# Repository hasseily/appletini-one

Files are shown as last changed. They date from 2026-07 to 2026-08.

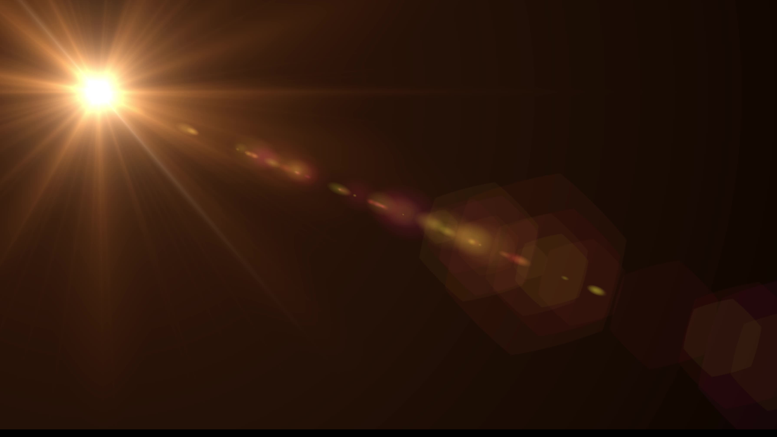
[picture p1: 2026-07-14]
Assets/Bezels/bezel-optical-lens.png

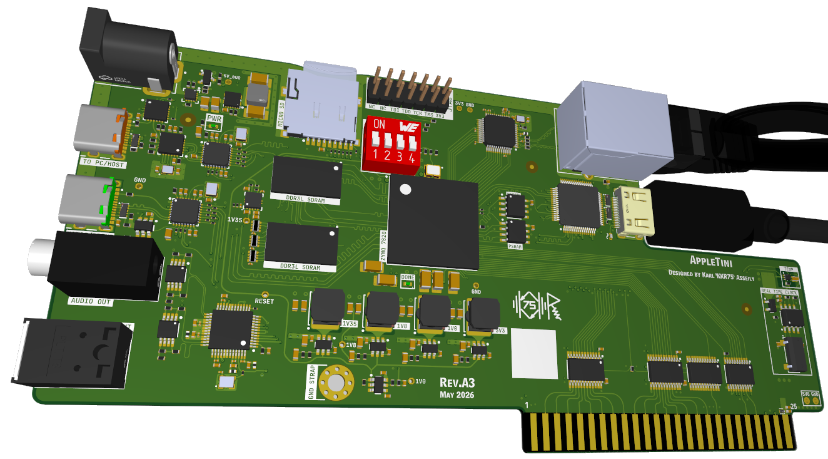
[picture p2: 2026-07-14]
Assets/Appletini_3D.png

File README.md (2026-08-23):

# Appletini One

Appletini One is firmware and FPGA logic for an Apple //e expansion card built
around a Xilinx Zynq-7020. The PL handles cycle-sensitive Apple bus behavior;
the two ARM cores provide storage, video rendering, USB services, configuration,
and higher-level peripheral emulation.

## Virtual Hardware

- SmartPort storage and Disk II disk-image support
- Selectable slot-5 coprocessor: PCPI-compatible Z80 Appli-Card or 640 KB ALF AD8088 Plus
- Phasor/Mockingboard audio with two SSI-263AP (SC-02) speech chips
- Uthernet II compatible W5100 interface
- Mouse card, RamWorks memory, and no-slot clock
- VidHD-compatible video controls and SuperSprite graphics
- Accurate Apple //e video capture, HDMI output, borders, scanlines, and profiles
- USB keyboard, mouse, storage, firmware update, and SuperDuperDisplay support

The boot menu configures virtual cards, storage images, video, audio, networking,
USB behavior, and named profiles. Settings are stored on the card's SD volume.

## Repository Layout

- `hdl/`: SystemVerilog/VHDL sources and the active source manifest
- `hdl/constraints/`: board pin and timing constraints
- `ps_sources/`: golden updater, frontend, renderer, and shared bare-metal code
- `scripts/`: Vivado, Vitis, image-generation, programming, and regression tools
- `software/`: Apple II demos, diagnostics, and disk images
- `tools/mcp/`: serial control server for automated Apple II interaction
- `Datasheets/`: hardware and compatibility references
- `third_party/`: external components with their own license terms

`project/` and `vitis_workspace/` are generated and are not source directories.

## Toolchain

- Vivado 2025.2
- Vitis 2025.2
- A compatible JTAG programmer for hardware generation or direct flash recovery
- UART access for diagnostics and serial firmware recovery

## Build

Generate the Vivado project, build the bitstream/XSA, and build all Vitis apps:

```bat
vivado -mode batch -source scripts/create_project.tcl
vivado -mode batch -source scripts/build_and_export_xsa.tcl
vitis -s .\scripts\create_vitis_workspace.py
```

Create the two flash images:

```bat
scripts\make_boot_bin.bat
scripts\make_firmware_bin.bat
```

- `BOOT.BIN` contains the FSBL and golden updater.
- `FIRMWARE.BIN` contains the FSBL, PL bitstream, CPU1 renderer, and frontend.

C-only frontend changes require a Vitis rebuild and a new `FIRMWARE.BIN`; HDL,
clock, AXI, or constraint changes require the full Vivado and Vitis sequence.

See [README_VIVADO.md](README_VIVADO.md) for hardware-build details and
[README_BOOT_UPDATE.md](README_BOOT_UPDATE.md) for the flash layout and recovery
flow. Script-specific usage is in [scripts/SCRIPTS_README.md](scripts/SCRIPTS_README.md).

## Firmware Installation

The normal update path is:

1. Put `FIRMWARE.BIN` in the root of the card's SD volume.
2. Reboot into the golden updater.
3. Let the updater program and verify the firmware slot.
4. Confirm that it renames the file to `FIRMWARE.OK` and boots the frontend.

Serial recovery is available through the golden monitor:

```bat
python scripts\serial_firmware_update.py .\FIRMWARE.BIN --port COM3 --reboot-golden
```

Direct QSPI programming scripts are available for recovery and bring-up:

```bat
scripts\program_boot.bat .\BOOT.BIN
scripts\program_firmware_slot.bat .\FIRMWARE.BIN
```

## Validation

Source-level regression scripts live in `scripts/test_*.py`. Hardware behavior
is additionally checked through UART/JTAG and the serial MCP tools. Generated
images report their firmware, golden-updater, and RTL versions at runtime so a
mixed build is visible immediately.

The Appli-Card interface and demo media are documented in
[README_APPLICARD.md](README_APPLICARD.md). Apple II software can identify the
card through the documented SmartPort interface described in
[README_APPLETINI_DETECTION.md](README_APPLETINI_DETECTION.md).

## Licensing

External components and bundled compatibility software retain their own
license and attribution files. No repository-wide license is granted by this
README.

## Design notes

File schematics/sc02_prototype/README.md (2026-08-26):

# SC-02 Prototype Schematic Archive

This folder preserves the seven-sheet SC-02 prototype schematic in open,
text-based forms.  The supplied Altium smart PDF stays here as the fixed source
record.

The conversion is automated.  It never decides that crossing lines connect.
It takes component, pin, net, and label membership from the PDF bookmark tree.

## Source record

- File: `sc-02_Final_Schematic_V1.00.pdf`
- Size: 5,080,426 bytes
- SHA-256:
  `d0e05ea01fc5e823571e140fce5ce9f12a48f1993484d683f075151382adba35`
- PDF pages: 7
- Original sheet names: `analog_1.SchDoc`, `analog_2.SchDoc`, and
  `digital_1.SchDoc` through `digital_5.SchDoc`

## Which file to use

- Use `sc02_schematic.json` for exact extracted data and source evidence.
- Use `connectivity/sc02_pin_net_memberships.csv` for a flat pin/net table.
- Use `source_svg/` for the full drawn sheets in plain XML, with searchable
  text and embedded images.
- Open `kicad/sc02_prototype.kicad_pro` for a KiCad 10 connection view.
- Use `connectivity/*.dot` or `connectivity_svg/*.svg` for component/net
  graphs.
- Use the copied PDF when the exact source rendering matters.

## What the archive contains

The canonical JSON records:

- 785 component-unit entries and 484 physical component references;
- 3,213 explicit component pins;
- 208 unique implicit package pins and all 306 of their sheet memberships;
- 1,257 sheet net entries and 1,088 distinct exact net names;
- 3,519 sheet pin/net memberships over 3,421 unique connected pin IDs;
- 718 net-label occurrences over 383 labeled sheet nets;
- 15,330 styled page-text spans;
- every component, explicit-pin, and hidden net-label tag anchor; and
- a SHA-256 over the sorted connection tuples:
  `b13d422a2b0338a3080a5e16b092374ad5afddbb8699cf532b3d418d7cdd208f`.

The PDF exposes one hidden net-label tag per labeled sheet net, not one per
drawn label.  The archive therefore keeps all 718 label occurrences, the 383
hidden tag anchors, every exact visible-text candidate, and the full styled
page text as separate facts.  Strict matching resolves 209 label positions;
509 stay marked unresolved.  The generator does not guess their positions.

## KiCad project

The KiCad files form a valid KiCad 10 project with one index sheet and seven
child sheets.  Each source component unit gets a generated generic symbol.
Each pin gets its exact source ID, pin number, net name, and implicit-pin flag
as symbol fields.  Symbol and pin placement keeps the source anchors.  A global
label sits on each pin, which gives KiCad the exact extracted net list without
drawn-wire guesses.

KiCad 10.0.5 checked a disposable copy of the project and its symbol library.
The exported XML net list contains exactly 785 components, 1,088 nets, and
3,519 nodes, with no unconnected nodes.  It also exported the index and all
seven child sheets as SVG.  `kicad_validation.json` binds that result to the
SHA-256 of the canonical JSON and a SHA-256 over all 11 KiCad files.  The
archive test checks both links, so a changed model or project cannot keep a
stale pass result.

KiCad reports two expected ERC warning classes:

- 785 off-grid warnings, because the generated symbols keep the exact PDF
  anchor positions; and
- 414 one-pin-net warnings, matching the 414 extracted nets that have one
  membership.

It also warns about annotation because 556 exact source unit names, such as
`U117A` and `C10B`, do not use KiCad's normal trailing-number form.  The archive
keeps those source names unchanged.  They are unique.

This is an electrical archive, not a recovered Altium design.  The generic
KiCad symbol bodies do not claim to restore the source symbol art, part types,
pin electrical types, or route shapes.  Use `source_svg/` for the drawn view.

## Rebuild

Run these commands from the repository root:

```powershell
python -m pip install -r scripts\requirements-sc02-schematic.txt
npm ci --prefix scripts\sc02_dot_renderer
python scripts\sc02_schematic_extract.py schematics\sc02_prototype\sc-02_Final_Schematic_V1.00.pdf --output schematics\sc02_prototype\sc02_schematic.json
python scripts\sc02_pdf_to_svg.py schematics\sc02_prototype\sc-02_Final_Schematic_V1.00.pdf --model schematics\sc02_prototype\sc02_schematic.json --output-dir schematics\sc02_prototype\source_svg
python scripts\sc02_connectivity_generate.py schematics\sc02_prototype\sc02_schematic.json --output-dir schematics\sc02_prototype\connectivity
python scripts\sc02_kicad_generate.py schematics\sc02_prototype\sc02_schematic.json --output-dir schematics\sc02_prototype\kicad
node scripts\sc02_dot_to_svg.mjs schematics\sc02_prototype\connectivity schematics\sc02_prototype\connectivity_svg
python scripts\sc02_archive_manifest.py schematics\sc02_prototype --output schematics\sc02_prototype\MANIFEST.sha256
```

The pinned packages are PyMuPDF 1.27.2.3 and `@viz-js/viz` 3.25.0, which embeds
Graphviz 14.1.3.  The DOT renderer loads that checked local package by default
and stops if its Graphviz version differs.  Another `dot -Tsvg` build can show
the DOT files, but it need not produce the same SVG bytes.

Run the archive checks with:

```powershell
python scripts\test_sc02_schematic_archive.py
python scripts\test_sc02_schematic_archive.py --regenerate
```

The second command rebuilds the JSON, source SVG, CSV/DOT, Graphviz SVG, and
KiCad files in a temporary folder and requires byte-for-byte matches.

## Limits

The smart PDF does not contain the original `.SchDoc`, Altium libraries, PCB
data, simulation models, design rules, fitted-part database, or a reliable list
of production-board changes.  It also does not turn nearby value, footprint,
or population text into typed part fields.  The archive keeps that text and the
drawn sheets, but it does not assign meaning that the PDF does not state in its
structured data.

The source sheets print historical `Q:\altium files\...` paths in their title
blocks.  The JSON and source SVG keep that visible source text on purpose.
They do not store the path of the checkout or the host that ran the extractor.

The archive cannot settle prototype-versus-production questions, such as the
final P2/R301 population, without another source.  It does remove the need to
decode the PDF again for the data that the PDF does expose.

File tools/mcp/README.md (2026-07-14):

# Appletini MCP server

Exposes a live Apple II (via the Appletini card) as MCP tools:

    MCP client -> appletini_mcp.py -> serial UART -> ARM firmware
               -> FPGA fabric -> Apple II bus

## Tools

| Tool | What it does |
| --- | --- |
| `apple2_screen_text` | The live text screen as plain text (40/80 col auto). Reads the DDR write-mirror shadow -- zero bus impact, works under graphics modes (where error messages hide). |
| `apple2_peek` | Hex dump of Apple main RAM (from the shadow; mirrors writes since power-on). |
| `apple2_soft_switches` | Decoded //e soft-switch state + RamWorks bank. |
| `apple2_machine_status` | Machine id, aux-provide, RamWorks, physical-aux-card probe, firmware status. |
| `apple2_health` | Serve-path counters (write-queue drops / deadline misses / lost cycles) -- all must be zero. |
| `apple2_bus_trace` | Recent bus cycles from the trace ring, with history offset. |
| `apple2_menu_key` | Drive the Appletini config menu remotely. |
| `apple2_console` | Escape hatch: any firmware console command (`help` lists them). |

## Setup

```
pip install mcp pyserial
```

The firmware console is a single shared channel: close any terminal
program (PuTTY, TeraTerm) holding the COM port first.

Register with Claude Code (adjust the port):

```
claude mcp add appletini -e APPLETINI_PORT=COM5 -- python tools/mcp/appletini_mcp.py
```

Or in an `.mcp.json`:

```json
{
  "mcpServers": {
    "appletini": {
      "command": "python",
      "args": ["tools/mcp/appletini_mcp.py"],
      "env": { "APPLETINI_PORT": "COM5" }
    }
  }
}
```

## Notes and limits

- `reboot`/`reset` console commands restart the Appletini firmware,
  not the Apple II.
- `apple2_menu_key` drives only the Appletini configuration menu; the MCP
  server does not inject Apple keyboard input.
- The memory shadows mirror *writes* since power-on: ROM regions and
  never-written RAM read as zero in `apple2_peek`.

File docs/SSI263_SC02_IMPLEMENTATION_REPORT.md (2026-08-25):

# Dual SSI-263 / SC-02 Phasor implementation report

## Result and scope

The branch now uses two independent SSI-263AP models for Phasor speech. The
active source closure contains no SC-01 core, ROM, coefficient set, phone map,
timing rule, decoder, Votrax interface, or compatibility path. Both speech
sockets instantiate `ssi263_voice`, which joins the native SC-02 digital core
to the ideal schematic charge model.

The sheet-5 control path now follows U37/U38 and the three timed cross-NAND
latches. PW0/PW1 are set-only states, while PW1 gates the slot-2 PW3 load of
the CTRL/TPARM1 result. The source also removes the prior
sound-driven shortcuts: it has no invented stop mask, abstract phone-class
source gate, direct ROM/inverse fricative-switch pair, guessed C381 high-pass,
or three-bit output-level shift. Source and simulation closure are complete.
The prior PW1-gate firmware still exposed an FPGA-only zero seed in the
unreset U65/U64 transitioned-inflection counters. That made the first phones
rise from the lowest pitch toward the programmed target. It is rejected.
Build `20260825T171810Z-2a4a8c64-full` supplies its replacement for the next
hardware listen.

The target version remains `F0.9.99`.

## Source basis

The implementation separates chip and card proof:

- the supplied SC-02 schematic defines the selector, transition, excitation,
  route, and ideal switched-capacitor paths;
- the supplied SSI-263 ROM defines the 64 by 8 phone table;
- the SSI-263A data sheet and programming guide define registers, public timing,
  D7, A/R, DR modes, and P/AP reset behavior;
- the original Applied Engineering Phasor manual, board photos, `mb-audit`, and
  real-card AppleWin decode define A5/A6, channel A/B, VIA, IRQ, Q3, and DIV2
  behavior.

The SC-02 reconstruction includes external changes made for its discrete board.
The chip model excludes its AD817, LM386, speaker, pots, and line-driver stages.

## SC-01 removal

The speech source closure now consists of:

```text
hdl/apple/ssi263_sc02_rom.mem
hdl/apple/ssi263_xck_ce.sv
hdl/apple/ssi263_sc02_core.sv
hdl/apple/ssi263_sc02_audio.sv
hdl/apple/ssi263_voice.sv
hdl/apple/mockingboard.sv
```

No tracked SC-01 or Votrax source file remains, and neither name appears as a
speech implementation input in `hdl/hdl_sources.txt`. VIA PCR and ORB state no
longer select a hidden SC-01/Votrax path. Software written only for an SC-01
interface will not speak through this Phasor model.

## ROM identity and addressing

The imported source is:

```text
C:\Users\hasse\OneDrive\Documents\Apple2\Appletini\Mockingboard\SC-02\ssi263a.bin
size:    2,048 bytes
CRC32:   CC0A72EE
SHA-256: 9C3BBA73319E1ED3652C85DAC19874DF04CBB72E62FDD63D6CBD7B34FF81F941
```

The active table is the first 512 bytes. The remaining 1,536 source bytes are
zero. The address is exact:

```text
rom_address = {phone[5:0], selector[2:0]}
            = ((phone & 0x3f) << 3) | (selector & 7)
```

Selectors 0-6 target F1, F2, F2 resonance, shared F3/F4, filter amplitude,
voice amplitude, and fricative amplitude. Selector 4 substitutes the host
amplitude for the upper ROM nibble. Selector 7 writes no parameter state. The
low nibble remains a set of circuit controls; the model does not turn it into
SC-01-like phone traits.

Sheet 5 gives these timed rules:

```text
decoded /PHO_WRITE is high at U29A while the phone write is active
U37 advances on U29A's falling edge at write assertion or DURCLK rise
DONE_RB holds U37 at zero while its low nibble is zero; that hold wins a clock
U38 equal = U37.low == (TPARM0 ? 2 : 6)
PW0 set = U38_equal AND WR_SEL0
PW1 set = U38_equal AND WR_SEL1
PW0/PW1 clear while /PHO_WRITE is low, otherwise hold
PW2 = selector-2 TPARM2
PW5 = NOT selector-2 TPARM2
PW3 loads (latched_CTRL OR NOT TPARM1)
    only when PW1 AND WR_SEL2; otherwise it holds
```

TPARM0 chooses the comparator delay; it does not become PW0 or PW1 data.
U38 pin 6 reaches only U32A pin 2 and U33A pin 1. PW1 from U33D pin 11
reaches U11C pin 11 and U11A pin 8, so it qualifies the U34 load independently
of U38. TPARM1 reaches PW3 through U180C/U30E/U11/U34 only on that load.
Static per-selector ROM assignments do not reproduce these held states.

U21B, U28, U29A, U36, U37, and U23B now run as the sheet-5 circuit rather
than from a phoneme-end timer. U21B Q is `RATECLK/2`; its complement clocks
U28 and U36. U28 loads `12+D`, counts only on the Q-falling half-cycle, and
holds terminal count through the Q-high half-cycle. Thus:

```text
DURCLK period = (4-D) * 256 * (16-R) effective FASTCLK ticks
frame period  =          4096 * (16-R) effective FASTCLK ticks
phoneme       = (4-D) * 4096 * (16-R) effective FASTCLK ticks
phoneme       = 16 DURCLK rises
```

U28, U36, and U37 have no phone-active or power-down clock gate. A phone
write resets U36 and drives the shared U29A level; it does not force an
unconditional U28 reload. U36 enters low-nibble `F` on its fifteenth count
after reset and requests DONE in retained frame mode. In retained phoneme
mode, the sixteenth DURCLK wraps U37 from `F` to zero and requests DONE.
Phone-write reset, CTL/power-down reset, and frame-mode WR1/WR2 acknowledge
reset U23B with priority over a same-edge request. DR=00 keeps the prior
frame/phoneme selection.

## Clock and selector correction

Both Phasor sockets assert DIV2. Original-board evidence shows SSI pin 23 tied
to the pin 24 +5 V rail on both sockets. The model feeds both XCK inputs from
Apple Q3, about 2.045 MHz, and the SSI DIV2 stage produces an effective rate of
about 1.023 MHz. A card-mode change leaves this clock alone. The Phasor's AY
clock doubling is a separate circuit and does not double SSI XCK.

The direct pin-22 Q3 trace is the only source-supported route that fits the
required raw clock with DIV2 high. A scope or continuity test can add physical
proof, but the implementation does not replace it with a tuned oscillator.

The prior selector scan included one extra divide-by-two. The corrected trace
is:

- U44A/U44B divide FASTCLK by four;
- U45 Q1 and Q2 drive the WRITE/LATCH timing gates;
- U45 Q3/Q4/Q5 drive SEL0/SEL1/SEL2;
- one selector slot spans four SLOWCLK edges, or sixteen effective FASTCLK
  ticks;
- all eight selector slots span 128 effective FASTCLK ticks.

The transition path now keeps the four storage terms drawn on sheet 4 for all
eight selectors: U89 `RESA`, U88 `RESB`, U90 `RESC`, and U87 direction carry.
An `A_CLR` setup holds A, writes `B=(target-A) mod 16`, writes `C=8`, and stores
`CY=(target>=A)`. Each later permitted pulse adds B to C. An upward transition
increments A on carry; a downward transition decrements A on no carry;
`RESA_EQUALS` stops the write path at the target.

The prototype U96 route is also explicit. Slots 0, 1, and 3 use
`TCEDGE AND U32B`; slot 2 uses `TCEDGE`; slot 4 uses
`DUREDGE AND U166B./Q AND AMP_NONZERO`; slots 5 and 6 use `PW0 AND RATEEDGE`
and `PW1 AND RATEEDGE`; slot 7 is grounded. The fitted prototype state grounds the
P2/R301 RATE=F option. A host write owns a same-edge data-path collision.

## Exact source circuit

### U60 glottal path

U60 `/RST` and CET are tied high, while U53C feeds `/VOICED` back to CEP. P0
and P1 are tied high, P2 is grounded, and P3 is tied high. U34A therefore
loads `1011` after the applicable U61/U62 edge. Normal Phi1 clocks advance
`11..15`; at 15,
`/VOICED` lowers CEP and U60 holds terminal count until the next parallel load.
There is no asynchronous clear and no free-running wrap.

U118A connects U201 to the selected C205 voice-amplitude bank at the same Phi1
boundary. The model uses U60's post-clock state for that transfer: `14->15`
selects AGND immediately, while a `15->11` load selects the positive source
immediately. This fixes the counter start, stop, and source edge from the
drawn pins; it is not a pitch or timbre setting.

U61 `/CLR` follows the physical `T/PD_/RST` net. A low level clears the two
U61 stages and removes a pending U34 load, but leaves U60 unchanged.

The drawing includes POT3 in the U3C/U117/U3B voiced-source path but gives no
wiper setting. `VOICE_TRIM_U116_STEP_Q16` keeps that one physical calibration
value explicit. Its provisional hardware-test default is `2048`, one
thirty-second of the former normalized rail step. POT3 still affects only the
drawn voiced-source path. The resistor-defined fricative source remains `301`
Q16 and no phone selects either level. A same-vector real-chip capture is still
needed to set the final wiper value.

### U75 and CD4006 U73

U75 counts on U41C rising edges. P0 is high and P1/P2/P3 are grounded. Its
terminal-load path jams one, so the steady counter sequence is `1..15`.
The post-rise counter state forms:

```text
U42C = NOT(U75.Q2 OR U75.Q3)
```

The CD4006 sections shift on the following U41C falling edge:

```text
D1 input = D3+4
D2 input = D4+5
D3 input = D2+5
D4 input = U42C XOR D1+4 XOR D2+5 XOR D4+4 XOR D4+5
```

The schematic source is D3+4, not D4+5. The final gate is:

```text
U104C     = PW3 AND U62./Q
FRICATIVE = NOT(D3+4 OR U104C)
             AND (U62./Q OR VOICE_AMP_ZERO)
```

The U41C edge advances the recurrence without `phone_active`, CTL, a decoded
phone class, or a stop flag. Voice amplitude zero and the drawn PW3/U62 term
provide the source gating.

### U68/U85 U62 reset path

The source now follows the sheet-6 amplitude counter instead of
`PW2 && !PW3` muting:

- U68 runs as a CD4029 binary counter with B/D tied high and grounded jam
  inputs;
- Q2-Q4 form `AMPCT1..3`, and their NOR is `AMPCT_ZERO`;
- `U104C = PW3 AND U62./Q`, with its inverse supplying `AMPCT0`;
- the voice- and fricative-amplitude zero terms control the shown direction and
  enable logic;
- the complete gated SEL2 level clocks U68, including a rising edge caused by
  a gate opening while SEL2 is high;
- U68 `/CO` and U104C feed U85C, whose output resets U62.

This path now decides the source envelope and U62 state. There is no special
B/D/P/T/K mute and no synthetic stop burst.

### Parameter and phase latch layers

The selector path has three distinct storage layers. U89 holds RESA for each
selector. U106-U114 follow only during that selector's LATCH window, eight
FASTCLK ticks after WRITE. U170-U176 then pass the first-stage code only while
the matching capacitor bank is grounded: F1/F3/voice in Phi0_X and
F2/F2-res/F4/fricative in Phi1_X.

U111 holds raw filter amplitude. U70 gates its four bits with
`{AMPCT3, AMPCT2, AMPCT1, AMPCT0}`, and U206 captures that result only on the
positive Phi0 edge. It does not follow later U111 or AMPCT changes in Phi0.

### U20B/U112/U166 route state

The two fricative routes are not one ROM bit and its live complement.

The gated WR_SEL2 path clocks TPARM3 into U20B. Its clock gate contains the
drawn PW0, PW1, PW2, `AMPCT_ZERO`, and `FRIC_AMP_ZERO` terms. U112 remains
transparent while Phi1_X is high and supplies `FRIC1_SW` from U20B. U166A
samples `/U20B` on the positive Phi0_X edge and holds `FRIC2_SW`. Their
different clocks preserve the route handoff drawn on sheet 7.

## Ideal switched-capacitor implementation

The model keeps one serial tract:

```text
VOICE -> F1 -> F2(+FRIC1) -> F3 -> F4 -> F5(+FRIC2) -> U146 -> U148
```

The implementation does not turn a four-switch bank into one code-to-gain
table. It keeps one source-plate voltage for each switched capacitor. For a
final switch mask `M`, source target `t`, retained plates `h[i]`, and feedback
capacitor `Cf`, one atomic topology event is:

```text
delta_out = -sum(i in M, C[i] * (t - h[i])) / Cf
h[i]      = t for i in M; every open h[i] holds
```

This covers source changes, switch changes, reset precharge, reconnects, and
multi-bit changes such as `7->8`. A code change at a steady source creates no
FRIC2 impulse; its final complementary switch mask weights the next real
source edge.

The per-switch values are copied from the drawing:

| Bank | Switched capacitors, low bit first (pF) | Fixed or feedback capacitor (pF) |
| --- | --- | ---: |
| U116 voice amplitude | 220, 430, 870, 1800 | C205=3300 |
| U157 FRIC1 amplitude | 270, 512, 1068, 2160 | C133=3900 |
| F1 frequency | 160, 330, 660, 1300 | fixed 250; feedback 11500 |
| F2 resonance | 220, 430, 870, 1800 | fixed load 200; feedback 6800 |
| F2 frequency | 280, 560, 1120, 2300 | fixed 500; feedback 6800 |
| F3 frequency | 210, 420, 820, 1640 | fixed 820; feedback 4700 |
| F4 frequency | 200, 400, 820, 1620 | fixed 1670; feedback 4300 |
| U146 filter amplitude | 76, 150, 300, 600 | C172+C173=2750 |
| U152 FRIC2 input | 270, 530, 1082, 2160 | C153=3900 |

For state `pN` at the first integrator and `yN` at the second, the phase-entry
work uses the raw capacitor equations, not rounded pole values:

```text
p1' = [11500*p1 + 2700*(y1-x) - 2700*x] / 11700
y1' = y1 - [250*(p1'-hfix) + sum F1 Ci*(p1'-hi)] / 11500

p2' = [6800*p2 + 4700*(y2-y1) + sum RES Ci*ri]
      / [7000 + sum RES Ci]
y2' = y2 - [500*(p2'-hfix) + sum F2 Ci*(p2'-hi)
            - 1000*(Lold-Lnew)] / 6800

p3' = [4700*p3 + 3900*(y3-y2) + 2000*(y1old-y1new)] / 4900
y3' = y3 - [820*(p3'-hfix) + sum F3 Ci*(p3'-hi)] / 4700

p4' = [4300*p4 + 4700*(y4-y3)] / 4500
y4' = y4 - [1670*(p4'-hfix) + sum F4 Ci*(p4'-hi)] / 4300

p5' = [3450*p5 + 4700*(y5-y4)
       - 1150*delta_C150 - 3700*delta_C151] / 3730
y5' = y5 - 4700*(p5'-hfix) / 3450
```

The mid-Phi1 C128 path applies `-5400*delta_x/11700` to F1. C127 then consumes
that same event's F1 change, not the prior event. U157 resets in Phi1 and feeds
F2 through C143 in Phi0. U152 and U154 keep state and follow their drawn
`12/13`, `19/13`, and `31/13` edge recurrences. C150 and C151 see only U152
changes while Phi1 is active; C151 keeps its source plate while its switch is
open. U146 has a 2700 pF held path plus the four filter-amplitude switches.
CLOSURE copies its completed value to U148. Phone completion does not mute or
clear the tract.

State uses a normalized signed Q16 voltage scale in wider signed registers.
Each physical division rounds once to the nearest signed integer and saturates
only at the 24-bit state rail. There are no Q14 pole or gain tables. The PCM
boundary shifts once from Q16 to signed Q15; it adds no output gain. The
removed `LINE_OUTPUT_SHIFT=3` had no schematic basis.

The card now treats this PCM value as the reconstructed low-level U148 `Line
Out` node. Each SSI socket then enters one `phasor_ssi263_output_stage` before
the PSG mixer. That stage applies a common saturating `x32` gain and registers
the result for one 7.5 ns fabric cycle. It preserves the prior voiced product:

```text
POT3:             2048
card gain:        32
voiced product:   2048 * 32 = 65536
fricative source: 301 * 32 = 9632
```

This separates the adjustable voice/noise balance from total output level.
The common stage raises the unchanged fricative path by 30.1 dB while leaving
the former voiced scale in place. It sits before the speech-plus-PSG sum, so it
cannot change AY/YM gain. The values are a hardware-test calibration, not a
claim that the schematic fixes either pot setting.

The FPGA arithmetic keeps the charge result exact for the drawn integer
capacitors. Six shared 25-by-16 signed lanes form each numerator. The only live
denominators are the 28 schematic capacitance sums. For each, a 37-bit
reciprocal product returns the exact quotient or one less; a registered
`(q+1)*d` product makes the final correction. One analog stage takes nine
fabric clocks. Phi1 and code jobs need at most 101 clocks, and the worst Phi0
job needs 110 clocks before the next event can pop. A 16-entry FIFO preserves
event order. Routed out-of-context verification at a 7.500 ns fabric period
uses 11 DSP48E1 blocks and reports `+0.641 ns` WNS. The one full-card build for
this hardware test uses 26 DSP48E1 blocks in all, including 22 for the two SSI
engines, and reports `+0.039 ns` WNS, `+0.061 ns` WHS, and `+0.265 ns` WPWS.
The current cold-pitch-seed full-card build still uses 26 DSP48E1 blocks and
reports `+0.015 ns` WNS, `+0.019 ns` WHS, and `+0.265 ns` WPWS.

The chip drawing includes C381 but omits its external load. It therefore does
not define a high-pass pole. The tract exports reconstructed U148 without the
old 255/256 digital high-pass, and the present card stage adds gain only. A
later board model may add the coupling and load response only after the load
and capture point are known.

## Original Phasor integration

The card has two fixed AP-revision instances:

| Select | Physical role | Phasor output | Request route |
| --- | --- | --- | --- |
| A5 | upper, secondary SSI socket | channel A | matching VIA CA1 in Mockingboard mode; direct IRQ in native mode |
| A6 | lower, primary SSI socket | channel B | matching VIA CA1 in Mockingboard mode; direct IRQ in native mode |

The bus and channel rules are:

- A5 writes only the channel-A chip; A6 writes only the channel-B chip;
- A5+A6 writes both chips;
- native reads expose the selected chip's D7, with A5 priority on a dual read;
- request, register, transition, excitation, filter, and audio state remain
  independent;
- Echo+ masks the SSI host route without clearing either chip;
- the FPGA maps channel A to left and channel B to right, with no speech mono
  pre-sum; the original card itself names the outputs A and B, not left/right;
- both chips use the same Q3 edge stream and asserted DIV2 strap, independent
  of Phasor mode.

The prior firmware also forced a hidden post-card warmth value of `+8` over
the complete PSG and SSI mix. That filter is not part of either schematic and
reduced speech treble before the DAC. The reset and firmware default are now
neutral (`0`). Explicit user bass, mid, treble, and volume controls remain
optional board-output processing; keep them at zero for a direct SSI listen.

## Card-enable and reset behavior

`card_enabled` now masks only the virtual card boundary:

- it blocks new host writes;
- it removes D7 and A/R from the Apple bus;
- it mutes the exported speech sample;
- it does not reset the core, source registers, counters, routes, or filter
  state.

Apple RES drives the AP `PD/RST` input. The global FPGA `rstn` still provides a
defined emulator start. Treating a menu or slot-disable flag as a die reset did
not match original wiring and has been removed.

## Removed non-schematic behavior

The current engine has none of these earlier rules:

- `stop_class` or `PW2 && !PW3` source suppression;
- `phone_voiced`, `phone_fricative`, or equivalent phone traits;
- abstract `voiced` or `fricative` gates into the audio engine;
- `phone_active` source gating or tail muting;
- an inverted D4+5 noise source tap;
- direct `FRIC1_SW=ROMbit` and `FRIC2_SW=!ROMbit` assignments;
- a 255/256 C381 high-pass estimate;
- `LINE_OUTPUT_SHIFT=3`;
- the hidden forced `+8` warmth filter;
- an asynchronous U60 clear, load-to-zero rule, or free-running terminal wrap;
- a phone-specific burst, gain, pitch, presence, or resonance adjustment.

Earlier listen-test firmware used one or more of these discarded paths. All of
those images are rejected. Their paths and hashes are intentionally absent from
this report so that none can be mistaken for the next test image.

## Deterministic power-up state

An FPGA needs known power-up bits even where the reconstructed chip circuit has
no useful reset. The model uses these repeatable seeds:

```text
U60       = F
U75       = F
U73 D1    = 0001
U73 D2    = 00000
U73 D3    = 0000
U73 D4    = 00000
U68       = 0
U20B      = 0
U28       = F
U36 low   = 0
U37 low   = 0
U65/U64   = current {I10:I6,000} target at the first transitioned CTL wake
FRIC1_SW  = 0
FRIC2_SW  = 1
filter and charge state = 0
```

These values make simulation, synthesis, and hardware runs repeatable. They do
not assert that all SSI-263AP dies start at the same unreset state. Verification
must compare the recurrence after initialization, not use the seed as proof of
silicon power-up.

U65/U64 have no reset pin in the reconstruction. Resetting them to zero in the
FPGA turned that arbitrary state into a repeatable low-to-high glide. Each
virtual die now adopts its current aligned I10:I6 target once, on the first CTL
high-to-low wake that exposes transitioned pitch. Phone writes, IS/RE writes,
later CTL wakes, and SSI `PD/RST` do not reload it. Immediate and frame modes
leave the seed armed; DR=00 consumes it only when it retains transitioned
pitch. After the one initialization edge, all rise and fall movement still
comes from the drawn U66 rate path. This is a deterministic FPGA policy for an
undefined chip power-up state, not a claimed schematic reset connection.

## Verification status

The source corrections now cover the full known digital path. Tests based on
phone classes, stop muting, or guessed C381/output terms are not proof. The
final pre-build suite now checks:

- ROM identity, padding, and all 64 by 8 addresses;
- register, D7, A/R, repeat, DR, CTL, AP reset, and collision traces;
- one-time U65/U64 cold-state initialization, five-phone fixed-pitch hold,
  later U66 rise/fall, first-wake/reset collision priority, global rearm, and
  independent staggered A5/A6 seeds;
- U44/U45 selector cadence;
- upward and downward U83/U84 DDA vectors and the full prototype U96 route;
- sheet-5 timed PW0/PW1, PW2/PW5 polarity, and PW1-gated CTRL/TPARM1 load into
  `PW3`;
- all 64 rate/duration U28 recurrences, sixteen DURCLK rises per full phone,
  U36 count-15 frame response, U37 wrap phoneme response, and reset collisions;
- U61 `PD/RST` clear without U60 clear, U60 load to 11, `11..15`, terminal hold,
  and post-clock Phi1 source selection;
- U75 rising count, U73 falling shift, post-rise U42C, feedback taps, D3+4
  source, and the full FRICATIVE gate;
- U68/U85 count, direction, terminal, and U62 reset traces;
- U20B/U112/U166 clock and hold behavior;
- all filter cap tables, ratios, signs, route histories, and persistent state;
- the `2048` POT3 setting, unchanged `301` fricative divider, exact `x32` card
  gain, both saturation edges, and immediate card-disable masking;
- no non-schematic CTL hard clamp on the source or PCM output;
- boundary-only `card_enabled` behavior;
- A5/A6 decode, both VIA CA1 paths, native IRQ, A/B isolation, and two-chip
  concurrent speech;
- source and synthesis closure with no SC-01 or Votrax implementation.

The current source checkpoint passes:

- 54 ROM, interface, formula, selector, duration, DONE, DDA, and U96 reference
  tests;
- the raw-Q3 XCK edge bench and the complete native core bench;
- 4,032 exact-divider vectors across all 28 live denominators;
- 204,210,708 checks over all 64 phone rows plus the natural ten-phone
  `HF EH1 L O OU PA E N D PA` sequence at the physical fabric/Q3/DIV2 rates;
- 15 Phasor source and decode tests;
- 17 exact card-output checks across zero, sign, gain, both saturation edges,
  and card masking;
- 77 dual-card checks for A5/A6, channel A/B, request, mode, reset, both RESA
  latch layers, row `$01`, simultaneous audio, both engine-overrun flags, and
  separate card-stage clip flags, including staggered independent pitch seeds.

The phone sweep checks the timed PW, DDA, route, and output invariants without
assuming that every settled parameter must equal its ROM target in one scan.
Source closure finds zero tracked or production SC-01/Votrax paths.

## Fidelity limits

| Area | Current claim | Limit |
| --- | --- | --- |
| ROM | Exact to the supplied binary | Does not prove the binary matches every mask-ROM revision |
| Register and timing behavior | Source-derived synchronous model with independent collision and boundary vectors | CMOS gate delay and pin captures remain unmodeled |
| Selector and transition | Drawn U44/U45 cadence, U83/U84 DDA, and prototype U96 routes | FPGA enables do not model CMOS propagation delay |
| U60/U68/U75/U73 routes | Drawn counter, gate, and held-state recurrences | Deterministic seeds are emulator choices for unreset state |
| Filter topology and ratios | Ideal schematic charge equations with one retained state per switch | Q16 voltage units and finite 24-bit state width add small numeric error |
| Source and output level | Adjustable POT3 at 1/32 rail plus common x32 per-socket card gain | Final POT3, card gain, and absolute AO voltage need a same-vector real-chip capture |
| Nonideal analog behavior | Not modeled | LF356 slew/bandwidth, CD4016 resistance and charge injection, parasitics, tolerance, temperature, and chip spread remain |
| C381 | Omitted from chip output | External load and desired capture point are not given |
| Phasor clock | Q3 plus DIV2-high source route | Pin-22 continuity or scope capture remains useful physical proof |

The ideal model can follow every shown capacitor and switch while still
differing from real silicon. Do not change a drawn ratio to hide that gap. Add
a nonideal term only when the part model and same-vector capture support it.

## Firmware and build status

The version remains `F0.9.99`. Every image before the U65/U64 cold-state fix is
rejected. The replacement comes from one clean, full, non-incremental Vivado
implementation. Its final checkpoint has positive setup, hold, and pulse-width
slack, which is the current hardware-listen gate. The normal `+0.300 ns`
release margin remains a later timing task.

```text
Current pre-build suite: passed
Current full build:      20260825T171810Z-2a4a8c64-full; run once
Source commit:           2a4a8c645c92c0340d9e7620274184e413a0641a
Build mode:              full, clean tree, no incremental reference
Route and bus skew:      PASS; 0 route errors; +5.431 ns bus-skew slack
Timing:                  WNS +0.015; WHS +0.019; WPWS +0.265 ns
Failing/unconstrained:   0 setup, hold, pulse-width, and unconstrained endpoints
Archived bit SHA-256:    1e59cd22dbed741f13f3559c6132876dda0a241c50cb4589a6ee7bd0ec50ff5c
Archived XSA SHA-256:    021f7d6e8950331515d8ed1f87645b8f046e3982ad2a73f7ca28a0a811628784
Vitis and packaging:     one run each; archived bit passed explicitly
Current F0.9.99 image:   FIRMWARE_F0.9.99_DUAL_SSI263_SC02_COLD_PITCH_SEED_WNS0p015.BIN
Firmware size:           4,264,652 bytes
Firmware SHA-256:        7e16601cb141e96ce5f7f5d986c6f089d858e29640035e4904c7fe405141318d
Hardware listen:         pending
```

The normal exporter stopped after implementation because `+0.015 ns` is below
the later `+0.300 ns` release gate. The positive-slack exporter then opened the
same final checkpoint without another implementation and recorded
`status=positive_slack_test_exported`. Bootgen identifies the archived
bitstream by name and the two frontend sections at `0x00100000` and
`0x0027c000`. The frontend ELF contains `Firmware F0.9.99`.

The rejected predecessor is build `20260825T132135Z-47003c7d-full`, source
commit `47003c7dd7dbc58b657b064161e3b5cfb2f626ca`, with WNS `+0.007 ns` and
firmware SHA-256
`1f049c469cee4be84dc5b4509cb9f34c1d4a529288c4eea2a97075da9a801f12`.
It has the corrected PW1 gate but the bad zero cold-pitch seed. Do not flash it
for this listen.

## Hardware validation for this candidate

The next Appletini test should first check that the new image boots, Phasor is
seen, both SSI chips respond, A5/A6 route to separate channels, both request
paths work, and simultaneous speech stays independent. Then listen to fixed
register vectors across voiced, fricative, mixed, and transition phones. Start
with a fixed-pitch phrase and confirm that its first five phones no longer rise
in pitch. Then use a deliberate IS target change and confirm that the normal
drawn transition still moves in both directions.

For a real-chip match, capture XCK, DIV2, A/R, D7, U150 or AO, and post-C381
audio from an original SSI-263AP Phasor with the same vectors. Measure source
level, filter peaks, width, decay, and route changes. Use those captures only
for terms absent from the schematic. Do not restore any phone-specific tweak.

The correct release claim before those captures is: two native SSI-263AP
digital models with an ideal SC-02 schematic charge model and original Phasor
card wiring, with analog hardware matching still pending.

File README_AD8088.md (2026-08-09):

# Virtual ALF AD8088 Plus

Appletini can expose one of two mutually exclusive processor cards in slot 5:
the existing PCPI-compatible Z80 Appli-Card or a virtual 640 KB ALF AD8088
Plus. Physical slot 5 must be empty. The Plus layout is a compatibility
superset of the original Processor Card and includes the documented AD128K
address range.

## Configuration

Open **Config > Slot 5 Processor**, enable slot 5, and select either:

- `Z80 Appli-Card`
- `ALF AD8088 Plus (640K)`

Changing the selection resets the selected coprocessor. Virtual TransWarp and
the AD8088 cannot run together because both own the Apple bus. The menu blocks
a live conflict, and startup turns vTW off if an old profile enables both. The
PL also refuses AD8088 memory cycles whenever vTW is enabled. AD8088 bus cycles
are deferred while Disk II is in a timing-critical motor window.

## Implementation

The PL implements the sixteen slot-5 I/O ports at `$C0D0-$C0DF`, including the
documented port-0 bit-7 handshake. Single-byte accesses use the normal DMA
path. Monitor fill and copy commands move four bytes during one DMA hold, then
release the Apple bus before the next batch. The service runs batches for up
to one millisecond per main-loop pass, so a large boot copy finishes promptly
without one long DMA hold. This keeps each hold below the 6502's 10 microsecond
register-retention limit. Each batch has a sequence number, so old completion
state cannot finish a new request. If Disk II or vTW owns the bus, the command
stays pending and retries later; it never reports success without moving the
data. A transaction stopped by such a window carries a latched blocked
verdict in BUS_STATUS, so the PS still classifies it as retryable when the
window has closed before completion is read. A running 8088 program stalls
through blocked windows like added wait states instead of failing
mid-instruction. A timeout finishes the current data phase and uses the
normal parked release before READY returns. Reset, mode change, and slot disable remain hard
boundaries that release DMA, address, and data drive.

The PS runs an 8088-instruction-compatible XTulator CPU core plus a clean-room
monitor in a dedicated 1 MB DDR arena, separate from the Z80 card's memory.
The emulated physical memory map matches the 640 KB configuration expected by
AD8088 Plus software such as Reboot Camp '83:

- `$00000-$0FFFF`: 64 KB local RAM
- `$10000-$1FFFF`: 64 KB Apple shared-memory window
- `$20000-$2FFFF`: 64 KB expansion RAM
- `$30000-$3FFFF`: unpopulated gap (reads `$FF`)
- `$40000-$BFFFF`: 512 KB expansion RAM; `$40000-$5FFFF` remains the
  original AD128K-compatible range
- `$C0000-$FEFFF`: unpopulated ROM space (reads `$FF`)

The monitor implements integer commands 29-32, floating-point commands 33-47,
user commands 48-247, SEQUENCE (`$FB`), RANDOM (`$FC`), SET MEMORY (`$FD`),
MOVE DATA (`$FE`), and far CALL (`$FF`). Original-ROM graphics/MET commands
1-28 are currently accepted as no-ops. This is a clean-room compatibility
implementation, not a copy of the original ALF PROM, so software that depends
on those original graphics routines is outside the current compatibility
scope.

## Test disks

Run `python scripts/build_ad8088_test_disks.py` to generate:

- `software/AD8088_Test.dsk` -- bootable DOS 3.3 image
- `software/AD8088_Test.po` -- bootable 800 KB ProDOS image

Both auto-run the same visible test. It checks the mailbox, an 8088 integer
monitor command, fill/copy through the AD128K-compatible range, and execution
of real 8088 code. The last stage makes the 8088 write
`8088 EXECUTED THIS LINE` directly into the Apple text page through the
shared-memory window.

The Reboot Camp disk at `software/AD8088 MSDOS.hdv` follows the manual's READY
check before each port write and waits for READY after each long monitor
command. It reads back the copied IO.SYS header before it starts the 8088 and
does not rely on a fixed delay for the 24,763-byte boot copy.

UART `8088 status` reports monitor state, command/error counts, the actual 8088
instruction count, and average instructions/second since the preceding status
request. Take two readings while an 8088 workload is active to measure its
effective speed. `8088 dump <address> <length>` displays emulated card RAM.

The vendored XTulator CPU source and its GPL-2.0-or-later notice are under
`third_party/xtulator_cpu/`.

Protocol and memory-map behavior were implemented from the
[ALF AD8088 Processor Card manual](https://mirrors.apple2.org.za/Apple%20II%20Documentation%20Project/Interface%20Cards/CPU/ALF%20AD8088/Manuals/ALF%20AD8088%20Processor%20Card%20Manual.pdf).

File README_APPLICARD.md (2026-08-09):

# PCPI Appli-Card

For the mutually exclusive ALF AD8088 Plus slot-5 personality, see
[`README_AD8088.md`](README_AD8088.md).

Appletini One provides a PCPI Appli-Card compatible Z80 coprocessor in Apple
slot 5. The Apple-visible latch protocol is implemented in PL, while the Z80
and its private memory run on the Zynq PS.

## Compatibility

- Two byte latches and two handshake flags match the PCPI card protocol.
- The embedded 2 KB v9 boot ROM is CRC-checked at firmware startup.
- Z80 memory contains 32 banks of 64 KB, for 2 MB total.
- Bank-register bits 1-3 retain GZ/80S behavior; bits 4-5 select the additional banks.
- The upper 32 KB common area maps to bank 0 when bank-register bit 6 is set.
- The Z80 interpreter supports the documented and undocumented instruction behavior
  exercised by ZEXALL.

The card has no slot ROM and no shared Apple/Z80 memory. Both processors
communicate entirely through the latch protocol, so PS execution latency does
not change Apple-visible timing.

## Apple Interface

Slot 5 uses `$C0D0-$C0DF`:

| Address | Read | Write |
| --- | --- | --- |
| `$C0D0` | Read Z80-to-6502 byte and clear its pending flag | Ignored |
| `$C0D1` | Read back the 6502-to-Z80 latch | Write a byte and set its pending flag |
| `$C0D2` | Bit 7 reports a byte pending for the Z80 | Ignored |
| `$C0D3` | Bit 7 reports a byte pending for the 6502 | Ignored |
| `$C0D4` | `$FF` | Ignored |
| `$C0D5` | Reset the Z80 and return `$FF` | Reset the Z80 |
| `$C0D6` | `$FF` | Ignored; the physical card's CTC socket is unpopulated |
| `$C0D7` | Pulse Z80 NMI and return `$FF` | Pulse Z80 NMI |
| `$C0D8-$C0DF` | `$FF` | Ignored |

Reads of `$C0D5` and `$C0D7` perform the same side effect as writes. Reset
clears both latches and flags in PL before the PS restarts the Z80.

## Z80 Interface

The I/O decoder mirrors each function across a 32-port range:

| Ports | Behavior |
| --- | --- |
| `$00-$1F` | Read back or write the Z80-to-6502 latch |
| `$20-$3F` | Read and consume the 6502-to-Z80 latch |
| `$40-$5F` | Read handshake flags |
| `$60-$7F` | Map or unmap the boot ROM |
| `$80-$BF` | Unpopulated/reserved, reads return `$FF` |
| `$C0-$DF` | Write the bank/common-area register |
| `$E0-$FF` | Ignored, reads return `$FF` |

The PL register bridge is AxiSimple slave 7 at `0x40070000`. A sequence number
is attached to each Apple-to-Z80 byte so a delayed PS acknowledgement cannot
consume a later byte.

## Firmware Controls

The **Z80 Applicard** configuration tab enables slot 5 and selects Standard or
Maximum CPU share. The settings are stored as:

```text
applicard.slot5.enabled=on|off
applicard.resource.max=on|off
```

UART commands:

```text
z80 status
z80 on|off
z80 reset
z80 budget <tstates>
z80 wall <microseconds>
z80 dump <hex-address> [length]
```

Physical slot 5 must be empty whenever the virtual card is enabled.

## Demo Media

`software/applicard/DEMOBOOT.DO` boots PCPI CP/M 2.2 through the virtual Disk II
in slot 6. `DEMOGAME.DO` contains the bundled game data disk. The directory also
contains banking and CPU-validation programs plus source media for
compatibility testing.

The embedded ROM is generated from `software/applicard/APPLICARD.ROM` by
`scripts/gen_applicard_rom_c.py`; runtime firmware never loads an SD-card ROM
override.

Run `python scripts/test_applicard_card.py` for the protocol, banking, wiring,
configuration, and service integration checks. The PL testbench is
`hdl/sim/tb_applicard_card.sv`.

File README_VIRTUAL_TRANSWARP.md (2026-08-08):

# Virtual TransWarp — Design Document

## Fixed Enhanced-//e acceleration

Accelerating presents a **fixed Enhanced //e on every host**, //e or II+.

- **Embedded CPU ROM.** The 16 KB Enhanced //e ROM (`docs/Apple2e_Enhanced.rom`
  → generated `ps_sources/frontend/apple2e_cpu_rom_data.c` via
  `scripts/gen_apple2e_cpu_rom_c.py`) is loaded into the shadow ROM region on
  every takeover (`VTW_ST_LOAD_ROM`).
- **One translate path.** The core always uses the //e MMU model. A
  II+ running the //e ROM drives the //e switches, which the private tracker
  follows.
- **Synthesized //e status reads.** `$C011–$C01F` are served internally from
  the tracked switch state without a bus cycle — a II+ has no //e IOU to
  answer them (`X_STATUS_DONE`). `$C019` RDVBLBAR uses the native VBL boundary
  at `192:0`; hardware validation showed that a vTW may be cycle accurate but
  it doesn't have the correct VBL timing. It fluctuates generally one cycle
  early.
  RDVBLBAR bit7 uses the //e AppleWin convention (1=active display, 0=vblank).
- Character ROM is the user's responsibility (Video ROM config); the built-in
  default is already a //e set. Functional coverage: `tb_vtw_video`.

Components:
- `hdl/apple/w65c02_core.sv` — cycle-exact W65C02S core (2.54 M
  SingleStepTests vectors, Klaus Dormann functional/extended/decimal/
  interrupt suites, 266 directed checks; routed standalone at 133 MHz,
  WNS +0.631 ns).
- `globals.sv::translate_apple_addr` — the //e banking translator as a
  shared function over an explicit `TranslateState`: the vTW's private
  switch copy and the motherboard tracker use one source of truth.
- `hdl/apple/vtw_shadow.sv` — 144 KB dual-port shadow (main 64K, aux 64K,
  ROM 16K; LC folded by the translator's bit-12 remap). Port B = ARM.
- `hdl/apple/vtw_bus_engine.sv` — sync-cycle FSM, 512-deep posted write
  queue (flush-before-video-window + bank-steer flush ordering),
  parked-cycle driver, PHI1-disciplined /DMA with full bus release during
  Apple RES# windows (§2 RES# row). Drives addresses at the wrapper's
  `TAP_DRIVE_ADDR` strobe (`ab_read.drive_en`, fall+8).
- `hdl/apple/vtw_core_top.sv` — core socket + private `soft_switch_manager`
  instance (synthetic serve_en pulses) + routing + CE pacing (full / divided
  / cycle-locked 1 MHz on `data_en`) + $C074 decode + ARM boot-copy port.
- `apple_top.sv` — vtw_core_top as the arbiter's 11th client; effective
  enable = config bit AND machine ∈ {//e, II/II+}, latched for the whole
  session so CTRL-RESET cannot tear a running session down. Accelerated
  sessions are always an Enhanced //e (no per-host flavor); `video_vbl`
  feeds the core's synthesized `$C019`;
  AxiSimple window 0x6C–0x7F (CTRL, auto-incrementing shadow port, ARM
  sync-cycle command/status, status/counters, bus-trail rings).
- `ps_sources/frontend/vtw_service.c` — session sequencer: waits for the
  boot ROM's machine report (//e or II/II+), takes the bus, asserts RES#
  (~100 ms) so the takeover can never land mid-protocol, invalidates
  $03F3/F4 (forces the autostart cold path; the shadow persists across
  sessions), loads the embedded Enhanced //e ROM into the shadow via the
  port-B window (`VTW_ST_LOAD_ROM`), releases the core.
- UART `vtw [status|on|off|speed full|1mhz|div <n>]` + config-menu
  "TransWarp" tab (the slot-3 presentation): enable checkbox dimmed on a
  positive non-//e identification; presets MAX / 26 / 13 / 7 / 3.6
  / 2.6 / 1 MHz cycle-exact (divided-mode dividers 5/10/19/37/51 against the
  133.333 MHz fabric clock). Persisted keys `vtw.enabled`,
  `vtw.speed.mode`, `vtw.pace.divider`, `vtw.c074.ignore`, and
  `vtw.disk2.acceleration.disabled`. RAM-tab interplay: under
  acceleration the machine always has 8MB (lives in the shadow);
- SmartPort transport state (FIFOs, exec/ready, control) clears on Apple
  RES#, on the card and via the PS sweep + hw-EXEC-gated poll
  (`tb_smartport_reset` covers it).

Operational notes:
- IRQ/NMI are sampled at the late-PHI0 data snap with a 2-consecutive-
  sample filter: bus-drive ground bounce otherwise forges IRQ edges, and
  an unenhanced //e vectors them through its internal handler.
- Parked I/O-page addresses are sanitized to $FFFF: our parked cycles are
  clean, fully-decodable replays, and a replayed $C0xx read would
  re-execute read side effects every idle cycle.
- PAL/international //e: INTCXROM=1 with PC in internal $C2xx at an idle
  prompt is the machine's NORMAL keyboard-firmware wait state (mid-KEYIN
  via the $FBB4 trampoline), not a fault signature.

## 1. Goal and governing constraint

Add a virtual accelerator to the Appletini that makes the host Apple //e run
at configurable speed (well beyond 3.58 MHz), presented in the config menu as
a slot-3 device.

**Governing constraint: the bus contract is the physical Applied Engineering
TransWarp's, verbatim.** The Appletini's capture, serving, soft-switch, and
renderer paths are hardened and hardware-validated against exactly that
master behavior — full shadow, sparse bus traffic, held /DMA.
By emitting the same *contract* (which cycles appear on the bus and what they
mean), the virtual TransWarp requires **zero changes** to every other
subsystem, and every test we ran against the physical card doubles as its
acceptance suite. Speed is the only sanctioned deviation.

One deliberate electrical improvement that does not change the contract: our
bus cycles are driven with ideal 6502 timing (address/R-W asserted early in
PHI1, held through the whole cycle, bus actively parked between accesses).
The physical TW's late assertions and early releases are the root of its
compatibility problems; ours is the best-behaved master on the platform,
which also means our own snooping paths observe our cycles perfectly.

## 2. Bus contract (mirrors the physical TransWarp)

| Access class | Bus behavior |
|---|---|
| /DMA | Asserted (open-drain low) from Apple reset-release when the vTW is enabled; held for the whole session **except during Apple RES# windows, where the bus is fully released so the MMU/IOU process the reset under stock conditions (see RES# row)**. Transitions only during PHI1 (Apple IIe Tech Note #2). Motherboard 6502 sleeps; handback is via CTRL-RESET with the vTW disabled, exactly like `$C074 = 3` on the real card. //e and II/II+ (the `machine_inh_allowed` interlock covers both; a IIgs is refused). On a II/II+ the core's translator neutralizes the //e-only MMU switches (no aux, no internal $CX ROM, slot 3 owns $C3xx) — acceleration only, the machine's memory is what it is; the language card is tracked either way (slot-0 $C08x protocol, LC image lives in the shadow). |
| $C000–$CFFF | Real bus cycles, one per access, synchronized to PHI0, except for the Appletini's private SmartPort path and safe even reads of its virtual Disk II switches. Normal bus accesses stall the core for sync plus one Apple cycle. Disk II odd reads and all Disk II writes stay on this path; Q7 write mode also holds the whole core at 1 MHz. |
| Writes to $0400–$0BFF and $2000–$5FFF | Written through to motherboard RAM as posted bus writes (keeps a CRT/composite display live, matching AAL's documented TW behavior), for main (bank 0) AND base aux (bank 1): the bus cycle carries only the Apple address, and the motherboard's own switch state — which mirrors the core's, since it tracks the same $C0xx cycles — steers it into the right bank. A bank-steer flush rule (sync write to $C000–$C007 or any $C054–$C057 access flushes the posted queue) keeps queued writes retiring under the switch regime they were issued in; without it the capture shadow's aux banks never update and 80-col/DHGR render empty. Posted queue drains on idle bus cycles; the core does not stall unless the queue fills. |
| All other memory traffic | Invisible. Reads and writes hit the BRAM shadow only; motherboard RAM is deliberately stale outside the video windows (manual: "The Apple's memory is used only for video display"). |
| RamWorks banks (aux beyond base 64K) | When the Appletini provides aux memory (RAM tab on, no physical aux card — the same gate as the motherboard-side serving), the vTW serves all 8 MB from PSRAM **at accelerator speed**: the private translator emits bank-qualified addresses from its own $C071/$C073 tracking, and a single-line (8-byte) write-allocate cache turns sequential traffic into one PSRAM line op per 8 bytes, admitted through `psram_simple`'s existing bounded background window (priority above PS-DMA, below the Apple write queue — serve-deadline analysis unchanged). Dirty lines are written back on eviction and whenever the core drops into reset, so RamWorks contents survive CTRL-RESET and handback; the cache invalidates between sessions. While the vTW owns the bus, `psram_simple` suppresses INH read-serving (parked aux-routed replays would otherwise consume every background-admission slot and starve this port — the accelerator's real aux traffic never uses the bus), and the boot ROM's aux-slot probe report is ignored during a session (the probe reads back the shadow, not the slot). With a physical aux card (or RAM tab off) the translator never leaves banks 0/1: banked software sees clean 64K-card aliasing and correctly sizes the machine as having no RamWorks. This is better than the physical TW, which passes all aux traffic to the bus at 1 MHz. |
| Idle cycles | Bus actively parked: last real address re-driven with R/W = 1 (I/O-page addresses sanitized to $FFFF so read side effects are never replayed). No floating, no decay. |
| $C074 | Decoded by the vTW (motherboard-space register, same as the real card): write 0 = full speed, 1 = cycle-locked 1 MHz, 3 = off-until-reset. RocketChip-compatible software expects this. The optional `Ignore $C074 Speed Switch` setting discards every value and clears any value latched before it was enabled. This keeps the chosen menu or USB speed in force, but can break timed I/O and copy protection. |
| RES# | Filtered RES# resets the core through the shadow's reset vector (autostart ROM). **The bus is released for the entire reset window** — /DMA deasserted, nothing driven — **and the motherboard 6502 then runs 80 stock cycles after RES# rises before the bus is re-taken.** Both halves are required by the //e MMU: it does not process a reset while a DMA master holds the bus, and its soft-switch clear is only completed by the 6502's own post-reset activity (reset sequence + $FFFC/$FFFD vector fetch). 80 cycles covers the vector fetch and INIT's display-mode switches (snooped by the tracker) while ending well before the reset handler's first MMU write (the $FA77 trampoline's `STA $C007`, ~cycle 160); the 6502's remaining traffic is zero-page/stack writes to real RAM, which is stale under the vTW anyway. The vTW core boots from shadow in parallel and stalls on its first $C0xx sync access until the engine re-owns the bus. CTRL-RESET with vTW disabled simply never re-takes: the machine returns to the motherboard 6502 cold. |
| IRQ/NMI | The sampled slot pins (already in `ab_read`) wire directly to the core's IRQ#/NMI# inputs. Vector fetches go through the shadow with correct LC banking. Strictly better than the real TW's power-on reboot stub, with the same observable contract for a booted OS. |

## 3. Architecture — fabric 65C02

```
PL (fabric)                                        CPU0 (ARM)
+------------------------------------------+      +---------------------+
| vtw_core_top.sv                          |      | vtw_service.c       |
|  +-----------+   +--------------------+  | Axi  |  (thin: config,     |
|  | 65C02     |   | shadow BRAM        |  |Simple|   boot ROM copy,    |
|  | soft core |<->| ~172 KB dual-port  |<-+------+   $C074 state,     |
|  | (CE-      |   | A: core  B: ARM    |  |      |   diagnostics)     |
|  | throttled)|   +--------------------+  |      +---------------------+
|  +-----+-----+                           |
|        | route (translate_apple_addr)    |
|  +-----v-----------------------------+   |
|  | vtw_bus_engine.sv                 |   |
|  |  sync cycle FSM | posted wr queue |   |
|  |  /DMA + parked-cycle driver       |   |
|  |  (new ab_write arbiter client)    |   |
|  +-----------------------------------+   |
+------------------------------------------+
```

- **Core: soft 65C02 in fabric, supplied by the project owner.** The wrapper
  is written against a conventional synchronous 65C02 interface (clk, CE,
  addr[15:0], data in/out, we, irq_n, nmi_n, res_n, sync/rdy as available)
  so the specific core drops in. Regardless of source, the integration gate
  is a behavioral sanity suite in simulation (Klaus Dormann's 6502/65C02
  functional tests run against the BRAM shadow) before first hardware boot.
- **Shadow: dual-port BRAM, ~172 KB ≈ 40 RAMB36.** Budget measured against
  the current build: 36/140 tiles in use (25.7%), so shadow + core lands
  around ~55% — comfortable. Layout: 64 KB main, 64 KB aux, 16 KB main-LC,
  16 KB aux-LC, 12 KB ROM copy. Port A: the core, single-cycle. Port B:
  AxiSimple-mapped ARM access for boot-time ROM copy, debug peek/poke, and
  state dumps — a built-in debugger for free.
- **Memory routing: reuse `translate_apple_addr` in RTL.** The vTW's bank
  selection (main/aux/LC/ROM/bus classification) is exactly the function the
  soft-switch manager already owns. The core wrapper instantiates the same
  function against a private copy of the switch state, which the vTW tracks
  from its own accesses (it is the CPU; it sees every $C0xx access it makes
  before the bus does). One source of truth for //e banking semantics.
- **Speed: clock-enable throttling.** The core runs at fabric clock with a
  programmable CE pattern: full-rate bursts (BRAM-fed, tens of
  MHz-equivalent), M/N fractional rates for the config-menu presets, or
  CE locked to the wrapper's `sss_en` tick for an *exact* cycle-locked 1 MHz
  mode — which passes cycle-counting detection probes (A2DeskTop) that the
  real TW fails.
- **ARM's role is thin** — enable/config, orchestrating the boot ROM copy,
  mirroring $C074 state for the menu, and `:vtw status` diagnostics. CPU0's
  main loop gains no hot work.

## 4. PL bus engine specification

Timing in the wrapper's existing tap vocabulary (133 MHz fabric, PHI0 edges
from the majority filter; ~7.5 ns/tap).

**Synchronous cycle (all $C000–$CFFF, boot-time ROM copy, phase-2 RamWorks):**
1. Request from the core wrapper (or ARM port B during boot):
   `{addr[15:0], rw, wdata[7:0]}`; core CE deasserts.
2. Engine waits for the next PHI0 **fall**, then at `fall+TAP_DRIVE_ADDR`
   (~tap 8, inside early PHI1) drives address + R/W through
   `ab_write.wr_addr / wr_rw / wr_addr_rw_en`.
3. Writes: data driven from `data_phase_emit` (existing tap 25 after rise)
   until end of cycle, via `wr_data / wr_data_en`.
4. Reads: result latched from `data_clean` at `TAP_DATA_SNAP` (existing
   tap 59 after rise) — the same instant the capture path samples, so master
   and observer agree by construction.
5. Response releases the core CE. Stall cost: 0–1 µs sync + 1 µs cycle.
6. Address/R-W stay driven after the cycle (becomes the new parked state).

**Posted write-through (video windows only):**
- RTL address filter on core writes to $0400–$0BFF / $2000–$5FFF pushes
  `{addr, data}` to the posted queue (BRAM FIFO, 512 deep) in addition to the
  shadow write.
- Engine drains one posted write per idle PHI0 cycle. Idle bandwidth
  (~1M cycles/s minus I/O) vastly exceeds video write rates; queue-full
  back-pressures the core CE (mirrors the real TW's measured screen-write
  throttling, with a far deeper queue).
- Ordering rule: a synchronous request whose address falls in a video window
  flushes the posted queue first (read-after-write consistency); otherwise
  synchronous I/O may overtake posted writes, like the real card's decoupled
  engine.

**Parked-cycle driver:** whenever enabled and no cycle is active, re-drive
the last real address with R/W=1 with the same `fall+TAP_DRIVE_ADDR`
discipline. Every cycle on the bus is a clean, fully-driven cycle for the
motherboard, our own snoop path, and any third-party card.

**/DMA protocol:** assert during PHI1 following reset-release (TN#2), hold
until disabled+reset — with one exception: every Apple RES# window releases
the bus completely (MMU/IOU reset processing requires stock conditions),
and the engine re-arms through the same DMA-then-grace-then-drive sequence
at release. The arbiter's `inh_allowed` gate already blocks `assert_dma`
on non-//e machines; vTW enable additionally requires machine_mode == IIe.

**Arbitration note:** while the vTW masters the bus, the Appletini
simultaneously *serves* some of the cycles it issues (its own virtual cards'
I/O). Address drive (master) and data drive (server) use different
transceivers (`tini_addr_dir` vs `tini_data_dir`) — electrically and
logically sound; the serving path needs no changes because our cycles meet
the early-assert contract the serve path was built for.

## 5. Boot and control flow

1. PS asserts vTW mode before Apple reset-release (config/persisted); core
   held in reset. The engine waits out RES#, then asserts /DMA and the
   parked driver takes the bus.
2. ARM (via BRAM port B + the sync-cycle FIFO) copies motherboard ROM
   $D000–$FFFF into the shadow over real bus reads — works with any ROM
   revision, exactly like the real card's power-up copy.
3. Core released at the shadow reset vector; autostart proceeds; every
   $Cxxx access (slot scan, boot menu, disk boot) happens over the real bus.
4. $C074 writes are seen by the core wrapper (it issues them) and mirrored
   to a status register for the ARM/menu; semantics per §2.
5. Diagnostics: `vtw status` on the UART console — speed mode,
   executed-cycle counters, posted-queue depth/high-water, soft-switch
   state, post-reset soft-switch trail, $C1xx–$CFFF sync-cycle trail.

## 6. No slot

The accelerator needs no slot decode to function — a DMA bus master has no
slot presence; its only software-visible surface is the $C074 register in
motherboard address space, decoded by watching the bus exactly as the real
card's PALs do.

## 7. Phase 2 plan

In priority order:

1. **RamWorks at accelerator speed** — implemented (see the §2 RamWorks
   row). 8 MB from PSRAM through the vTW line cache when the Appletini
   provides aux; clean 64K semantics otherwise.
2. **Speed controls: config menu + assignable USB keymap actions —
   implemented.** No new soft switches, ever — $C074 stays the only
   decoded register (TW contract; silently claiming more I/O addresses
   risks colliding with 40 years of software). Four assignable keyboard
   actions in the Boot-settings USB keymap (global: they fire with the
   menu open or closed, unbound by default), all PS-side writes to the
   VTW control register:
   - *TW 1MHz* — 1 MHz ⇄ configured speed ($C074-style toggle).
   - *TW speed+ / TW speed−* — one step along the preset ladder
     1 → 2.6 → 3.6 → 7 → 13 → Warp.
   - *TW slug .05* — 0.05 MHz ⇄ configured speed, for single-stepping-
     grade debugging. Independent toggle, NOT on the ladder: +/− can
     never land on it (a step up from slug exits to 1 MHz). The pace
     divider is 16-bit (50 kHz = divider 2667, CTRL[31:16]). The slug key
     is **disarmed by default** and ignored until the TransWarp tab's
     "Enable 0.05 MHz slug debug key" checkbox is set — an accidental
     press must never silently near-halt the machine; disarming while
     slugged restores the configured speed immediately.
   Every speed action raises a **top-of-screen overlay** (`TW: 7 MHz`)
   so the change is visible even without the UART — anchored at the top
   so it never collides with the bottom screenshot overlay. Runtime
   overrides never persist and a configured (menu) speed change clears
   them, matching $C074 semantics. Session enable/disable stays
   BOOT-mode-only; only speed is live. The boot beeps double as audible
   speed confirmation.
3. **Own-card I/O short-circuit — SmartPort at core speed (implemented).**
   Previously every slot-7 access — the driver code in slot/expansion ROM
   *and* the DATA/CTRL/DPOP registers — was a 1 MHz bus cycle, so disk I/O
   was the one thing acceleration did not accelerate (the 512-byte
   transfer loop and its instruction fetches both ran at bus rate). Now,
   when the Appletini's SmartPort card owns slot 7 (`sp_active`, i.e. after
   the boot menu hands off), `vtw_core_top` classifies the core's accesses
   to the card's Apple surface — slot ROM $C700–$C7FF, expansion ROM
   $C800–$CFEE, and DATA/CTRL/DPOP at $CFF0–$CFF2 — using its **private**
   soft-switch state (correct on both //e INTCXROM/IOSEL and a II+ with no
   MMU), and serves them through a fabric-internal port on `smartport_card`
   (`X_SP_ISSUE`→`WAIT`→`DONE`, ~2-cycle latency) instead of a sync bus
   cycle. The card's fast port drives the **same** FIFO/exec/IRQ state as
   the bus path (unified `data_write_ev`/`ctrl_write_ev`/`pop_write_ev`
   events), so ROM and OUT-head reads stay side-effect-free and the PS
   protocol is unchanged. The gate on `sp_active` also resolves the
   shared slot-7 ownership: before hand-off the boot-menu card still sees
   $C7xx over the bus; after, SmartPort is short-circuited. The disk
   *service* latency (PS/USB) is unchanged — only the transport and driver
   execution accelerate, which is the dominant cost.
4. **Virtual Disk II reads at core speed — implementation pending hardware
   validation.** When the Appletini Disk II owns slot 6, even reads of
   `$C0E0-$C0EE` use a private `disk2_card` port. One virtual Disk II tick is
   generated for each completed vTW CPU cycle, so standard nibble rotation,
   WOZ bit cells, empty-drive settling, and deferred head steps scale with the
   chosen CPU speed. A track-stage or DDR line-cache miss holds both the CPU
   and virtual disk time until valid data is ready; it cannot return a stale
   latch or consume a missing byte. The `Disable DiskII Acceleration` setting
   bypasses this private path and sends all Disk II accesses through the
   original physical 1 MHz route for problem disks. Odd reads still use the
   motherboard's floating bus. Every CPU write uses the physical Apple bus
   at 1 MHz. While Q7 write mode is active, the whole core stays at 1 MHz
   until Q7 clears, so the existing DSK/PO/NIB/WOZ write path and its
   copy-protection timing stay
   unchanged. Motor and seek audio remain tied to real time. Covered by
   `tb_disk2_vtw_read`, `test_disk2_standard.py`, and `test_disk2_woz.py`.
5. **Per-region slowdown — implemented (TW DIP block 2).** After the core
   touches an enabled timing-sensitive region it drops to cycle-locked
   1 MHz for a configurable window (retriggered per access), so speaker
   pitch, paddle timing, and per-slot device loops stay correct at high
   core speeds. `vtw_core_top` classifies the per-cycle address (speaker
   $C030-$C03F, paddle $C064-$C067 + PTRIG $C070, per-slot device I/O
   $C0n0-$C0nF for slots 1-7) and folds a one-shot counter into `eff_mode`;
   config lives in AxiSimple register 0x6B ([8:0] region enables,
   [31:16] window). Exposed in the TransWarp tab: speaker, paddle, a
   per-slot selector, and the window size — all **default OFF**. The
   virtual Mockingboard/Phasor slot (4) is **always** slowed regardless of
   config, because its 6522-VIA cycle-counted detection otherwise fails at
   warp. Validated by `tb_vtw_slowdown` (warp baseline runs fast; speaker
   slowdown collapses the rate to ~1 MHz; a non-matching region enable
   stays warp).
6. **II/II+ acceleration — implemented, bench validation pending.**
   Acceleration only, no memory changes: the machine gate accepts a
   positive II/II+ identification, and the core's translator runs a
   sanitized view (aux switches, internal $CX ROM, and slot-3 internal
   ROM forced off; slot 3 owns $C3xx; language card tracked normally —
   the shadow carries the LC image, so a stock $C08x-protocol LC works).
   IIe-probing software can write $C00x freely without deranging the
   shadow. The boot copy runs unchanged ($C100–$CFFF captures floating
   garbage the sanitized translator never reads; $D000–$FFFF gets the
   real II+ ROM through forced LC-ROM reads). Aux-provide/RamWorks stay
   off via the existing IIe-only PS policy. Still needs first-hardware
   validation on a real II+: bus buffering under /DMA mastering and the
   machine's reset physiology have never been measured there.
7. **Config-menu polish** — slug-key arm checkbox + top-of-screen
   speed overlay done; per-region slowdown toggles and a RamWorks
   status row remain (follow items 4 and 1 respectively).

**Explicit non-goals:** IIgs support; mid-flight handback (impossible on
NMOS, same as the real TW); NMOS-cycle-timing emulation (the vTW is a
65C02 exactly as the physical TW is — for 100% NMOS cycle accuracy,
disable acceleration).

**Fallback (de-risk only):** if the chosen core misbehaves, an ARM-side
interpreted 65C02 (Appli-Card Z80 pattern) can drive the same
`vtw_bus_engine` request interface unchanged — the engine contract is
requester-agnostic by design.

## 8. Risks and their measurements

| Risk | Measurement / mitigation |
|---|---|
| BRAM budget | Measured: 36/140 tiles used today; shadow ≈ +40 → ~55%. Re-check utilization + timing after integration; drop aux-LC (−4 tiles) if squeezed |
| Core correctness/licensing | License check before import; Klaus Dormann functional tests in simulation against the BRAM shadow; undocumented-opcode policy = 65C02 NOPs |
| Timing closure with core + shadow | Core and BRAM are a self-contained island off the fabric clock; only the bus-engine FIFO crosses into tap-domain logic. Keep the island in its own hierarchy for floorplanning |
| Posted-queue coherency corners | Flush-before-video-window-I/O rule; test vapor-lock/floating-bus software |
| Our own capture/serve paths seeing master cycles | By design they must (that is how HDMI renders); early-assert discipline makes our cycles the easy case, validated by the existing suite |
| Contention with a physical accelerator | vTW enable is manual + documented: never with a real TW/FastChip installed (two DMA masters) |

## 9. Acceptance tests

The physical-TW validation suite, re-run against the vTW at full speed and
at cycle-locked 1 MHz, plus a vTW-disabled stock pass unchanged:
cold boot through boot menu → BASIC; CATALOG + DOS 3.3 SAVE/LOAD round-trip;
Ultima V logo + Phasor music; SmartPort "A:APPLETINI" boot (DPOP protocol);
Disk II DSK/PO save-load round-trip; NIB and WOZ copy-protected reads; empty
drive 2 prompt and disk swap; Disk II writes at forced 1 MHz;
monitor `0L` listing; A2DeskTop slot listing (Phasor must appear at 1 MHz
mode — a fidelity improvement over the real card); CRT liveness via the
posted write-through; Klaus Dormann suite in simulation before first
hardware boot.

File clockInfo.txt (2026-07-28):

-------------------------------------
| Tool Version : Vivado v.2025.2
| Date         : Fri Jul 17 19:48:25 2026
| Host         : Rik-UFO
| Design       : design_1
| Device       : xc7z020-clg484-2--
-------------------------------------

For more information on clockInfo.txt clock routing debug file see https://support.xilinx.com/s/article/000035660?language=en_US

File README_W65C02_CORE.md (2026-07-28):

# W65C02 SystemVerilog Core

`hdl/apple/w65c02_core.sv` is a synthesizable, cycle-stepped WDC
W65C02S-compatible processor core. It implements the complete 256-entry opcode
map, including CMOS instructions, RMB/SMB, BBR/BBS, WAI, STP, and the
W65C02S reserved NOP encodings.

The core is currently a standalone verified module. It is not yet instantiated
by `apple_top.sv` or registered in `hdl/hdl_sources.txt`.

## Interface

One external bus cycle completes on a rising `clk` edge when both `enable` and
`ready` are high. Bus outputs remain stable during a stall.

- `addr`, `data_in`, `data_out`, and `rwb` are the 16-bit address and 8-bit data
  bus.
- `sync`, `vpb_n`, and `mlb_n` expose the W65C02S instruction-fetch, vector-pull,
  and memory-lock indications.
- `irq_n`, `nmi_n`, and `so_n` implement the active-low processor inputs.
- `waiting`, `stopped`, and `instruction_done` expose useful integration state.
- The read-only `debug_*` outputs expose architectural state.
- Set `DEBUG_STATE_LOAD=0` in hardware. The `debug_load` and `debug_*_in` ports
  exist only to initialize individual simulator vectors and synthesize away.

For Appletini integration, clock the core from an existing PL clock and use
`enable` as its CPU-cycle clock enable. That avoids adding a clock domain or a
new BUFG/MMCM. A dual-port block-RAM shadow is the natural memory attachment:
one port for the core and one for the existing Apple-bus/PS-side update path.

## Verification

The fast harness combines directed pin/control checks with the MIT-licensed
[SingleStepTests WDC 65C02 corpus](https://github.com/SingleStepTests/65x02).
The corpus remains outside this repository because it is approximately 1 GB.

```powershell
git clone --depth 1 https://github.com/SingleStepTests/65x02 C:\tmp\65x02-tests
python scripts\test_w65c02_core.py --opcodes all --limit 0
```

The full run at corpus revision
`2f6980a2d95757486c7bee24355c360e40e2a224` passed:

- 2,540,000 architectural, memory, and exact bus-cycle vectors.
- 254 populated opcode files; WAI (`CB`) and STP (`DB`) files are empty upstream.
- 266 directed checks covering reset, IRQ/NMI priority and edge timing, SO,
  RDY/enable stalls, VPB, MLB, WAI, and STP.
- Progress is printed every 250,000 vectors, and the testbench stops on the
  first mismatch.

Program-level verification uses the GPL-3.0
[Klaus Dormann suite](https://github.com/Klaus2m5/6502_65C02_functional_tests).
Its sources and binaries also remain outside this repository.

```powershell
git clone --depth 1 https://github.com/Klaus2m5/6502_65C02_functional_tests C:\tmp\klaus-65c02-tests
python scripts\test_w65c02_klaus.py
```

At revision `7954e2dbb49c469ea286070bf46cdd71aeb29e4b`, all configured suites passed:

| Suite | Cycles | Instructions |
| --- | ---: | ---: |
| Functional | 96,561,327 | 30,646,179 |
| 65C02 extended opcodes | 66,907,075 | 21,986,988 |
| CMOS decimal, including invalid BCD | 48,776,483 | 15,250,620 |
| IRQ/NMI feedback | 3,057 | 1,068 |

The Klaus harness prints a heartbeat every 10 million cycles and rejects any
trap message, missing pass marker, or cycle-limit timeout.

## Vivado Results

Run the standalone implementation estimate with:

```powershell
vivado -mode batch -source scripts\synth_w65c02_core.tcl
```

Vivado 2025.2 placed and fully routed the core for `xc7z020clg484-2` at
133.333 MHz:

| Resource | Core | Device | Device use |
| --- | ---: | ---: | ---: |
| Slice LUTs | 1,010 | 53,200 | 1.90% |
| Slice registers | 157 | 106,400 | 0.15% |
| Slices | 305 | 13,300 | 2.29% |
| CARRY4 | 48 | - | - |
| Block RAM tiles | 0 | 140 | 0% |
| DSPs | 0 | 220 | 0% |

At a 7.500 ns constraint, routed timing is WNS `+0.631 ns`, WHS `+0.234 ns`,
and WPWS `+3.250 ns`, with zero failing endpoints and zero routing errors.
This is an out-of-context estimate; Vivado warns that `HD.CLK_SRC` is unknown,
so only a fresh integrated implementation can provide top-level timing signoff.

The last existing Appletini implementation used 25,709 LUTs (48.33%), 16,178
registers (15.20%), 8,209 slices (61.72%), 36 block-RAM tiles (25.71%), and 6
DSPs (2.73%). A simple additive estimate with this core is 26,719 LUTs (50.22%)
and 16,335 registers (15.35%). Slice counts are not safely additive because
packing changes during integration; the naive sum is 8,514 slices (64.02%).

The existing design also has 104 free block-RAM tiles, 214 free DSPs, 23 free
BUFGs, two free MMCMs, and four free PLLs. A 172 KiB byte-wide shadow memory
would consume approximately 43 RAMB36 tiles, bringing total BRAM use to 79/140
(56.43%) and leaving 61 tiles. The core itself needs no BRAM, DSP, or new clock
primitive.

The last top-level route met timing, but its WNS was only `+0.081 ns`. Treat
placement and integrated timing as the limiting resources even though raw LUT,
register, and BRAM capacity remain comfortable.

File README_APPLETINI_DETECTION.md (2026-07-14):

# Detecting an Appletini from 6502 Assembly

This document describes the supported way for Apple II host software (6502
assembly, or any language that can make a SmartPort call) to determine whether
it is running on a machine that contains an **Appletini** card.

## TL;DR

Issue a **SmartPort `STATUS` call** with **status code `$03`** (GETDIB —
"Return Device Information Block") to **unit `$00`** (the SmartPort *controller*)
in **slot 7**. The returned Device Information Block contains an ASCII ID
string. On an Appletini that string is **`Appletini SP`** (from the controller)
or **`Appletini HD`** (from an individual device unit). Compare the first 9
characters — **`Appletini`** — to identify the Appletini SmartPort firmware.

## Why this is the right mechanism

- **It's a standard, documented protocol call.** The DIB ID-string field exists
  precisely to carry a vendor/device name. No soft-switch probing, no writable-
  ROM tricks, no cross-slot games.
- **The controller (unit 0) answers even with no disk images mounted.**
  See `build_sp_status()` in `ps_sources/frontend/smartport_service.c`:
  ```c
  if (unit == 0x00U) {                 /* Unit 0 = SmartPort controller. Always present. */
      switch (status_code) {
      case SP_STATUS_GETDIB: {
          g_scratch[0] = smartport_present_count();
          for (i = 0; i < 13; ++i) g_scratch[8 + i] = ID_STR_CTRL[i];  /* "Appletini SP" */
          ...
  ```

The ID strings are defined in `ps_sources/frontend/smartport_service.c`:

```c
static const char ID_STR_CTRL[13] = { 12, 'A','p','p','l','e','t','i','n','i',' ','S','P' };
static const char ID_STR_DEV [13] = { 12, 'A','p','p','l','e','t','i','n','i',' ','H','D' };
```

## Important caveat: wait for the boot-menu handoff

Slot 7 presents the SmartPort ROM only **after the Appletini boot menu hands off
to it**. The state machine in `hdl/apple/boot_menu_card.sv`:

- On power-up and after **every Ctrl-Reset**, `slot7_mode_q` reverts to
  `SLOT_MODE_BOOTMENU`. In this state slot 7 is the *boot-menu* card, which
  advertises itself as a Disk II (`$C707` reads `$3C`) and will **not** answer a
  SmartPort GETDIB.
- It flips to `SLOT_MODE_SMARTPORT` only when `handoff_entry_read` fires (the
  host fetching the boot entry point). After that it stays SmartPort until the
  next reset. (Even a Disk II boot leaves SmartPort active in slot 7 — Disk II
  just additionally activates slot 6.)

SuperSprite also requires slot 7. Enabling SuperSprite gates SmartPort off, so
GETDIB detection is unavailable in that configuration.

For **normally-running application code** loaded through SmartPort or Disk II,
the handoff has already happened. To be safe in any context (reset-vector hooks,
etc.), the routine first
verifies the SmartPort ROM signature is actually present in slot 7 and bails out
cleanly if it is not (i.e. "Appletini not yet handed off" reads the same as "no
Appletini").

## Slot-7 SmartPort firmware facts used below

| Address | Value | Meaning |
|---|---|---|
| `$C701` | `$20` | SmartPort/ProDOS signature |
| `$C703` | `$00` | SmartPort/ProDOS signature |
| `$C705` | `$03` | SmartPort/ProDOS signature |
| `$C707` | `$00` | SmartPort device (`$3C` instead = boot-menu phase, *not ready*) |
| `$C7FF` | `$0A` | ProDOS entry offset → ProDOS entry `$C70A` |
| `$C70D` | — | SmartPort dispatch entry (`= $C70A + 3`) |

(From `hdl/apple/smartport_a2retronet_style_c700.mem`.)

## SmartPort STATUS / GETDIB call convention

The Appletini slot-7 dispatch uses the standard inline-parameter SmartPort
convention: `JSR` the dispatch address, then place the command byte and a
pointer to the parameter list immediately after the `JSR`; the dispatcher skips
them and returns past. Carry clear = success, carry set + A = error.

The STATUS parameter list is:

| Offset | Bytes | Field |
|---|---|---|
| 0 | 1 | parameter count (`$03`) |
| 1 | 1 | unit number (`$00` = controller) |
| 2 | 2 | status-list (result buffer) pointer |
| 4 | 1 | status code (`$03` = GETDIB) |

The **controller** DIB returned at the result buffer:

| Offset | Field |
|---|---|
| 0 | number of devices |
| 8 | ID string length (`$0C`) |
| 9 … 20 | ID string text — `"Appletini SP"` |
| 27, 28 | firmware version major, minor |

(A *device* GETDIB — unit `$01`+ — instead puts the length at offset 4 and the
text `"Appletini HD"` at offset 5.)

## Complete sample (ACME syntax)

A ready-to-assemble copy lives at [`software/detect_appletini.a65`](software/detect_appletini.a65).

```asm
; detect_appletini.a65 — detect an Appletini from 6502 assembly.
;
; Method: the Appletini emulates a SmartPort controller hard-wired to slot 7
; that cannot be disabled or relocated. Issue a SmartPort STATUS call with
; status code $03 (GETDIB) to unit 0 (the controller); the returned Device
; Information Block ID string is "Appletini SP".
;
; Returns:  carry CLEAR  -> Appletini present (falls through to `found`)
;           carry SET    -> not present / slot 7 not yet handed off to SmartPort
;
; Assemble:  acme -o detect_appletini detect_appletini.a65

!cpu 6502
* = $0800

SLOT        = 7
ROM         = $C000 + (SLOT * $100)   ; $C700  slot-7 ROM
SIG5        = ROM + $05               ; $C705  -> $03 on a SmartPort card
SIG7        = ROM + $07               ; $C707  -> $00 on a SmartPort card
SP_ENTRY    = ROM + $0D               ; $C70D  SmartPort dispatch (= ProDOS entry + 3)

SETSLOTCXROM = $C006                  ; IIe: make peripheral-card ROM visible in $Cx00

buffer      = $0900                   ; DIB result buffer (>= 32 bytes)
SIG_LEN     = 9                       ; compare just "Appletini"

; ===================================================================
detect
                ; On a IIe, ensure slot ROM (not internal Cx ROM) is mapped so
                ; both the signature read and the dispatch call hit the card.
                sta SETSLOTCXROM        ; write-only soft switch; value irrelevant

                ; --- 1. Is slot 7 currently presenting the SmartPort ROM? ----
                ; During the boot-menu phase $C707 reads $3C, so this guard
                ; cleanly rejects "Appletini present but not yet handed off".
                lda SIG5
                cmp #$03
                bne not_present
                lda SIG7
                bne not_present         ; must be $00

                ; --- 2. SmartPort STATUS / GETDIB to unit 0 (controller) -----
                jsr SP_ENTRY
                !byte $00               ; CMD = STATUS
                !word params
                bcs not_present         ; carry set -> call failed

                ; --- 3. Compare controller ID string to "Appletini" ----------
                ; Controller DIB: buffer+8 = length ($0C), buffer+9.. = text.
                ldx #0
cmp_loop
                lda buffer + 9, x
                cmp sig_text, x
                bne not_present
                inx
                cpx #SIG_LEN
                bne cmp_loop

found
                clc                     ; carry clear = Appletini detected
                rts                     ; <-- your code: it's an Appletini

not_present
                sec                     ; carry set = not detected / not ready
                rts

; ---- SmartPort STATUS parameter list -------------------------------
params
                !byte $03               ; parameter count
                !byte $00               ; unit 0 = SmartPort controller
                !word buffer            ; status-list (result) pointer
                !byte $03               ; status code $03 = GETDIB

sig_text
                !text "Appletini"       ; plain low ASCII, matches firmware
```

### Notes / portability

- **High vs low ASCII.** The firmware emits the name in plain low ASCII
  (`'A' = $41`), so compare against `!text "Appletini"` (which ACME emits as
  `$41 …`). Do **not** set the high bit on the comparison string.
- **Deriving the dispatch address portably.** This sample hard-codes
  `SP_ENTRY = $C70D`, which is correct for the current Appletini firmware
  (`$C7FF = $0A` → ProDOS entry `$C70A`, SmartPort entry `+3`). For maximum
  portability across SmartPort cards, read `$C7FF`, form the ProDOS entry
  `$C700 | ($C7FF)`, and call that address `+3`.
- **Controller vs device.** Using unit 0 is preferred for "is the card here at
  all", because the controller always responds regardless of mounted images.
  If you instead GETDIB a device unit (`$01`+), the text is `"Appletini HD"` and
  starts at `buffer+5`.
- **`SETSLOTCXROM`.** The `sta $C006` line is only meaningful on the //e family
  (it banks in peripheral-card ROM). It is harmless on a II/II+. If your code
  must preserve the prior `INTCXROM`/`SLOTCXROM` state, save it and restore it
  after the call.

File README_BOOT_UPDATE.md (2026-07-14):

# Boot and Firmware Update

Appletini One uses a permanent golden updater and one firmware slot in the
production 128 Mbit / 16 MB Quad SPI flash.

## Flash Layout

| Region | Offset | Size | Contents |
| --- | ---: | ---: | --- |
| Golden | `0x00000000` | `0x00200000` | `BOOT.BIN`: FSBL + `bootloader.elf` |
| Firmware | `0x00200000` | `0x00DF0000` | `FIRMWARE.BIN`: FSBL + bitstream + frontend |
| Metadata | `0x00FF0000` | `0x00010000` | Last verified update record |

The flash is configured as `qspi-x4-single`. Layout constants are defined in
`ps_sources/bootloader/updater_layout.c` and mirrored for the frontend in
`ps_sources/image_versions.h`.

## Boot Flow

1. Zynq BootROM loads the golden image at flash offset `0x00000000`.
2. Golden initializes UART, SD, and QSPI.
3. If the SD root contains `FIRMWARE.BIN`, golden validates and installs it.
4. Otherwise, golden boots the verified firmware slot.
5. If no verified firmware is available, golden remains in the serial monitor.

Golden selects the firmware slot through the Zynq multiboot register and a
software reset. The BootROM then loads the image at `0x00200000`.

## Update Guarantees

- The SD update path never erases or programs the golden region.
- The image must fit entirely inside the firmware slot.
- Every programmed byte is read back and checked before metadata is committed.
- A successful update renames `FIRMWARE.BIN` to `FIRMWARE.OK`.
- A failed update keeps `FIRMWARE.BIN` in place and does not mark the slot valid.
- Metadata is advisory; installation verifies the complete image.

Power loss can invalidate the single firmware slot. Recovery uses a valid
`FIRMWARE.BIN` on SD, the golden serial monitor, or direct QSPI programming.

## Serial Recovery

During golden's serial window, the host can interrupt automatic boot and send
an image with XMODEM-CRC. The helper handles the monitor protocol and can reboot
the running frontend into golden:

```bat
python scripts\serial_firmware_update.py .\FIRMWARE.BIN --port COM3 --reboot-golden
```

The uploaded image is written to SD and installed through the same verified
update path as a manually copied file.

## Release Check

1. Regenerate the Vivado project and export a fresh XSA.
2. Regenerate and build the Vitis workspace.
3. Build `BOOT.BIN` and `FIRMWARE.BIN` from those outputs.
4. Install `FIRMWARE.BIN` through golden and confirm readback verification.
5. Confirm `FIRMWARE.OK`, metadata, frontend version, golden version, and RTL version.
6. Reboot without an update file and confirm a direct firmware-slot boot.
7. Confirm that an invalid image is rejected without changing verified metadata.

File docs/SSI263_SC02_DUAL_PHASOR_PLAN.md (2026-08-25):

# Dual SSI-263 / SC-02 Phasor implementation plan

## Goal

Implement two independent SSI-263AP chips from the supplied SSI-263 data,
SC-02 schematic, and ROM. Use the original Applied Engineering Phasor socket,
clock, request, and audio-channel wiring. Do not retain any SC-01 or Votrax
speech code, table, map, timing rule, or compatibility path.

This plan treats sound quality as a test result, not as a design input. A change
to the speech engine must trace to the schematic, ROM, SSI-263 documents, or
original Phasor wiring. Do not add a phone-name rule or tune a capacitor ratio.

## Source order

Use these sources for separate parts of the design:

1. `sc-02_Final_Schematic_V1.00.pdf` defines the internal digital gates,
   counter paths, source routes, and ideal switched-capacitor network.
2. `ssi263a.bin` defines all phone data used by the selector engine.
3. The SSI-263A data sheet and programming guide define the host registers,
   A/R and D7 behavior, public clock laws, and P/AP reset behavior.
4. The original Applied Engineering Phasor manual, board photos, `mb-audit`,
   and the real-card AppleWin decode define card-level socket and request
   wiring.
5. Real SSI-263AP captures will set any term that the chip drawing does not
   define, such as absolute output voltage and nonideal analog response.

The 2020 SC-02 reconstruction also contains board changes used to make a
discrete build work. Keep its external amplifier, speaker, pot, and board-only
reset fixes outside the SSI-263 chip model.

## Supplied ROM identity and map

The source ROM is:

```text
C:\Users\hasse\OneDrive\Documents\Apple2\Appletini\Mockingboard\SC-02\ssi263a.bin
size:    2,048 bytes
CRC32:   CC0A72EE
SHA-256: 9C3BBA73319E1ED3652C85DAC19874DF04CBB72E62FDD63D6CBD7B34FF81F941
```

Offsets `000-1FF` contain the 512 active bytes. Offsets `200-7FF` are zero.
The lookup is exact:

```text
address = ((phone & 0x3f) << 3) | (selector & 7)
```

The upper nibble supplies the target, except selector 4 uses the host amplitude.
The target slots are:

| Selector | Target |
| ---: | --- |
| 0 | F1 frequency |
| 1 | F2 frequency |
| 2 | F2 resonance |
| 3 | shared F3 and F4 frequency code |
| 4 | filter amplitude, from the host amplitude register |
| 5 | voice amplitude |
| 6 | fricative amplitude |
| 7 | no parameter-state write |

The low ROM bits feed the drawn pulse and route logic. Sheet 5 uses these
timed latch rules:

```text
U38_equal = (U37.low == (TPARM0 ? 2 : 6))
PW0 set = U38_equal AND WR_SEL0
PW1 set = U38_equal AND WR_SEL1
PW0/PW1 clear while /PHO_WRITE is low, otherwise hold
PW2 = selector-2 TPARM2
PW5 = NOT selector-2 TPARM2
PW3 load = latched_CTRL OR NOT TPARM1
    when PW1 AND WR_SEL2; otherwise hold
```

U38 pin 6 reaches the U32A/U33A PW0/PW1 set-gate junction only. U11C pin 11
and U11A pin 8 share the PW1 net from U33D pin 11, so PW1, not U38, qualifies
the slot-2 PW3 load.

The decoded `/PHO_WRITE` condition at U29A is high while a phone write is
active; this is confirmed by its active-high U66/U23B reset uses. U37 advances
on U29A's falling edge at write assertion or DURCLK rise. DONE_RB holds a zero
U37 count at zero and wins a coincident clock. TPARM0 chooses the compare
delay; it is not PW0/PW1 data. The low bits
must not become an abstract voiced, fricative, stop, or phone-class decoder.

## Original Phasor wiring

Model the two populated sockets as follows:

- A5 selects the upper, secondary SSI-263 socket and Phasor channel A.
- A6 selects the lower, primary SSI-263 socket and Phasor channel B.
- A5+A6 writes both chips. A native dual-selected read keeps the proved A5
  D7 priority.
- In Mockingboard mode, each A/R output feeds its matching VIA CA1 input.
- In native Phasor mode, enabled A/R outputs feed the direct Apple IRQ route.
- Channel A and channel B remain separate. The FPGA audio convention sends A
  to left and B to right, but the original Phasor labels are A/B, not L/R.
- Echo+ hides the SSI host route without erasing either chip's state.

Both original sockets strap SSI pin 23, DIV2, to the pin 24 +5 V rail. The
implemented clock route uses Apple Q3 at about 2.045 MHz on XCK and asserted
DIV2, for an effective rate near 1.023 MHz. Both chips share that edge source
but share no die state. A Phasor mode change does not alter SSI XCK. The known
native-mode clock doubling applies to the AY chips, not to SSI XCK.

Board photos prove the DIV2 strap. A direct pin-22 continuity check or scope
capture remains useful proof of the Q3 trace and exact part-to-part rate; it is
not a reason to substitute a guessed clock.

## Host and reset contract

Each SSI-263AP implements:

- registers 0-3 and filter aliases 4-7;
- address and data capture at the end of the selected write condition;
- D7-only readback while D0-D6 remain outside the chip drive;
- active-low open-collector A/R;
- DR acknowledgement, repeat, CTL, and request behavior from the SSI data;
- AP `PD/RST` behavior driven by Apple RES;
- register retention where the AP source calls for it.

`card_enabled` is a virtual backplane boundary. It masks host writes, D7,
A/R, and audio at the wrapper. It does not reset either SSI die model. Only the
global FPGA reset initializes emulator state; Apple RES drives SSI `PD/RST`.

Keep these public timing laws:

```text
pitch_hz      = effective_XCK / (8 * (4096 - I))
filter_hz     = effective_XCK / (2 * (256 - FF))
durclk_ticks  = (4 - D) * 256 * (16 - R)
frame_ticks   = 4096 * (16 - R)
phone_ticks   = frame_ticks * (4 - D)
phone_ticks   = 16 * durclk_ticks
```

Sheet 5 supplies the request events directly. U28 loads `12+D` and makes the
sixteen DURCLK rises. U36 resets for a phone write and requests DONE when its
low nibble enters `F` in retained frame mode. U37 advances on the combined
U29A phone-write/DURCLK falling edge and requests DONE on `F->0` in retained
phoneme mode. U23B reset wins every collision. WR1/WR2 acknowledge only frame
mode; a phone write acknowledges both modes. These counters run without a
phone-active or power-down clock gate.

## Exact selector and transition work

Follow sheets 3-7 as a clocked circuit:

- U44 divides FASTCLK by four.
- U45 Q1 and Q2 drive the WRITE/LATCH timing gates. U45 Q3, Q4, and Q5 drive
  SEL0, SEL1, and SEL2.
- One selector slot lasts four SLOWCLK edges, or sixteen effective FASTCLK
  ticks.
- The full eight-slot scan lasts 128 effective FASTCLK ticks.
- U89, U88, U90, and U87 hold one `A`, `B`, `C`, and direction carry for each
  of the eight selector addresses. Selector 3 supplies the shared F3/F4 code;
  selector 7 still has DDA state but U96 never permits an `A` write there.
- During `A_CLR`, the circuit holds `A`, writes `B=(target-A) mod 16`, writes
  `C=8`, and records `CY=(target>=A)`. A phone write sets up all slots except
  slot 4. A control write sets up slots 5 and 6, and slot 4 when host amplitude
  is nonzero.
- On each later U96-permitted WRITE, `sum=B+C`, the low nibble returns to `C`,
  and `A` rises on carry when `CY=1` or falls on no carry when `CY=0`.
  `RESA_EQUALS` blocks writes after the target is reached.
- Prototype U96 uses `TCEDGE AND U32B` for slots 0, 1, and 3; `TCEDGE` for
  slot 2; `DUREDGE AND U166B./Q AND AMP_NONZERO` for slot 4;
  `PW0 AND RATEEDGE` and `PW1 AND RATEEDGE` for slots 5 and 6; and ground for
  slot 7. `U32B=NOT(PW5 AND (TPHO5 OR voice_nonzero OR fric_nonzero))`.
  `RATEEDGE=U93.Q3 AND NOT U93.Q4`, the sampled selected-rate rising edge.
- P2/R301 grounds the prototype's RATE=F option, so it contributes no U96
  override. A host write wins a same-edge data-path collision.
- Rate, duration, filter divider, inflection, and articulation follow their
  drawn immediate or stepped paths. Do not replace them with a smooth curve.

## Exact excitation work

### U60 glottal counter

U60 `/RST` and CET are tied high. U53C feeds `/VOICED` to CEP. P0 and P1 are
tied high, P2 is grounded, and P3 is tied high in the supplied drawing. U34A's
active parallel load therefore jams `1011`, not zero. The exact Phi1
recurrence is:

```text
q_next = U34_load ? 11 : (q == 15 ? 15 : q + 1)
VOICED = (q == 15)
```

U60 therefore advances `11..15`, then `/VOICED` lowers CEP and holds 15 until
the next U61/U34 load. The U118A/U201/C205 Phi1 transfer uses the post-clock
state at that same boundary: `14->15` selects the AGND source at once, and a
`15->11` parallel load selects the positive voice-amplitude source at once.
Do not add an asynchronous clear or a free-running wrap.

U61 `/CLR` is the physical `T/PD_/RST` net. Asserting `PD/RST` clears U61 and
the pending U34 load condition. It does not clear U60.

### U75 and U73 noise recurrence

U75 counts on each rising U41C edge. P0 is high and P1/P2/P3 are grounded, so
it jams `0001` after terminal count and the steady sequence is `1..15`, not
`0..15`. Use the post-rise U75 state for U42C:

```text
U42C = NOT(U75.Q2 OR U75.Q3)
```

The CD4006 U73 shifts on the following falling U41C edge. Preserve these
section connections:

```text
D1 input = D3+4
D2 input = D4+5
D3 input = D2+5
D4 input = U42C XOR D1+4 XOR D2+5 XOR D4+4 XOR D4+5
```

The source tap is U73 D3+4. The complete drawn fricative gate is:

```text
U104C     = PW3 AND U62./Q
FRICATIVE = NOT(D3+4 OR U104C)
             AND (U62./Q OR VOICE_AMP_ZERO)
```

U41C alone clocks this recurrence. Do not gate the noise register with an
invented `phone_active`, phone class, CTL, or `stop_class` signal.

### U68 and U85 amplitude/reset path

Implement the sheet-6 counter and reset path, not a decoded stop rule:

- U68 is a CD4029 in binary mode: B/D is tied to VCC and its jam inputs are
  grounded.
- U68 Q2-Q4 form `AMPCT1..3`; their NOR is `AMPCT_ZERO`.
- `U104C = PW3 AND U62./Q`; its inverse is the `AMPCT0` direction term.
- The voice- and fricative-amplitude zero tests take part in the shown count
  enable and direction gates.
- The gated SEL2 level clocks U68. Detect its full rising level because a gate
  can open while SEL2 is already high.
- U85C combines U104C with U68 `/CO` and drives the active-high U62 reset.

Test the complete count, direction, terminal, and U62-reset trace. No phone
name or `PW2 && !PW3` shortcut may replace it.

### Parameter and phase latches

Keep the three drawn storage layers: per-selector RESA in U89, the selected
U106-U114 first-stage latch during LATCH, and the U170-U176 phase latch. Pass
F1/F3/voice only in Phi0_X and F2/F2-res/F4/fricative only in Phi1_X.

Gate raw U111 filter amplitude through U70 with AMPCT3:0, then capture it in
U206 only on the positive Phi0 edge.

### U20B, U112, and U166 route state

Keep the two fricative switches as separate state:

- the gated WR_SEL2 edge clocks TPARM3 into U20B through the shown PW0, PW1,
  PW2, `AMPCT_ZERO`, and `FRIC_AMP_ZERO` terms;
- U112 is transparent while Phi1_X is high and produces `FRIC1_SW` from U20B;
- U166A samples the complement of U20B on the positive Phi0_X edge and holds
  `FRIC2_SW`.

Do not assign one switch from a ROM bit and the other to its direct inverse.
Their separate clocks and held state are part of the circuit.
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

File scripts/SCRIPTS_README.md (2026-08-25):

# Build and Utility Scripts

Run scripts from the repository root unless a script's help says otherwise.

## Hardware

- `create_project.tcl`: recreate the Vivado project from `hdl/hdl_sources.txt`.
- `build_and_export_xsa.tcl`: synthesize, implement, write the bitstream, and
  export `project/appletini_yarz_top.xsa`.
- `create_vitis_workspace.py`: recreate the Vitis platform, golden updater,
  CPU1 renderer, and frontend applications from `ps_sources/`.

```bat
vivado -mode batch -source scripts/create_project.tcl
vivado -mode batch -source scripts/build_and_export_xsa.tcl
vitis -s .\scripts\create_vitis_workspace.py
```

Use the known-good checkpoint for normal small changes. For a large netlist
change, first recreate the project, then request a full build:

```powershell
vivado -mode batch -source scripts/create_project.tcl
$env:APPLETINI_FULL_BUILD = "1"
vivado -mode batch -source scripts/build_and_export_xsa.tcl
Remove-Item Env:APPLETINI_FULL_BUILD
```
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

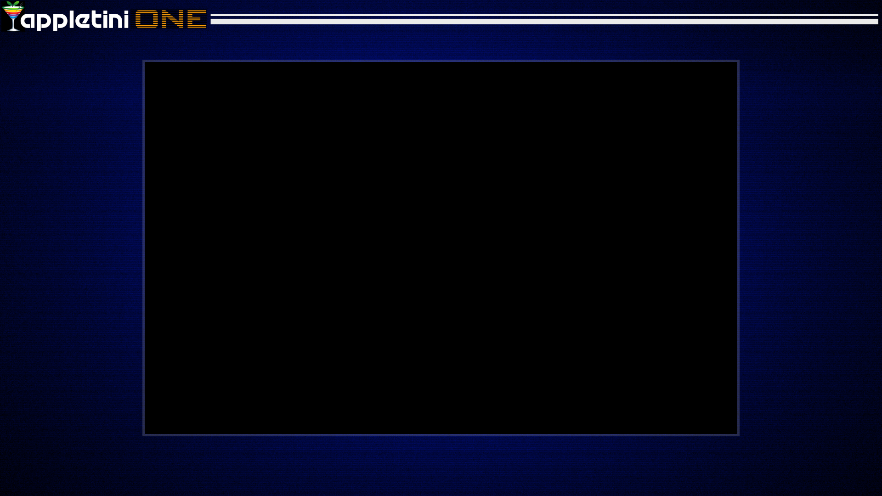
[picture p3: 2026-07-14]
Assets/Bezels/bezel_blue_phosphor.png

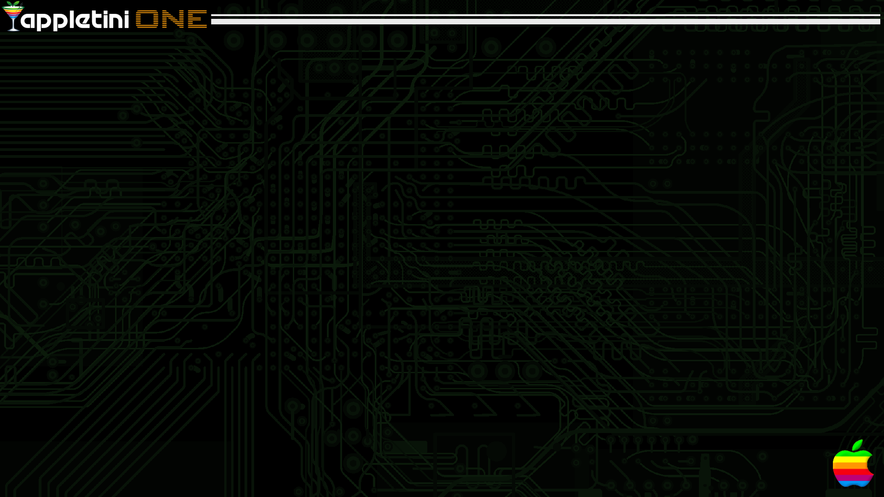
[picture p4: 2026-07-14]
Assets/Bezels/bezel.png

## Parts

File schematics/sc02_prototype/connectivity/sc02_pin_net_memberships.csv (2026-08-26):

sheet_name | page_number | component_ref | physical_ref | unit_suffix | pin_id | pin_number | net_name | implicit | component_anchor_count | component_anchor_x0_points | component_anchor_y0_points | component_anchor_x1_points | component_anchor_y1_points | component_anchor_center_x_points | component_anchor_center_y_points | pin_anchor_count | pin_anchor_x0_points | pin_anchor_y0_points | pin_anchor_x1_points | pin_anchor_y1_points | pin_anchor_center_x_points | pin_anchor_center_y_points
analog_1.SchDoc | 1 | C10A | C10A |  | C10A-1 | 1 | NetC10A_1 | false | 1 | 583.0 | 168.282 | 588.0 | 172.03 | 585.5 | 170.156 | 1 | 580.0 | 172.521 | 583.0 | 175.02 | 581.5 | 173.77
analog_1.SchDoc | 1 | C10A | C10A |  | C10A-2 | 2 | NetC10A_2 | false | 1 | 583.0 | 168.282 | 588.0 | 172.03 | 585.5 | 170.156 | 1 | 585.0 | 172.521 | 588.0 | 175.02 | 586.5 | 173.77
analog_1.SchDoc | 1 | C10B | C10B |  | C10B-1 | 1 | NetC10A_1 | false | 1 | 583.0 | 181.521 | 588.0 | 184.02 | 585.5 | 182.77 | 1 | 580.0 | 184.521 | 583.0 | 187.02 | 581.5 | 185.77
analog_1.SchDoc | 1 | C10B | C10B |  | C10B-2 | 2 | NetC10A_2 | false | 1 | 583.0 | 181.521 | 588.0 | 184.02 | 585.5 | 182.77 | 1 | 585.0 | 184.521 | 588.0 | 187.02 | 586.5 | 185.77
analog_1.SchDoc | 1 | C11A | C11A |  | C11A-1 | 1 | NetC10A_1 | false | 1 | 583.0 | 198.521 | 588.0 | 201.02 | 585.5 | 199.77 | 1 | 580.0 | 202.76 | 583.0 | 204.01 | 581.5 | 203.385
analog_1.SchDoc | 1 | C11A | C11A |  | C11A-2 | 2 | NetC11A_2 | false | 1 | 583.0 | 198.521 | 588.0 | 201.02 | 585.5 | 199.77 | 1 | 585.0 | 202.76 | 588.0 | 204.01 | 586.5 | 203.385
analog_1.SchDoc | 1 | C11B | C11B |  | C11B-1 | 1 | NetC10A_1 | false | 1 | 583.0 | 210.521 | 588.0 | 213.02 | 585.5 | 211.77 | 1 | 580.0 | 214.76 | 583.0 | 216.01 | 581.5 | 215.385
analog_1.SchDoc | 1 | C11B | C11B |  | C11B-2 | 2 | NetC11A_2 | false | 1 | 583.0 | 210.521 | 588.0 | 213.02 | 585.5 | 211.77 | 1 | 585.0 | 214.76 | 588.0 | 216.01 | 586.5 | 215.385
analog_1.SchDoc | 1 | C12A | C12A |  | C12A-1 | 1 | NetC10A_1 | false | 1 | 583.0 | 227.521 | 588.0 | 230.02 | 585.5 | 228.77 | 1 | 580.0 | 231.76 | 583.0 | 233.01 | 581.5 | 232.385
analog_1.SchDoc | 1 | C12A | C12A |  | C12A-2 | 2 | NetC12A_2 | false | 1 | 583.0 | 227.521 | 588.0 | 230.02 | 585.5 | 228.77 | 1 | 585.0 | 231.76 | 588.0 | 233.01 | 586.5 | 232.385
analog_1.SchDoc | 1 | C12B | C12B |  | C12B-1 | 1 | NetC10A_1 | false | 1 | 583.0 | 239.282 | 588.0 | 243.03 | 585.5 | 241.156 | 1 | 580.0 | 243.76 | 583.0 | 245.01 | 581.5 | 244.385
analog_1.SchDoc | 1 | C12B | C12B |  | C12B-2 | 2 | NetC12A_2 | false | 1 | 583.0 | 239.282 | 588.0 | 243.03 | 585.5 | 241.156 | 1 | 585.0 | 243.76 | 588.0 | 245.01 | 586.5 | 244.385
analog_1.SchDoc | 1 | C13A | C13A |  | C13A-1 | 1 | NetC10A_1 | false | 1 | 583.0 | 256.282 | 588.0 | 260.03 | 585.5 | 258.156 | 1 | 580.0 | 260.521 | 583.0 | 263.02 | 581.5 | 261.77
analog_1.SchDoc | 1 | C13A | C13A |  | C13A-2 | 2 | NetC13A_2 | false | 1 | 583.0 | 256.282 | 588.0 | 260.03 | 585.5 | 258.156 | 1 | 585.0 | 260.521 | 588.0 | 263.02 | 586.5 | 261.77
analog_1.SchDoc | 1 | C13B | C13B |  | C13B-1 | 1 | NetC10A_1 | false | 1 | 583.0 | 268.282 | 588.0 | 272.03 | 585.5 | 270.156 | 1 | 580.0 | 272.521 | 583.0 | 275.02 | 581.5 | 273.77
analog_1.SchDoc | 1 | C13B | C13B |  | C13B-2 | 2 | NetC13A_2 | false | 1 | 583.0 | 268.282 | 588.0 | 272.03 | 585.5 | 270.156 | 1 | 585.0 | 272.521 | 588.0 | 275.02 | 586.5 | 273.77
analog_1.SchDoc | 1 | C20A | C20A |  | C20A-1 | 1 | NetC20A_1 | false | 1 | 207.0 | 280.282 | 212.001 | 284.03 | 209.5 | 282.156 | 1 | 204.0 | 284.521 | 208.0 | 287.02 | 206.0 | 285.77
analog_1.SchDoc | 1 | C20A | C20A |  | C20A-2 | 2 | NetC20A_2 | false | 1 | 207.0 | 280.282 | 212.001 | 284.03 | 209.5 | 282.156 | 1 | 209.0 | 284.521 | 213.0 | 287.02 | 211.0 | 285.77
analog_1.SchDoc | 1 | C20B | C20B |  | C20B-1 | 1 | NetC20A_1 | false | 1 | 207.0 | 293.521 | 212.0 | 296.02 | 209.5 | 294.77 | 1 | 204.0 | 297.76 | 208.0 | 299.01 | 206.0 | 298.385
analog_1.SchDoc | 1 | C20B | C20B |  | C20B-2 | 2 | NetC20A_2 | false | 1 | 207.0 | 293.521 | 212.0 | 296.02 | 209.5 | 294.77 | 1 | 209.0 | 297.76 | 213.0 | 299.01 | 211.0 | 298.385
analog_1.SchDoc | 1 | C21A | C21A |  | C21A-1 | 1 | NetC20A_1 | false | 1 | 207.0 | 310.521 | 212.0 | 313.02 | 209.5 | 311.77 | 1 | 204.0 | 314.76 | 208.0 | 316.01 | 206.0 | 315.385
analog_1.SchDoc | 1 | C21A | C21A |  | C21A-2 | 2 | NetC21A_2 | false | 1 | 207.0 | 310.521 | 212.0 | 313.02 | 209.5 | 311.77 | 1 | 209.0 | 314.76 | 213.0 | 316.01 | 211.0 | 315.385
analog_1.SchDoc | 1 | C21B | C21B |  | C21B-1 | 1 | NetC20A_1 | false | 1 | 207.0 | 322.521 | 212.0 | 325.02 | 209.5 | 323.77 | 1 | 204.0 | 326.76 | 208.0 | 328.01 | 206.0 | 327.385
analog_1.SchDoc | 1 | C21B | C21B |  | C21B-2 | 2 | NetC21A_2 | false | 1 | 207.0 | 322.521 | 212.0 | 325.02 | 209.5 | 323.77 | 1 | 209.0 | 326.76 | 213.0 | 328.01 | 211.0 | 327.385
analog_1.SchDoc | 1 | C22A | C22A |  | C22A-1 | 1 | NetC20A_1 | false | 1 | 207.0 | 339.521 | 212.0 | 342.02 | 209.5 | 340.77 | 1 | 204.0 | 343.76 | 208.0 | 345.01 | 206.0 | 344.385
analog_1.SchDoc | 1 | C22A | C22A |  | C22A-2 | 2 | NetC22A_2 | false | 1 | 207.0 | 339.521 | 212.0 | 342.02 | 209.5 | 340.77 | 1 | 209.0 | 343.76 | 213.0 | 345.01 | 211.0 | 344.385
analog_1.SchDoc | 1 | C22B | C22B |  | C22B-1 | 1 | NetC20A_1 | false | 1 | 207.0 | 351.282 | 212.001 | 355.03 | 209.5 | 353.156 | 1 | 204.0 | 355.521 | 208.0 | 358.02 | 206.0 | 356.77
analog_1.SchDoc | 1 | C22B | C22B |  | C22B-2 | 2 | NetC22A_2 | false | 1 | 207.0 | 351.282 | 212.001 | 355.03 | 209.5 | 353.156 | 1 | 209.0 | 355.521 | 213.0 | 358.02 | 211.0 | 356.77
analog_1.SchDoc | 1 | C23A | C23A |  | C23A-1 | 1 | NetC20A_1 | false | 1 | 207.0 | 368.282 | 212.001 | 372.03 | 209.5 | 370.156 | 1 | 204.0 | 372.521 | 208.0 | 375.02 | 206.0 | 373.77
analog_1.SchDoc | 1 | C23A | C23A |  | C23A-2 | 2 | NetC23A_2 | false | 1 | 207.0 | 368.282 | 212.001 | 372.03 | 209.5 | 370.156 | 1 | 209.0 | 372.521 | 213.0 | 375.02 | 211.0 | 373.77
analog_1.SchDoc | 1 | C23B | C23B |  | C23B-1 | 1 | NetC20A_1 | false | 1 | 207.0 | 381.521 | 212.0 | 384.02 | 209.5 | 382.77 | 1 | 204.0 | 384.521 | 208.0 | 387.02 | 206.0 | 385.77
analog_1.SchDoc | 1 | C23B | C23B |  | C23B-2 | 2 | NetC23A_2 | false | 1 | 207.0 | 381.521 | 212.0 | 384.02 | 209.5 | 382.77 | 1 | 209.0 | 384.521 | 213.0 | 387.02 | 211.0 | 385.77
analog_1.SchDoc | 1 | C30A | C30A |  | C30A-1 | 1 | NetC30A_1 | false | 1 | 583.0 | 337.521 | 588.0 | 340.02 | 585.5 | 338.77 | 1 | 580.0 | 340.521 | 583.0 | 343.02 | 581.5 | 341.77
analog_1.SchDoc | 1 | C30A | C30A |  | C30A-2 | 2 | NetC30A_2 | false | 1 | 583.0 | 337.521 | 588.0 | 340.02 | 585.5 | 338.77 | 1 | 585.0 | 340.521 | 588.0 | 343.02 | 586.5 | 341.77
analog_1.SchDoc | 1 | C30B | C30B |  | C30B-1 | 1 | NetC30A_1 | false | 1 | 583.0 | 349.521 | 588.0 | 352.02 | 585.5 | 350.77 | 1 | 580.0 | 353.76 | 583.0 | 355.01 | 581.5 | 354.385
analog_1.SchDoc | 1 | C30B | C30B |  | C30B-2 | 2 | NetC30A_2 | false | 1 | 583.0 | 349.521 | 588.0 | 352.02 | 585.5 | 350.77 | 1 | 585.0 | 353.76 | 588.0 | 355.01 | 586.5 | 354.385
analog_1.SchDoc | 1 | C31A | C31A |  | C31A-1 | 1 | NetC30A_1 | false | 1 | 583.0 | 366.521 | 588.0 | 369.02 | 585.5 | 367.77 | 1 | 580.0 | 370.76 | 583.0 | 372.01 | 581.5 | 371.385
analog_1.SchDoc | 1 | C31A | C31A |  | C31A-2 | 2 | NetC31A_2 | false | 1 | 583.0 | 366.521 | 588.0 | 369.02 | 585.5 | 367.77 | 1 | 585.0 | 370.76 | 588.0 | 372.01 | 586.5 | 371.385
analog_1.SchDoc | 1 | C31B | C31B |  | C31B-1 | 1 | NetC30A_1 | false | 1 | 583.0 | 378.282 | 588.0 | 382.03 | 585.5 | 380.156 | 1 | 580.0 | 382.76 | 583.0 | 384.01 | 581.5 | 383.385
analog_1.SchDoc | 1 | C31B | C31B |  | C31B-2 | 2 | NetC31A_2 | false | 1 | 583.0 | 378.282 | 588.0 | 382.03 | 585.5 | 380.156 | 1 | 585.0 | 382.76 | 588.0 | 384.01 | 586.5 | 383.385
analog_1.SchDoc | 1 | C32A | C32A |  | C32A-1 | 1 | NetC30A_1 | false | 1 | 583.0 | 395.282 | 588.0 | 399.03 | 585.5 | 397.156 | 1 | 580.0 | 399.76 | 583.0 | 401.01 | 581.5 | 400.385
analog_1.SchDoc | 1 | C32A | C32A |  | C32A-2 | 2 | NetC32A_2 | false | 1 | 583.0 | 395.282 | 588.0 | 399.03 | 585.5 | 397.156 | 1 | 585.0 | 399.76 | 588.0 | 401.01 | 586.5 | 400.385
analog_1.SchDoc | 1 | C32B | C32B |  | C32B-1 | 1 | NetC30A_1 | false | 1 | 583.0 | 407.282 | 588.0 | 411.03 | 585.5 | 409.156 | 1 | 580.0 | 411.521 | 583.0 | 414.02 | 581.5 | 412.77
analog_1.SchDoc | 1 | C32B | C32B |  | C32B-2 | 2 | NetC32A_2 | false | 1 | 583.0 | 407.282 | 588.0 | 411.03 | 585.5 | 409.156 | 1 | 585.0 | 411.521 | 588.0 | 414.02 | 586.5 | 412.77
analog_1.SchDoc | 1 | C33A | C33A |  | C33A-1 | 1 | NetC30A_1 | false | 1 | 583.0 | 424.282 | 588.0 | 428.03 | 585.5 | 426.156 | 1 | 580.0 | 428.521 | 583.0 | 431.02 | 581.5 | 429.77
analog_1.SchDoc | 1 | C33A | C33A |  | C33A-2 | 2 | NetC33A_2 | false | 1 | 583.0 | 424.282 | 588.0 | 428.03 | 585.5 | 426.156 | 1 | 585.0 | 428.521 | 588.0 | 431.02 | 586.5 | 429.77
analog_1.SchDoc | 1 | C33B | C33B |  | C33B-1 | 1 | NetC30A_1 | false | 1 | 583.0 | 436.282 | 588.0 | 440.03 | 585.5 | 438.156 | 1 | 580.0 | 441.76 | 583.0 | 443.01 | 581.5 | 442.385
analog_1.SchDoc | 1 | C33B | C33B |  | C33B-2 | 2 | NetC33A_2 | false | 1 | 583.0 | 436.282 | 588.0 | 440.03 | 585.5 | 438.156 | 1 | 585.0 | 441.76 | 588.0 | 443.01 | 586.5 | 442.385
analog_1.SchDoc | 1 | C101A | C101A |  | C101A-1 | 1 | NetC30A_1 | false | 1 | 583.0 | 454.521 | 589.0 | 457.02 | 586.0 | 455.77 | 1 | 580.0 | 458.76 | 583.0 | 460.01 | 581.5 | 459.385
analog_1.SchDoc | 1 | C101A | C101A |  | C101A-2 | 2 | NetC101A_2 | false | 1 | 583.0 | 454.521 | 589.0 | 457.02 | 586.0 | 455.77 | 1 | 585.0 | 458.76 | 588.0 | 460.01 | 586.5 | 459.385
analog_1.SchDoc | 1 | C101B | C101B |  | C101B-1 | 1 | NetC30A_1 | false | 1 | 583.0 | 466.521 | 589.0 | 469.02 | 586.0 | 467.77 | 1 | 580.0 | 470.76 | 583.0 | 472.01 | 581.5 | 471.385
analog_1.SchDoc | 1 | C101B | C101B |  | C101B-2 | 2 | NetC101A_2 | false | 1 | 583.0 | 466.521 | 589.0 | 469.02 | 586.0 | 467.77 | 1 | 585.0 | 470.76 | 588.0 | 472.01 | 586.5 | 471.385
analog_1.SchDoc | 1 | C102A | C102A |  | C102A-1 | 1 | NetC102A_1 | false | 1 | 553.0 | 337.521 | 560.0 | 340.02 | 556.5 | 338.77 | 1 | 551.0 | 340.521 | 554.0 | 343.02 | 552.5 | 341.77
analog_1.SchDoc | 1 | C102A | C102A |  | C102A-2 | 2 | NetC30A_1 | false | 1 | 553.0 | 337.521 | 560.0 | 340.02 | 556.5 | 338.77 | 1 | 556.0 | 340.521 | 559.0 | 343.02 | 557.5 | 341.77
analog_1.SchDoc | 1 | C102B | C102B |  | C102B-1 | 1 | NetC102A_1 | false | 1 | 553.0 | 349.521 | 560.0 | 352.02 | 556.5 | 350.77 | 1 | 551.0 | 353.76 | 554.0 | 355.01 | 552.5 | 354.385
analog_1.SchDoc | 1 | C102B | C102B |  | C102B-2 | 2 | NetC30A_1 | false | 1 | 553.0 | 349.521 | 560.0 | 352.02 | 556.5 | 350.77 | 1 | 556.0 | 353.76 | 559.0 | 355.01 | 557.5 | 354.385
analog_1.SchDoc | 1 | C103A | C103A |  | C103A-1 | 1 | NetC103A_1 | false | 1 | 739.0 | 402.282 | 745.0 | 406.03 | 742.0 | 404.156 | 1 | 736.0 | 406.522 | 739.0 | 409.02 | 737.5 | 407.771
analog_1.SchDoc | 1 | C103A | C103A |  | C103A-2 | 2 | F3_OUT | false | 1 | 739.0 | 402.282 | 745.0 | 406.03 | 742.0 | 404.156 | 1 | 741.0 | 406.522 | 744.0 | 409.02 | 742.5 | 407.771
analog_1.SchDoc | 1 | C103B | C103B |  | C103B-1 | 1 | NetC103A_1 | false | 1 | 739.0 | 415.521 | 745.0 | 418.02 | 742.0 | 416.77 | 1 | 736.0 | 418.522 | 739.0 | 421.02 | 737.5 | 419.771
analog_1.SchDoc | 1 | C103B | C103B |  | C103B-2 | 2 | F3_OUT | false | 1 | 739.0 | 415.521 | 745.0 | 418.02 | 742.0 | 416.77 | 1 | 741.0 | 418.522 | 744.0 | 421.02 | 742.5 | 419.771
analog_1.SchDoc | 1 | C104A | C104A |  | C104A-1 | 1 | NetC104A_1 | false | 1 | 431.0 | 453.521 | 438.0 | 456.02 | 434.5 | 454.77 | 1 | 429.0 | 455.044 | 430.001 | 460.04 | 429.5 | 457.542
analog_1.SchDoc | 1 | C104A | C104A |  | C104A-2 | 2 | NetC102A_1 | false | 1 | 431.0 | 453.521 | 438.0 | 456.02 | 434.5 | 454.77 | 1 | 429.0 | 450.044 | 430.001 | 455.04 | 429.5 | 452.542
analog_1.SchDoc | 1 | C104B | C104B |  | C104B-1 | 1 | NetC104A_1 | false | 1 | 444.0 | 453.521 | 450.0 | 456.02 | 447.0 | 454.77 | 1 | 441.0 | 455.044 | 442.001 | 460.04 | 441.5 | 457.542
analog_1.SchDoc | 1 | C104B | C104B |  | C104B-2 | 2 | NetC102A_1 | false | 1 | 444.0 | 453.521 | 450.0 | 456.02 | 447.0 | 454.77 | 1 | 441.0 | 450.044 | 442.001 | 455.04 | 441.5 | 452.542
analog_1.SchDoc | 1 | C105A | C105A |  | C105A-1 | 1 | NetC105A_1 | false | 1 | 497.0 | 398.521 | 504.0 | 401.02 | 500.5 | 399.77 | 1 | 495.0 | 401.522 | 498.0 | 404.02 | 496.5 | 402.771
analog_1.SchDoc | 1 | C105A | C105A |  | C105A-2 | 2 | NetC105A_2 | false | 1 | 497.0 | 398.521 | 504.0 | 401.02 | 500.5 | 399.77 | 1 | 500.0 | 401.522 | 503.0 | 404.02 | 501.5 | 402.771
analog_1.SchDoc | 1 | C105B | C105B |  | C105B-1 | 1 | NetC105A_1 | false | 1 | 497.0 | 410.521 | 503.0 | 413.02 | 500.0 | 411.77 | 1 | 495.0 | 414.76 | 498.0 | 416.01 | 496.5 | 415.385
analog_1.SchDoc | 1 | C105B | C105B |  | C105B-2 | 2 | NetC105A_2 | false | 1 | 497.0 | 410.521 | 503.0 | 413.02 | 500.0 | 411.77 | 1 | 500.0 | 414.76 | 503.0 | 416.01 | 501.5 | 415.385
analog_1.SchDoc | 1 | C106A | C106A |  | C106A-1 | 1 | NetC106A_1 | false | 1 | 190.0 | 368.282 | 197.001 | 372.03 | 193.5 | 370.156 | 1 | 187.0 | 372.521 | 191.0 | 375.02 | 189.0 | 373.77
analog_1.SchDoc | 1 | C106A | C106A |  | C106A-2 | 2 | NetC20A_1 | false | 1 | 190.0 | 368.282 | 197.001 | 372.03 | 193.5 | 370.156 | 1 | 192.0 | 372.521 | 196.0 | 375.02 | 194.0 | 373.77
analog_1.SchDoc | 1 | C106B | C106B |  | C106B-1 | 1 | NetC106A_1 | false | 1 | 190.0 | 381.521 | 196.0 | 384.02 | 193.0 | 382.77 | 1 | 187.0 | 384.521 | 191.0 | 387.02 | 189.0 | 385.77
analog_1.SchDoc | 1 | C106B | C106B |  | C106B-2 | 2 | NetC20A_1 | false | 1 | 190.0 | 381.521 | 196.0 | 384.02 | 193.0 | 382.77 | 1 | 192.0 | 384.521 | 196.0 | 387.02 | 194.0 | 385.77
analog_1.SchDoc | 1 | C107A | C107A |  | C107A-1 | 1 | NetC107A_1 | false | 1 | 190.0 | 339.521 | 197.0 | 342.02 | 193.5 | 340.77 | 1 | 187.0 | 343.76 | 191.0 | 345.01 | 189.0 | 344.385
analog_1.SchDoc | 1 | C107A | C107A |  | C107A-2 | 2 | NetC20A_1 | false | 1 | 190.0 | 339.521 | 197.0 | 342.02 | 193.5 | 340.77 | 1 | 192.0 | 343.76 | 196.0 | 345.01 | 194.0 | 344.385
analog_1.SchDoc | 1 | C107B | C107B |  | C107B-1 | 1 | NetC107A_1 | false | 1 | 190.0 | 351.282 | 196.001 | 355.03 | 193.0 | 353.156 | 1 | 187.0 | 355.521 | 191.0 | 358.02 | 189.0 | 356.77
analog_1.SchDoc | 1 | C107B | C107B |  | C107B-2 | 2 | NetC20A_1 | false | 1 | 190.0 | 351.282 | 196.001 | 355.03 | 193.0 | 353.156 | 1 | 192.0 | 355.521 | 196.0 | 358.02 | 194.0 | 356.77
analog_1.SchDoc | 1 | C108A | C108A |  | C108A-1 | 1 | NetC108A_1 | false | 1 | 190.0 | 310.521 | 197.0 | 313.02 | 193.5 | 311.77 | 1 | 187.0 | 314.76 | 191.0 | 316.01 | 189.0 | 315.385
analog_1.SchDoc | 1 | C108A | C108A |  | C108A-2 | 2 | NetC20A_1 | false | 1 | 190.0 | 310.521 | 197.0 | 313.02 | 193.5 | 311.77 | 1 | 192.0 | 314.76 | 196.0 | 316.01 | 194.0 | 315.385
analog_1.SchDoc | 1 | C108B | C108B |  | C108B-1 | 1 | NetC108A_1 | false | 1 | 190.0 | 322.521 | 196.0 | 325.02 | 193.0 | 323.77 | 1 | 187.0 | 326.76 | 191.0 | 328.01 | 189.0 | 327.385
analog_1.SchDoc | 1 | C108B | C108B |  | C108B-2 | 2 | NetC20A_1 | false | 1 | 190.0 | 322.521 | 196.0 | 325.02 | 193.0 | 323.77 | 1 | 192.0 | 326.76 | 196.0 | 328.01 | 194.0 | 327.385
analog_1.SchDoc | 1 | C109A | C109A |  | C109A-1 | 1 | NetC109A_1 | false | 1 | 190.0 | 280.282 | 197.001 | 284.03 | 193.5 | 282.156 | 1 | 187.0 | 284.521 | 191.0 | 287.02 | 189.0 | 285.77
analog_1.SchDoc | 1 | C109A | C109A |  | C109A-2 | 2 | NetC20A_1 | false | 1 | 190.0 | 280.282 | 197.001 | 284.03 | 193.5 | 282.156 | 1 | 192.0 | 284.521 | 196.0 | 287.02 | 194.0 | 285.77
analog_1.SchDoc | 1 | C109B | C109B |  | C109B-1 | 1 | NetC109A_1 | false | 1 | 190.0 | 293.521 | 196.0 | 296.02 | 193.0 | 294.77 | 1 | 187.0 | 297.76 | 191.0 | 299.01 | 189.0 | 298.385
analog_1.SchDoc | 1 | C109B | C109B |  | C109B-2 | 2 | NetC20A_1 | false | 1 | 190.0 | 293.521 | 196.0 | 296.02 | 193.0 | 294.77 | 1 | 192.0 | 297.76 | 196.0 | 299.01 | 194.0 | 298.385
analog_1.SchDoc | 1 | C110A | C110A |  | C110A-1 | 1 | NetC110A_1 | false | 1 | 368.0 | 432.521 | 374.0 | 435.02 | 371.0 | 433.77 | 1 | 365.0 | 436.76 | 369.0 | 438.01 | 367.0 | 437.385
analog_1.SchDoc | 1 | C110A | C110A |  | C110A-2 | 2 | NetC110A_2 | false | 1 | 368.0 | 432.521 | 374.0 | 435.02 | 371.0 | 433.77 | 1 | 370.0 | 436.76 | 374.0 | 438.01 | 372.0 | 437.385
analog_1.SchDoc | 1 | C110B | C110B |  | C110B-1 | 1 | NetC110A_1 | false | 1 | 368.0 | 444.521 | 374.0 | 447.02 | 371.0 | 445.77 | 1 | 365.0 | 448.76 | 369.0 | 450.01 | 367.0 | 449.385
analog_1.SchDoc | 1 | C110B | C110B |  | C110B-2 | 2 | NetC110A_2 | false | 1 | 368.0 | 444.521 | 374.0 | 447.02 | 371.0 | 445.77 | 1 | 370.0 | 448.76 | 374.0 | 450.01 | 372.0 | 449.385
analog_1.SchDoc | 1 | C111A | C111A |  | C111A-1 | 1 | NetC20A_1 | false | 1 | 207.0 | 398.521 | 214.0 | 401.02 | 210.5 | 399.77 | 1 | 204.0 | 401.521 | 208.0 | 404.02 | 206.0 | 402.77
analog_1.SchDoc | 1 | C111A | C111A |  | C111A-2 | 2 | FRIC_1 | false | 1 | 207.0 | 398.521 | 214.0 | 401.02 | 210.5 | 399.77 | 1 | 209.0 | 401.521 | 213.0 | 404.02 | 211.0 | 402.77
analog_1.SchDoc | 1 | C111B | C111B |  | C111B-1 | 1 | NetC20A_1 | false | 1 | 207.0 | 410.521 | 213.0 | 413.02 | 210.0 | 411.77 | 1 | 204.0 | 414.76 | 208.0 | 416.01 | 206.0 | 415.385
analog_1.SchDoc | 1 | C111B | C111B |  | C111B-2 | 2 | FRIC_1 | false | 1 | 207.0 | 410.521 | 213.0 | 413.02 | 210.0 | 411.77 | 1 | 209.0 | 414.76 | 213.0 | 416.01 | 211.0 | 415.385
analog_1.SchDoc | 1 | C112A | C112A |  | C112A-1 | 1 | NetC112A_1 | false | 1 | 190.0 | 398.521 | 197.0 | 401.02 | 193.5 | 399.77 | 1 | 187.0 | 401.521 | 191.0 | 404.02 | 189.0 | 402.77
analog_1.SchDoc | 1 | C112A | C112A |  | C112A-2 | 2 | NetC20A_1 | false | 1 | 190.0 | 398.521 | 197.0 | 401.02 | 193.5 | 399.77 | 1 | 192.0 | 401.521 | 196.0 | 404.02 | 194.0 | 402.77
analog_1.SchDoc | 1 | C112B | C112B |  | C112B-1 | 1 | NetC112A_1 | false | 1 | 190.0 | 410.521 | 196.0 | 413.02 | 193.0 | 411.77 | 1 | 187.0 | 414.76 | 191.0 | 416.01 | 189.0 | 415.385
analog_1.SchDoc | 1 | C112B | C112B |  | C112B-2 | 2 | NetC20A_1 | false | 1 | 190.0 | 410.521 | 196.0 | 413.02 | 193.0 | 411.77 | 1 | 192.0 | 414.76 | 196.0 | 416.01 | 194.0 | 415.385
analog_1.SchDoc | 1 | C121A | C121A |  | C121A-1 | 1 | NetC121A_1 | false | 1 | 502.0 | 93.521 | 509.0 | 96.02 | 505.5 | 94.77 | 1 | 500.0 | 97.76 | 503.0 | 99.01 | 501.5 | 98.385
analog_1.SchDoc | 1 | C121A | C121A |  | C121A-2 | 2 | NetC121A_2 | false | 1 | 502.0 | 93.521 | 509.0 | 96.02 | 505.5 | 94.77 | 1 | 504.0 | 97.76 | 508.0 | 99.01 | 506.0 | 98.385
analog_1.SchDoc | 1 | C121B | C121B |  | C121B-1 | 1 | NetC121A_1 | false | 1 | 502.0 | 105.521 | 508.0 | 108.02 | 505.0 | 106.77 | 1 | 500.0 | 109.76 | 503.0 | 111.01 | 501.5 | 110.385
analog_1.SchDoc | 1 | C121B | C121B |  | C121B-2 | 2 | NetC121A_2 | false | 1 | 502.0 | 105.521 | 508.0 | 108.02 | 505.0 | 106.77 | 1 | 504.0 | 109.76 | 508.0 | 111.01 | 506.0 | 110.385
analog_1.SchDoc | 1 | C122A | C122A |  | C122A-1 | 1 | NetC10A_1 | false | 1 | 583.0 | 285.282 | 589.0 | 289.03 | 586.0 | 287.156 | 1 | 580.0 | 289.521 | 583.0 | 292.02 | 581.5 | 290.77
analog_1.SchDoc | 1 | C122A | C122A |  | C122A-2 | 2 | NetC122A_2 | false | 1 | 583.0 | 285.282 | 589.0 | 289.03 | 586.0 | 287.156 | 1 | 585.0 | 289.521 | 588.0 | 292.02 | 586.5 | 290.77
analog_1.SchDoc | 1 | C122B | C122B |  | C122B-1 | 1 | NetC10A_1 | false | 1 | 583.0 | 298.521 | 589.0 | 301.02 | 586.0 | 299.77 | 1 | 580.0 | 302.76 | 583.0 | 304.01 | 581.5 | 303.385
analog_1.SchDoc | 1 | C122B | C122B |  | C122B-2 | 2 | NetC122A_2 | false | 1 | 583.0 | 298.521 | 589.0 | 301.02 | 586.0 | 299.77 | 1 | 585.0 | 302.76 | 588.0 | 304.01 | 586.5 | 303.385
analog_1.SchDoc | 1 | C124A | C124A |  | C124A-1 | 1 | NetC124A_1 | false | 1 | 719.0 | 166.521 | 725.0 | 169.02 | 722.0 | 167.77 | 1 | 717.0 | 170.76 | 720.0 | 172.01 | 718.5 | 171.385
analog_1.SchDoc | 1 | C124A | C124A |  | C124A-2 | 2 | NetC124A_2 | false | 1 | 719.0 | 166.521 | 725.0 | 169.02 | 722.0 | 167.77 | 1 | 721.0 | 170.76 | 725.0 | 172.01 | 723.0 | 171.385
analog_1.SchDoc | 1 | C124B | C124B |  | C124B-1 | 1 | NetC124A_1 | false | 1 | 719.0 | 178.282 | 725.0 | 182.03 | 722.0 | 180.156 | 1 | 717.0 | 182.521 | 720.0 | 185.02 | 718.5 | 183.77
analog_1.SchDoc | 1 | C124B | C124B |  | C124B-2 | 2 | NetC124A_2 | false | 1 | 719.0 | 178.282 | 725.0 | 182.03 | 722.0 | 180.156 | 1 | 721.0 | 182.521 | 725.0 | 185.02 | 723.0 | 183.77
analog_1.SchDoc | 1 | C125A | C125A |  | C125A-1 | 1 | NetC125A_1 | false | 1 | 427.0 | 136.282 | 433.001 | 140.03 | 430.0 | 138.156 | 1 | 424.0 | 138.044 | 425.001 | 143.04 | 424.5 | 140.542
analog_1.SchDoc | 1 | C125A | C125A |  | C125A-2 | 2 | NetC125A_2 | false | 1 | 427.0 | 136.282 | 433.001 | 140.03 | 430.0 | 138.156 | 1 | 424.0 | 134.283 | 425.001 | 138.03 | 424.5 | 136.156
analog_1.SchDoc | 1 | C125B | C125B |  | C125B-1 | 1 | NetC125A_1 | false | 1 | 439.0 | 136.282 | 445.001 | 140.03 | 442.0 | 138.156 | 1 | 436.0 | 138.044 | 437.001 | 143.04 | 436.5 | 140.542
analog_1.SchDoc | 1 | C125B | C125B |  | C125B-2 | 2 | NetC125A_2 | false | 1 | 439.0 | 136.282 | 445.001 | 140.03 | 442.0 | 138.156 | 1 | 436.0 | 134.283 | 437.001 | 138.03 | 436.5 | 136.156
analog_1.SchDoc | 1 | C126A | C126A |  | C126A-1 | 1 | NetC125A_2 | false | 1 | 444.0 | 71.521 | 450.0 | 74.02 | 447.0 | 72.77 | 1 | 441.0 | 75.76 | 444.0 | 77.01 | 442.5 | 76.385
analog_1.SchDoc | 1 | C126A | C126A |  | C126A-2 | 2 | NetC10A_1 | false | 1 | 444.0 | 71.521 | 450.0 | 74.02 | 447.0 | 72.77 | 1 | 446.0 | 75.76 | 449.0 | 77.01 | 447.5 | 76.385
analog_1.SchDoc | 1 | C126B | C126B |  | C126B-1 | 1 | NetC125A_2 | false | 1 | 444.0 | 83.282 | 450.001 | 87.03 | 447.0 | 85.156 | 1 | 441.0 | 87.76 | 444.0 | 89.01 | 442.5 | 88.385
analog_1.SchDoc | 1 | C126B | C126B |  | C126B-2 | 2 | NetC10A_1 | false | 1 | 444.0 | 83.282 | 450.001 | 87.03 | 447.0 | 85.156 | 1 | 446.0 | 87.76 | 449.0 | 89.01 | 447.5 | 88.385
analog_1.SchDoc | 1 | C127A | C127A |  | C127A-1 | 1 | NetC105A_1 | false | 1 | 480.0 | 368.521 | 487.0 | 371.02 | 483.5 | 369.77 | 1 | 477.0 | 370.283 | 479.001 | 374.03 | 478.0 | 372.156
analog_1.SchDoc | 1 | C127A | C127A |  | C127A-2 | 2 | NetC124A_2 | false | 1 | 480.0 | 368.521 | 487.0 | 371.02 | 483.5 | 369.77 | 1 | 477.0 | 365.044 | 479.001 | 370.04 | 478.0 | 367.542
analog_1.SchDoc | 1 | C127B | C127B |  | C127B-1 | 1 | NetC105A_1 | false | 1 | 490.0 | 368.521 | 496.0 | 371.02 | 493.0 | 369.77 | 1 | 487.0 | 370.283 | 489.001 | 374.03 | 488.0 | 372.156
analog_1.SchDoc | 1 | C127B | C127B |  | C127B-2 | 2 | NetC124A_2 | false | 1 | 490.0 | 368.521 | 496.0 | 371.02 | 493.0 | 369.77 | 1 | 487.0 | 365.044 | 489.001 | 370.04 | 488.0 | 367.542
analog_1.SchDoc | 1 | C128A | C128A |  | C128A-1 | 1 | NetC128A_1 | false | 1 | 412.0 | 81.521 | 418.0 | 84.02 | 415.0 | 82.77 | 1 | 409.0 | 84.521 | 413.0 | 87.02 | 411.0 | 85.77
analog_1.SchDoc | 1 | C128A | C128A |  | C128A-2 | 2 | NetC121A_1 | false | 1 | 412.0 | 81.521 | 418.0 | 84.02 | 415.0 | 82.77 | 1 | 414.0 | 84.521 | 418.0 | 87.02 | 416.0 | 85.77
analog_1.SchDoc | 1 | C128B | C128B |  | C128B-1 | 1 | NetC128A_1 | false | 1 | 412.0 | 93.521 | 418.0 | 96.02 | 415.0 | 94.77 | 1 | 409.0 | 97.76 | 413.0 | 99.01 | 411.0 | 98.385
analog_1.SchDoc | 1 | C128B | C128B |  | C128B-2 | 2 | NetC121A_1 | false | 1 | 412.0 | 93.521 | 418.0 | 96.02 | 415.0 | 94.77 | 1 | 414.0 | 97.76 | 418.0 | 99.01 | 416.0 | 98.385
analog_1.SchDoc | 1 | C166A | C166A |  | C166A-1 | 1 | NetC166A_1 | false | 1 | 134.0 | 427.521 | 140.0 | 430.02 | 137.0 | 428.77 | 1 | 131.0 | 431.76 | 135.0 | 433.01 | 133.0 | 432.385
analog_1.SchDoc | 1 | C166A | C166A |  | C166A-2 | 2 | NetC166A_2 | false | 1 | 134.0 | 427.521 | 140.0 | 430.02 | 137.0 | 428.77 | 1 | 136.0 | 431.76 | 140.0 | 433.01 | 138.0 | 432.385
analog_1.SchDoc | 1 | C166B | C166B |  | C166B-1 | 1 | NetC166A_1 | false | 1 | 134.0 | 439.282 | 140.001 | 443.03 | 137.0 | 441.156 | 1 | 131.0 | 443.76 | 135.0 | 445.01 | 133.0 | 444.385
analog_1.SchDoc | 1 | C166B | C166B |  | C166B-2 | 2 | NetC166A_2 | false | 1 | 134.0 | 439.282 | 140.001 | 443.03 | 137.0 | 441.156 | 1 | 136.0 | 443.76 | 140.0 | 445.01 | 138.0 | 444.385
analog_1.SchDoc | 1 | C167A | C167A |  | C167A-1 | 1 | NetC167A_1 | false | 1 | 63.0 | 490.521 | 70.0 | 493.02 | 66.5 | 491.77 | 1 | 60.0 | 492.283 | 62.001 | 496.03 | 61.001 | 494.156
analog_1.SchDoc | 1 | C167A | C167A |  | C167A-2 | 2 | NetC112A_1 | false | 1 | 63.0 | 490.521 | 70.0 | 493.02 | 66.5 | 491.77 | 1 | 60.0 | 487.283 | 62.001 | 491.03 | 61.001 | 489.156
analog_1.SchDoc | 1 | C167B | C167B |  | C167B-1 | 1 | NetC167A_1 | false | 1 | 76.0 | 490.521 | 82.0 | 493.02 | 79.0 | 491.77 | 1 | 73.0 | 492.283 | 74.001 | 496.03 | 73.501 | 494.156
analog_1.SchDoc | 1 | C167B | C167B |  | C167B-2 | 2 | NetC112A_1 | false | 1 | 76.0 | 490.521 | 82.0 | 493.02 | 79.0 | 491.77 | 1 | 73.0 | 487.283 | 74.001 | 491.03 | 73.501 | 489.156
analog_1.SchDoc | 1 | C201A | C201A |  | C201A-1 | 1 | NetC201A_1 | false | 1 | 254.0 | 105.521 | 260.0 | 108.02 | 257.0 | 106.77 | 1 | 251.0 | 109.76 | 254.0 | 111.01 | 252.5 | 110.385
analog_1.SchDoc | 1 | C201A | C201A |  | C201A-2 | 2 | NetC201A_2 | false | 1 | 254.0 | 105.521 | 260.0 | 108.02 | 257.0 | 106.77 | 1 | 256.0 | 109.76 | 259.0 | 111.01 | 257.5 | 110.385
analog_1.SchDoc | 1 | C201B | C201B |  | C201B-1 | 1 | NetC201A_1 | false | 1 | 254.0 | 117.282 | 260.001 | 121.03 | 257.0 | 119.156 | 1 | 251.0 | 121.521 | 254.0 | 124.02 | 252.5 | 122.77
analog_1.SchDoc | 1 | C201B | C201B |  | C201B-2 | 2 | NetC201A_2 | false | 1 | 254.0 | 117.282 | 260.001 | 121.03 | 257.0 | 119.156 | 1 | 256.0 | 121.521 | 259.0 | 124.02 | 257.5 | 122.77
analog_1.SchDoc | 1 | C202A | C202A |  | C202A-1 | 1 | NetC201A_1 | false | 1 | 254.0 | 134.282 | 260.001 | 138.03 | 257.0 | 136.156 | 1 | 251.0 | 138.521 | 254.0 | 141.02 | 252.5 | 139.77
analog_1.SchDoc | 1 | C202A | C202A |  | C202A-2 | 2 | NetC202A_2 | false | 1 | 254.0 | 134.282 | 260.001 | 138.03 | 257.0 | 136.156 | 1 | 256.0 | 138.521 | 259.0 | 141.02 | 257.5 | 139.77
analog_1.SchDoc | 1 | C202B | C202B |  | C202B-1 | 1 | NetC201A_1 | false | 1 | 254.0 | 146.282 | 260.001 | 150.03 | 257.0 | 148.156 | 1 | 251.0 | 150.521 | 254.0 | 153.02 | 252.5 | 151.77
analog_1.SchDoc | 1 | C202B | C202B |  | C202B-2 | 2 | NetC202A_2 | false | 1 | 254.0 | 146.282 | 260.001 | 150.03 | 257.0 | 148.156 | 1 | 256.0 | 150.521 | 259.0 | 153.02 | 257.5 | 151.77
analog_1.SchDoc | 1 | C203A | C203A |  | C203A-1 | 1 | NetC201A_1 | false | 1 | 254.0 | 164.521 | 260.0 | 167.02 | 257.0 | 165.77 | 1 | 251.0 | 167.521 | 254.0 | 170.02 | 252.5 | 168.77
analog_1.SchDoc | 1 | C203A | C203A |  | C203A-2 | 2 | NetC203A_2 | false | 1 | 254.0 | 164.521 | 260.0 | 167.02 | 257.0 | 165.77 | 1 | 256.0 | 167.521 | 259.0 | 170.02 | 257.5 | 168.77
analog_1.SchDoc | 1 | C203B | C203B |  | C203B-1 | 1 | NetC201A_1 | false | 1 | 254.0 | 176.521 | 260.0 | 179.02 | 257.0 | 177.77 | 1 | 251.0 | 180.76 | 254.0 | 182.01 | 252.5 | 181.385
analog_1.SchDoc | 1 | C203B | C203B |  | C203B-2 | 2 | NetC203A_2 | false | 1 | 254.0 | 176.521 | 260.0 | 179.02 | 257.0 | 177.77 | 1 | 256.0 | 180.76 | 259.0 | 182.01 | 257.5 | 181.385
analog_1.SchDoc | 1 | C204A | C204A |  | C204A-1 | 1 | NetC201A_1 | false | 1 | 254.0 | 193.521 | 260.0 | 196.02 | 257.0 | 194.77 | 1 | 251.0 | 197.76 | 254.0 | 199.01 | 252.5 | 198.385
analog_1.SchDoc | 1 | C204A | C204A |  | C204A-2 | 2 | NetC204A_2 | false | 1 | 254.0 | 193.521 | 260.0 | 196.02 | 257.0 | 194.77 | 1 | 256.0 | 197.76 | 259.0 | 199.01 | 257.5 | 198.385
analog_1.SchDoc | 1 | C204B | C204B |  | C204B-1 | 1 | NetC201A_1 | false | 1 | 254.0 | 205.521 | 260.0 | 208.02 | 257.0 | 206.77 | 1 | 251.0 | 209.76 | 254.0 | 211.01 | 252.5 | 210.385
analog_1.SchDoc | 1 | C204B | C204B |  | C204B-2 | 2 | NetC204A_2 | false | 1 | 254.0 | 205.521 | 260.0 | 208.02 | 257.0 | 206.77 | 1 | 256.0 | 209.76 | 259.0 | 211.01 | 257.5 | 210.385
analog_1.SchDoc | 1 | C205A | C205A |  | C205A-1 | 1 | NetC205A_1 | false | 1 | 363.0 | 122.521 | 370.0 | 125.02 | 366.5 | 123.77 | 1 | 361.0 | 126.76 | 364.0 | 128.01 | 362.5 | 127.385
analog_1.SchDoc | 1 | C205A | C205A |  | C205A-2 | 2 | NetC128A_1 | false | 1 | 363.0 | 122.521 | 370.0 | 125.02 | 366.5 | 123.77 | 1 | 365.0 | 126.76 | 369.0 | 128.01 | 367.0 | 127.385
analog_1.SchDoc | 1 | C205B | C205B |  | C205B-1 | 1 | NetC205A_1 | false | 1 | 363.0 | 134.282 | 369.001 | 138.03 | 366.0 | 136.156 | 1 | 361.0 | 138.521 | 364.0 | 141.02 | 362.5 | 139.77
analog_1.SchDoc | 1 | C205B | C205B |  | C205B-2 | 2 | NetC128A_1 | false | 1 | 363.0 | 134.282 | 369.001 | 138.03 | 366.0 | 136.156 | 1 | 365.0 | 138.521 | 369.0 | 141.02 | 367.0 | 139.77
analog_1.SchDoc | 1 | C301 | C301 |  | C301-1 | 1 | GND | false | 1 | 51.0 | 185.521 | 56.0 | 188.02 | 53.5 | 186.77 | 1 | 48.0 | 187.283 | 50.001 | 191.03 | 49.001 | 189.156
analog_1.SchDoc | 1 | C301 | C301 |  | C301-2 | 2 | NetC301_2 | false | 1 | 51.0 | 185.521 | 56.0 | 188.02 | 53.5 | 186.77 | 1 | 48.0 | 182.044 | 50.001 | 187.04 | 49.001 | 184.542
analog_1.SchDoc | 1 | C314 | C314 |  | C314-1 | 1 | GND | false | 1 | 356.0 | 290.521 | 361.0 | 293.02 | 358.5 | 291.77 | 1 | 353.0 | 292.283 | 354.001 | 296.03 | 353.5 | 294.156
analog_1.SchDoc | 1 | C314 | C314 |  | C314-2 | 2 | VCC | false | 1 | 356.0 | 290.521 | 361.0 | 293.02 | 358.5 | 291.77 | 1 | 353.0 | 287.044 | 354.001 | 292.04 | 353.5 | 289.542
analog_1.SchDoc | 1 | C315 | C315 |  | C315-1 | 1 | GND | false | 1 | 366.0 | 290.521 | 370.0 | 293.02 | 368.0 | 291.77 | 1 | 363.0 | 292.283 | 364.001 | 296.03 | 363.5 | 294.156
analog_1.SchDoc | 1 | C315 | C315 |  | C315-2 | 2 | VCC | false | 1 | 366.0 | 290.521 | 370.0 | 293.02 | 368.0 | 291.77 | 1 | 363.0 | 287.044 | 364.001 | 292.04 | 363.5 | 289.542
analog_1.SchDoc | 1 | C316 | C316 |  | C316-1 | 1 | GND | false | 1 | 375.0 | 290.521 | 380.0 | 293.02 | 377.5 | 291.77 | 1 | 372.0 | 292.283 | 374.001 | 296.03 | 373.0 | 294.156
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

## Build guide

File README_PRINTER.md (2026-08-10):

# Virtual Printer (Super Serial Card + ImageWriter II)

Appletini emulates an Apple Super Serial Card in slot 1 with an
ImageWriter II behind it. Anything the Apple prints becomes a PNG file
on the SD card.

## How to print

1. Open the config menu, go to the **Printing** tab, and enable the
   Super Serial Card. It is on by default.
2. On the Apple, print to slot 1: `PR#1` in BASIC, or select an Apple
   Super Serial Card in slot 1 (printer: ImageWriter or ImageWriter II)
   in your software.
3. Each printed page lands in `0:/printouts` as `print_NNNN.png`
   (US Letter, 144 dpi color). A print job closes five seconds after
   the Apple stops sending data; a partial last page is saved at that
   point. A form feed always completes a page immediately.
4. The **Browse Printouts...** entry opens a file browser with a
   preview. ENTER renames the selected printout, SPACE deletes it after
   a confirmation.

## Slot sharing

The SSC and the Uthernet II both live in slot 1 with disjoint hardware
decodes, so Ethernet and printing work at the same time:

| Slot-1 resource | Owner |
|---|---|
| $C0n1/$C0n2 (DIP readback), $C0n8-$C0nF (6551 ACIA) | SSC |
| $C0n4-$C0n7 (W5100 window) | Uthernet II |
| $C100-$C1FF slot ROM, $C800-$CFFF expansion ROM | SSC |

The two enables are independent: the Uthernet II uses slot-mask bit 1,
the SSC uses feature bit 2 (`printing.ssc.enabled` in the config file).

## What the Apple sees

The firmware is the real 1981 Apple SSC ROM (a2retronet source split,
built by `scripts/build_ssc_rom.py` with SLOT=1, SSC=1). DIP switches
are hardwired to the classic printer setup: 9600 baud, printer (PPC)
mode, no delays, no width formatting, LF after CR for the BASIC entry.
Ctrl-I commands work as on a real SSC. The virtual 6551 always reports
transmit-ready, and every transmit byte enters a 2 KB FIFO the ARM
drains through the card-control registers ($4A-$4D).

## Printer language coverage

The interpreter (`ps_sources/frontend/imagewriter.c`) renders draft
text in all eight fixed pitches, bold, underline, half-height,
super/subscript, and double width, plus ESC G/S/g/V dot graphics at the
per-pitch densities, ESC T/A/B line spacing, ESC F/L positioning, and
ESC H form length. `ESC K 0` through `ESC K 6` select black, yellow,
magenta, cyan, orange, green, and purple on the emulated four-color
ribbon. Separate strikes over the same dot mix their ink. LQ-only
commands, MouseText, and user-defined characters are consumed and
ignored.

## Tests

`python scripts/test_ssc_card.py` runs the source regressions, rebuilds
and compares the ROM, executes the real firmware under py65 against a
mocked ACIA, compiles and runs the interpreter unit test on the host,
and runs `hdl/sim/tb_ssc_card.sv` under xsim.

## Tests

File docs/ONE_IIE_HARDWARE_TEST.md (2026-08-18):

# ONE//e Hardware Test Record and F0.9.86 Retest Plan

## F0.9.77 Test Result

The first hardware test used the F0.9.77 image built from source commit
`36a5bd21710caa75b48073cf6f46cdb0b4d3b002`:

- Archived file:
  `.timing_runs/20260816T152953Z-36a5bd21-full/FIRMWARE_TEST.BIN`
- Size: `4,236,236` bytes
- SHA-256:
  `1b5a932f836471075fdb9a7a92664be44af2f0537787ece638ad9314a18d9b0f`
- Timing build: `20260816T152953Z-36a5bd21-full`
- Route: WNS `+0.069 ns`, TNS `0`, WHS `+0.046 ns`, no failed or
  unrouted paths

The user powered the card while it was out of the Apple slot by applying the
needed +5 V to the slot bus power pin. The boot menu showed ONE//e as
`LOCKED`. This was a false lock, not proof that an Apple was present.

F0.9.77 assumed that an unplugged U533 presented one fixed Apple idle vector.
The open connector presented another stable vector, so the level comparison
kept the lock set. Physical isolation also disabled the main translator. That
removed the same PHI0, 7M, and Q3 observations which the guard needed to detect
an Apple after ONE//e selection.

The F0.9.77 image is now a historical test artifact. Do not use it to retest
the corrected start or clock-detection behavior.

## F0.9.78 Correction

F0.9.78 source commit
`7838f23580d95a03e2e9f2442d80f2e3ce9c6ebf` changes the guard as follows:

- Learn any stable U533 input vector instead of requiring fixed idle levels.
- Require 96 quiet fabric clocks before arming. At 133.333 MHz, that interval
  is about 0.72 microseconds.
- Watch transitions on PHI0, 7M, Q3, M2SEL, M2B0, and DEVSEL# through U533.
- Block start or kill a running ONE//e when any watched input changes.
- Keep the main translators enabled but forced to Apple-to-FPGA input
  direction during ONE//e, so the clock monitor stays live.
- Disable bidirectional auxiliary translator U234 during ONE//e. Its isolated
  RESET#, INH#, IRQ#, NMI#, RDY#, and DMA# outputs do not enter the guard.
- Keep the activity lock sticky and require a later manual off/on selection.

## F0.9.78 Test Image

- Source commit: `7838f23580d95a03e2e9f2442d80f2e3ce9c6ebf`
- Timing build: `20260816T164305Z-7838f235-full`
- Build status: `exported`
- Route: WNS `+0.019 ns`, TNS `0`, WHS `+0.063 ns`, THS `0`, and WPWS
  `+0.265 ns`
- Failures: zero setup, hold, or pulse-width failing endpoints; zero route
  errors, missing constraint objects, or unconstrained internal endpoints
- XSA SHA-256:
  `314435c8f18adfade2c2d766871d59c30b8d6078f548e33f9686a5c9dc758ed5`
- Bitstream SHA-256:
  `46a4f3ffa6d03bd6d9887506689e7b1c8ef605e6f7c252ad24a7e41f8094bbf6`
- Files: root `FIRMWARE.BIN` and
  `.timing_runs/20260816T164305Z-7838f235-full/FIRMWARE_TEST.BIN`
- Handoff record:
  `.timing_runs/20260816T164305Z-7838f235-full/test_firmware_manifest.txt`
- Size: `4,235,276` bytes each
- Firmware SHA-256:
  `47f7385846b8092e46784649a0f99f7b90e7d2415d2ee02eb627c2628a71d9fa`

The two firmware files are byte-identical. A fresh Vitis workspace used the
exact archived XSA; platform export and all application builds succeeded.
Bootgen readback reports `total_images=4`. All stated focused ONE//e HDL and
frontend regressions passed, including the vTW, boot-sector, and virtual-card
checks.

The Vivado manifest records `git_dirty=1` because these two ONE//e documents
were being edited. No HDL or firmware source was dirty. This image is below
the project's release-only +0.300 ns setup-margin gate. The user waived that
gate for this test image only; this is not a promoted release. The corrected
image starts ONE//e out of the Apple slot, but the functional test found the
three faults below.

## F0.9.78 Functional Test Result

F0.9.78 reached the Enhanced //e screen. The test then found these faults:

- Selecting SmartPort did not boot SmartPort. If Disk II drive 1 had bootable
  media, the ROM booted it instead; without Disk II media, it stayed at
  `Apple //e`.
- While Disk II drive 1 ran, the storage overlay could say
  `SMARTPORT SP1`.
- A bound USB TransWarp speed key changed its notice but did not change the
  machine's speed. Changing speed on the TransWarp config page did work.

These were state-model faults, not three unrelated device faults. ONE//e had
session state beside the saved config and normal host-run state, but three
callers still read the wrong copy:

- The cold-slot helper always hid slot 7. It did not receive the configured
  SmartPort or Disk II target.
- ONE//e enabled virtual Disk II for the session without changing the saved
  Slot 6 bit. The overlay used that saved bit to decide whether Disk II
  activity existed, then retained a SmartPort `STATUS` poll as its source.
- The USB key path checked saved host TransWarp intent and wrote `VTW_CTRL`
  only for the host state machine. It still made a success label. The config
  page had its own ONE//e write path, which is why that path worked.

## F0.9.79 Runtime Corrections

The F0.9.79 source uses one clear rule at each boundary:

- The configured target controls the ONE//e cold scan. SmartPort exposes slot
  7 on the first `$C7xx` probe. Disk II hides slot 7 until the first `$C6xx`
  probe, then releases it. A virtual warm reset re-arms the same configured
  target. The normal host handoff keeps its own fallback rule, so a disabled
  physical Slot 6 does not rewrite ONE//e's virtual target. The menu now keeps
  that Disk II choice instead of changing it back to SmartPort.
- The overlay polls the effective Disk II service state, not the saved Slot 6
  bit. SmartPort data has first priority, then active Disk II motor/read/write
  work, then SmartPort `STATUS`, then the last valid source. A discovery poll
  can no longer replace an active `DISK II D1` label.
- Menu and USB speed changes use one live `VTW_CTRL` writer. It chooses the
  running host or ONE//e word, writes it, and verifies the register readback
  before it shows success. A failed USB change restores its old override and
  reports `TW: CONTROL WRITE FAILED`.
- All reset and config paths use one effective Disk II setter. During ONE//e,
  it keeps the session service enabled without changing saved host state. When
  ONE//e stops, it applies the latest saved state instead of a value captured
  at session start. A private ONE//e reset also skips the host-only IIgs
  `$C029` DMA write.
- A SmartPort-target ONE//e session overrides saved SuperSprite slot-7
  ownership. Without that session override, SuperSprite could still claim the
  shared slot and keep SmartPort's ROM invisible even after the cold-scan fix.

The source correction, focused regression, full Vivado and Vitis build, and
package are complete. The hardware retest result is recorded below.

## F0.9.79 Test Image

- Source and packaging commit:
  `a94aefc27353f8ccdefe7b9dbf012d343a9f1564`
- Clean full build: `20260816T180541Z-a94aefc2-full`
- Route: WNS `+0.103 ns`, TNS `0`, WHS `+0.019 ns`, THS `0`, and WPWS
  `+0.265 ns`
- Failures: no failing endpoints, route errors, missing constraint objects, or
  unconstrained internal endpoints
- Bitstream SHA-256:
  `a03e90819fee064d4163572925392d18e9a05e47c8426f32b6258d2dd03afea8`
- XSA SHA-256:
  `0963dc9999f253dac21dd69d3af5a20c7e88008e613479497a9762fc87dcedce`
- Files: root `FIRMWARE.BIN` and
  `.timing_runs/20260816T180541Z-a94aefc2-full/FIRMWARE_TEST.BIN`
- Size: `4,109,260` bytes each
- Firmware SHA-256:
  `3d4c6d9797eac2ebfae74d110963077a91897175f6c19cc21b56a9f69d567941`
- Handoff record:
  `.timing_runs/20260816T180541Z-a94aefc2-full/test_firmware_manifest.txt`

The two firmware files are byte-identical. A fresh Vitis workspace used the
exact archived XSA; platform export and all application builds report
`SUCCESS`. Bootgen readback passed with `total_images=3` and
`total_partitions=3`. The frontend contains the `196684`-byte CPU1 blob.

This image is below the project's release-only +0.300 ns setup-margin gate.
The user waived that gate for this test image; this is not a promoted release.

## F0.9.79 Functional Retest Result

The user ran F0.9.79 out of the Apple slot. ONE//e booted, but the test found
three more faults:

- A TransWarp speed selected with a bound key during the boot-menu/takeover
  window did not reach the core. ONE//e started at full acceleration. After a
  virtual warm reset, it again ran at full acceleration. A speed change made
  later on the config page did take effect.
- A brief key tap could repeat many times. In the Appletini demo menu, one
  Down tap could scroll to the last choice.
- The new DHGRi image mode appeared as HGRi. The other new image modes worked.

The speed fault extended the state-boundary error fixed in F0.9.79. With saved
host TransWarp off, a key used in the open menu before ONE//e selection, or
after the ONE//e request but before `g_onee_running` was set, still failed the
old live-core gate. The requested rung was discarded, so the first core-release
word kept full speed. The private warm reset did not choose a new speed; it
exposed the speed word which the session had retained.

Key repeat used 1,000 calls to `onee_input_service_poll()` for its first delay
and 100 calls for its steady rate. The USB service can call that function
twice in each fast frontend pass. Those call counts were not human-time delays
and could expire before a short tap's release report was handled.

The then-current virtual motherboard applied an IIc-only IOUDIS gate to the
Enhanced //e. `select_dhgr` set 80COL and accessed `$C05E`, but the false gate
kept that access from DHIRES, so the renderer saw HGRi. The F0.9.80 viewer
workaround wrote `$C07E` first and made that path pass. F0.9.82 fixes the
underlying model: `$C05E/$C05F` always update DHIRES and AN3 on an Enhanced
//e, while `$C07E/$C07F` float and remain paddle-trigger aliases.

## F0.9.80 Source Corrections

F0.9.80 is a historical test image. A timing-clean build of the speed, repeat,
and DHGRi fixes finished before the user added the latched-selection
requirement.
That baseline was intentionally not packaged. The final source checks, full
build, exact-XSA Vitis build, and test package are now complete at `cd8e9b8`.
The board retest ran and its result is recorded below.

- Speed commits: `147e56d23be402a4feed68e0719d41636a74e3e4` and
  `dde9b204e426d28ee4a11586f68af2e8b4c8271c`. A speed action is now
  allowed while host TransWarp has saved intent, while ONE//e is requested,
  effective, or running, or for a key event from an explicitly open Appletini
  menu. If no core is live, the action queues the rung and reports `TW NEXT`.
  This lets a menu-open key stage the upcoming ONE//e start even when saved
  host TransWarp is off. The input handler passes menu context for that event
  only; the same key with the menu closed still reports `TW: OFF` and queues
  nothing. Each of the three ONE//e start control words uses the effective
  speed and divider. The same word remains in `VTW_CTRL` across private warm
  reset. Stopping the session clears the temporary override, so a later
  session returns to its saved configured speed.
- Key-repeat commit:
  `3e978a10fa5cf975a69fa1d44cd4c983349901ee`. Repeat now uses the
  CherryUSB millisecond clock: 500 ms before the first repeat and 100 ms
  between later repeats. A late poll emits one event and starts a new interval
  from the current time, so it cannot fill the queue to catch up. The native
  test covers a short Down tap, exact deadlines, a long stall, release and
  disconnect reselection, session stop, and 32-bit time wrap.
- DHGRi compatibility commit:
  `9cbf3e0dfdf4cfeb33b09c88a4e739959ddae82c`. The assembled viewer now
  writes `$C07E` before it selects DHIRES, and the demo disk contains that
  rebuilt viewer. Its regression executes the assembled HGRi and DHGRi mode
  setters against the then-current switch model and requires `HGRi != DHGRi`.
  This did not fix the model's IIc-only gate; F0.9.82 does.
- Selection-latch commit:
  `36be6c5cf8f22796a986548482f994f48818e7e1`. A manual ONE//e selection
  has no software expiry. Stable quiet, including a long wait for effective
  state, does not clear it. A failed private-runtime start or a released core
  which stops suspends vTW and retries inside the same selected session while
  preserving the exact queued or live speed override. Watched Apple activity,
  a lost PL request echo, missing or invalid safety logic, and manual OFF are
  terminal stops: they stop vTW, clear session-only speed state, and require a
  fresh manual selection. Later quiet time never restarts a terminally stopped
  session.

Every full card and PS boot starts ONE//e in `OFF` and writes its request low.
ONE//e is not saved in config or profiles. A saved automatic start is not safe
without a nonvolatile hardware activity latch: a software restart cannot know
that a connected Apple was active before the card or PS restarted.

## F0.9.80 Pre-Latch Baseline Build

- Source commit: `e7fe40a4f3903331c2701c9cb2d5fc811b856882`
- Clean full build: `20260816T185749Z-e7fe40a4-full`
- Route: WNS `+0.103 ns`, TNS `0`, and WHS `+0.019 ns`
- Build result: timing-clean and exported
- Package result: intentionally not built

The user added the latched-selection requirement after this build began. Its
bitstream and XSA do not contain checkpoint `36be6c5`, so no F0.9.80 firmware
package was made from them. The final `36be6c5` plus documentation build
is recorded below.

## F0.9.80 Final Test Image

- Source commit used for the package:
  `cd8e9b8eb6eacd7f4dabdfdcd04e84af292feb99`
- Clean full build: `20260816T193636Z-cd8e9b8e-full`
- Build status: full, clean, and exported
- Route: WNS `+0.104 ns`, TNS `0`, WHS `+0.037 ns`, and WPWS `+0.265 ns`
- Failures: zero setup, hold, or pulse-width failing endpoints; zero route
  errors, missing constraint objects, or unconstrained internal endpoints
- Bus skew: `PASS`, WNS `+5.957 ns`
- Candidate DCP SHA-256:
  `0c57a120686aa2536b34def9453aaaba195eece6ab6dd9d75eccd8451a7db6af`
- Bitstream SHA-256:
  `d4c2fd7c78db7ba52763b5dc9c5612fdde8f6ae52ff035e0cabf1c6ed418dab3`
- XSA SHA-256:
  `5d899fb3d018c121fa19b1127f8ed39c6827e76af8cc10276e3de056e3c14435`
- Files: root `FIRMWARE.BIN` and
  `.timing_runs/20260816T193636Z-cd8e9b8e-full/FIRMWARE_TEST.BIN`
- Size: `4,257,036` bytes each
- Firmware SHA-256:
  `43a8eb8dca2816d065dbfbe0bde77ab6fac79b938a4d5321e51c819cdd771f3a`
- Handoff record:
  `.timing_runs/20260816T193636Z-cd8e9b8e-full/test_firmware_manifest.txt`

A fresh Vitis workspace used the exact archived XSA. Platform export and all
application builds report `SUCCESS`; the built strings are F0.9.80 and
B1.1.0. Root/archive `fc /b` passed. Bootgen readback passed with three images
and three partitions.

This package uses the user's test-only waiver for the +0.300 ns setup-margin
gate. WNS is positive, but the image is not a promoted release. Programming,
the out-of-slot functional retest, and the Apple-connected electrical tests
remain open.

## Detection Limit

Slot +5 V cannot identify an Apple in this stand-alone setup because that same
pin supplies the card when it is out of the computer. The design therefore
uses the Apple bus clocks, not slot +5 V, to detect a powered and running host.
PHI0, 7M, or Q3 will change within the sub-microsecond guard window during
normal Apple operation. The XDC gives all six watched U533 inputs—PHI0, 7M,
Q3, M2SEL, M2B0, and DEVSEL#—the same 5 ns pad-to-first-flop route bound.

There is no independent power sensor on this board. The clock guard cannot
prove that a host with all watched clocks stopped is off. A powered,
clock-stopped host and an unplugged connector may both present a stable U533
vector. The connected-Apple test must still prove translator direction,
output enable, leakage, back-power, and high impedance with test gear.

## F0.9.78 Package Checks

- [x] Revised guard and bus-isolation simulations passed.
- [x] All stated focused ONE//e HDL and frontend regressions passed.
- [x] The full Vivado run routed and exported its immutable bitstream and XSA.
- [x] Vitis platform export and application builds used that exact XSA and
  completed successfully.
- [x] F0.9.78 packaging, byte comparison, SHA-256 checks, and Bootgen readback
  passed.
- [x] Program F0.9.78 and start ONE//e out of the Apple slot. It reached the
  Enhanced //e screen and exposed the functional faults above.

## F0.9.79 Result

- [x] Pass the final cold-target, joined-bus, real-ROM, effective Disk II,
  SuperSprite override, storage-selection, and live-speed-control tests.
- [x] Complete a full Vivado route and export with no failing path.
- [x] Build Vitis from the exact exported XSA.
- [x] Package F0.9.79, record its source commit, size, SHA-256, timing result,
  and Bootgen readback, and compare the root and archived files byte for byte.
- [x] Program and run F0.9.79 out of the Apple slot. It exposed the speed,
  repeat, and DHGRi faults above. The Apple-connected electrical checks remain
  pending.

At that checkpoint, root `FIRMWARE.BIN` held the checked F0.9.80 test file.
Root now holds the F0.9.82 test file recorded below. Keep the golden boot image
unchanged.

## F0.9.80 Readiness

- [x] Correct and test menu-open and requested pre-takeover speed staging,
  first-release speed, warm-reset retention, and closed-menu true-off behavior
  at commits `147e56d23be402a4feed68e0719d41636a74e3e4` and
  `dde9b204e426d28ee4a11586f68af2e8b4c8271c`.
- [x] Correct and test elapsed key-repeat timing at commit
  `3e978a10fa5cf975a69fa1d44cd4c983349901ee`.
- [x] Add and test the demo viewer's `$C07E` DHGRi compatibility access at
  commit
  `9cbf3e0dfdf4cfeb33b09c88a4e739959ddae82c`.
- [x] Remove the selected-state software expiry and test long stable quiet at
  commit `36be6c5cf8f22796a986548482f994f48818e7e1`.
- [x] Test recoverable private-runtime suspend/retry with the exact queued or
  live speed override retained.
- [x] Test terminal stop and fresh manual reselect for watched Apple activity,
  lost request echo, missing safety logic, and manual OFF. Test that long later
  quiet never restarts the mode.
- [x] Bind PHI0, 7M, Q3, M2SEL, M2B0, and DEVSEL# to the 5 ns raw-input route
  constraint.
- [x] Confirm that every full card and PS boot writes request low and starts
  `OFF`, with no config or profile auto-start.
- [x] Complete timing-clean pre-latch build
  `20260816T185749Z-e7fe40a4-full` at `e7fe40a4`; do not package it because it
  predates the latch requirement.
- [x] Complete a clean full Vivado route and export for final F0.9.80 source
  checkpoint `cd8e9b8eb6eacd7f4dabdfdcd04e84af292feb99`.
- [x] Build Vitis against that exact XSA; platform export and all applications
  report `SUCCESS`, with F0.9.80 and B1.1.0 strings.
- [x] Package F0.9.80, record its source commit, build, timing, size, hashes,
  and Bootgen readback, then compare root and archived files byte for byte.
- [x] Program F0.9.80 and complete the out-of-slot retest below.

## Program the F0.9.80 Test Slot

The checked F0.9.80 test file is root `FIRMWARE.BIN`: 4,257,036 bytes, SHA-256
`43a8eb8dca2816d065dbfbe0bde77ab6fac79b938a4d5321e51c819cdd771f3a`.
This is the historical programming procedure which completed that test:

1. Connect the card's update UART and its stand-alone power source.
2. Find the port if needed:

   ```powershell
   python scripts\serial_firmware_update.py --list-ports
   ```

3. Check that root `FIRMWARE.BIN` matches the recorded F0.9.80 size and
   SHA-256, then upload it, replacing `COM3` with the update UART port:

   ```powershell
   python scripts\serial_firmware_update.py .\FIRMWARE.BIN --port COM3 --reboot-golden
   ```

The updater writes the firmware slot and checks the full programmed image.

## F0.9.80 Out-of-Slot Retest

The user completed this historical retest. Its result appears below.

Connect DVI, audio, a USB keyboard, and the SD card. A USB gamepad is optional.
Keep the Apple slot edge disconnected and apply the same stand-alone supply
used for the F0.9.77 test.

1. Power the card and confirm the on-screen firmware version is `F0.9.80`.
   Before any menu action, confirm that ONE//e says `OFF`. Perform a full card
   power cycle and a PS reboot; after each, confirm it returns to `OFF`. No
   saved setting or profile may select it.
2. Attach bootable images to both SmartPort SP1 and Disk II drive 1. Keep both
   available so the result proves the target choice rather than media fallback.
3. Enable SuperSprite in saved config, select SmartPort as the boot target,
   then select `ONE//e standalone` in `Boot Settings`.
4. Confirm that the item changes from `OFF` to `RUNNING`, not `LOCKED`, and
   that the ROM takes the first slot-7 SmartPort path and boots SP1. It must not
   fall through to Disk II.
5. Confirm that SmartPort data work says `SMARTPORT SP1`. Request a virtual
   warm reset and confirm that it keeps SmartPort as the target and boots it
   again. The reset must not touch a physical host or run the IIgs `$C029` DMA
   write.
6. Stop ONE//e. Select Disk II as the boot target and start ONE//e again.
   Confirm that the ROM hides slot 7 for the cold scan, reaches `$C600`, and
   boots drive 1. The activity label must say `DISK II D1`, even if SmartPort
   sends `STATUS` calls.
7. While ONE//e runs, change the saved Slot 6 setting and apply config. Confirm
   that the session Disk II service stays enabled. Stop ONE//e and confirm that
   the latest saved Slot 6 state, not the state from session start, takes
   effect.
8. Set a divided configured speed, start ONE//e without a speed key, and time
   a fixed loop. The first running core must use that configured speed, not
   full acceleration.
9. Stop ONE//e and leave saved host TransWarp off. Close the Appletini menu and
   press a bound speed key; it must report `TW: OFF` and queue nothing. Open the
   menu, press the same key before selecting ONE//e, and require `TW NEXT`.
   Select ONE//e and confirm that its first running core uses that queued speed.
   Repeat with the toggle, speed-up, speed-down, and armed slug actions. Also
   use a key after the ONE//e request but before core takeover finishes and
   confirm that it stages the first running speed.
10. While ONE//e runs at a non-full speed, request a virtual warm reset.
    Confirm that only the virtual //e resets and that the timed rate stays the
    same after reboot. Stop and start a new ONE//e session; it must return to
    the saved configured speed rather than retain the prior session override.
11. In the Appletini demo menu, tap Down once. The choice must move down one
    row only. Hold Down: the first repeat should start near 500 ms and later
    repeats should occur near 100 ms apart. Release it and confirm that repeat
    stops at once.
12. In the demo image viewer, show both HGRi and DHGRi samples. They must select
    distinct modes, and DHGRi must show double-hi-res pixels rather than HGRi.
    Recheck the other new image modes for regression.
13. Leave a selected ONE//e running for a long stable quiet interval and
    confirm that it stays selected and running. A safe request which is still
    settling must not time out. Turn ONE//e off, wait for the stable connector
    vector to pass the 96-cycle quiet check, and select it again.

A request never restarts itself after watched Apple activity, a lost request,
missing safety logic, or manual OFF. Long later quiet must leave it off until a
fresh manual menu selection.
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

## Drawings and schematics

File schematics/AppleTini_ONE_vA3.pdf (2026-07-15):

5

6

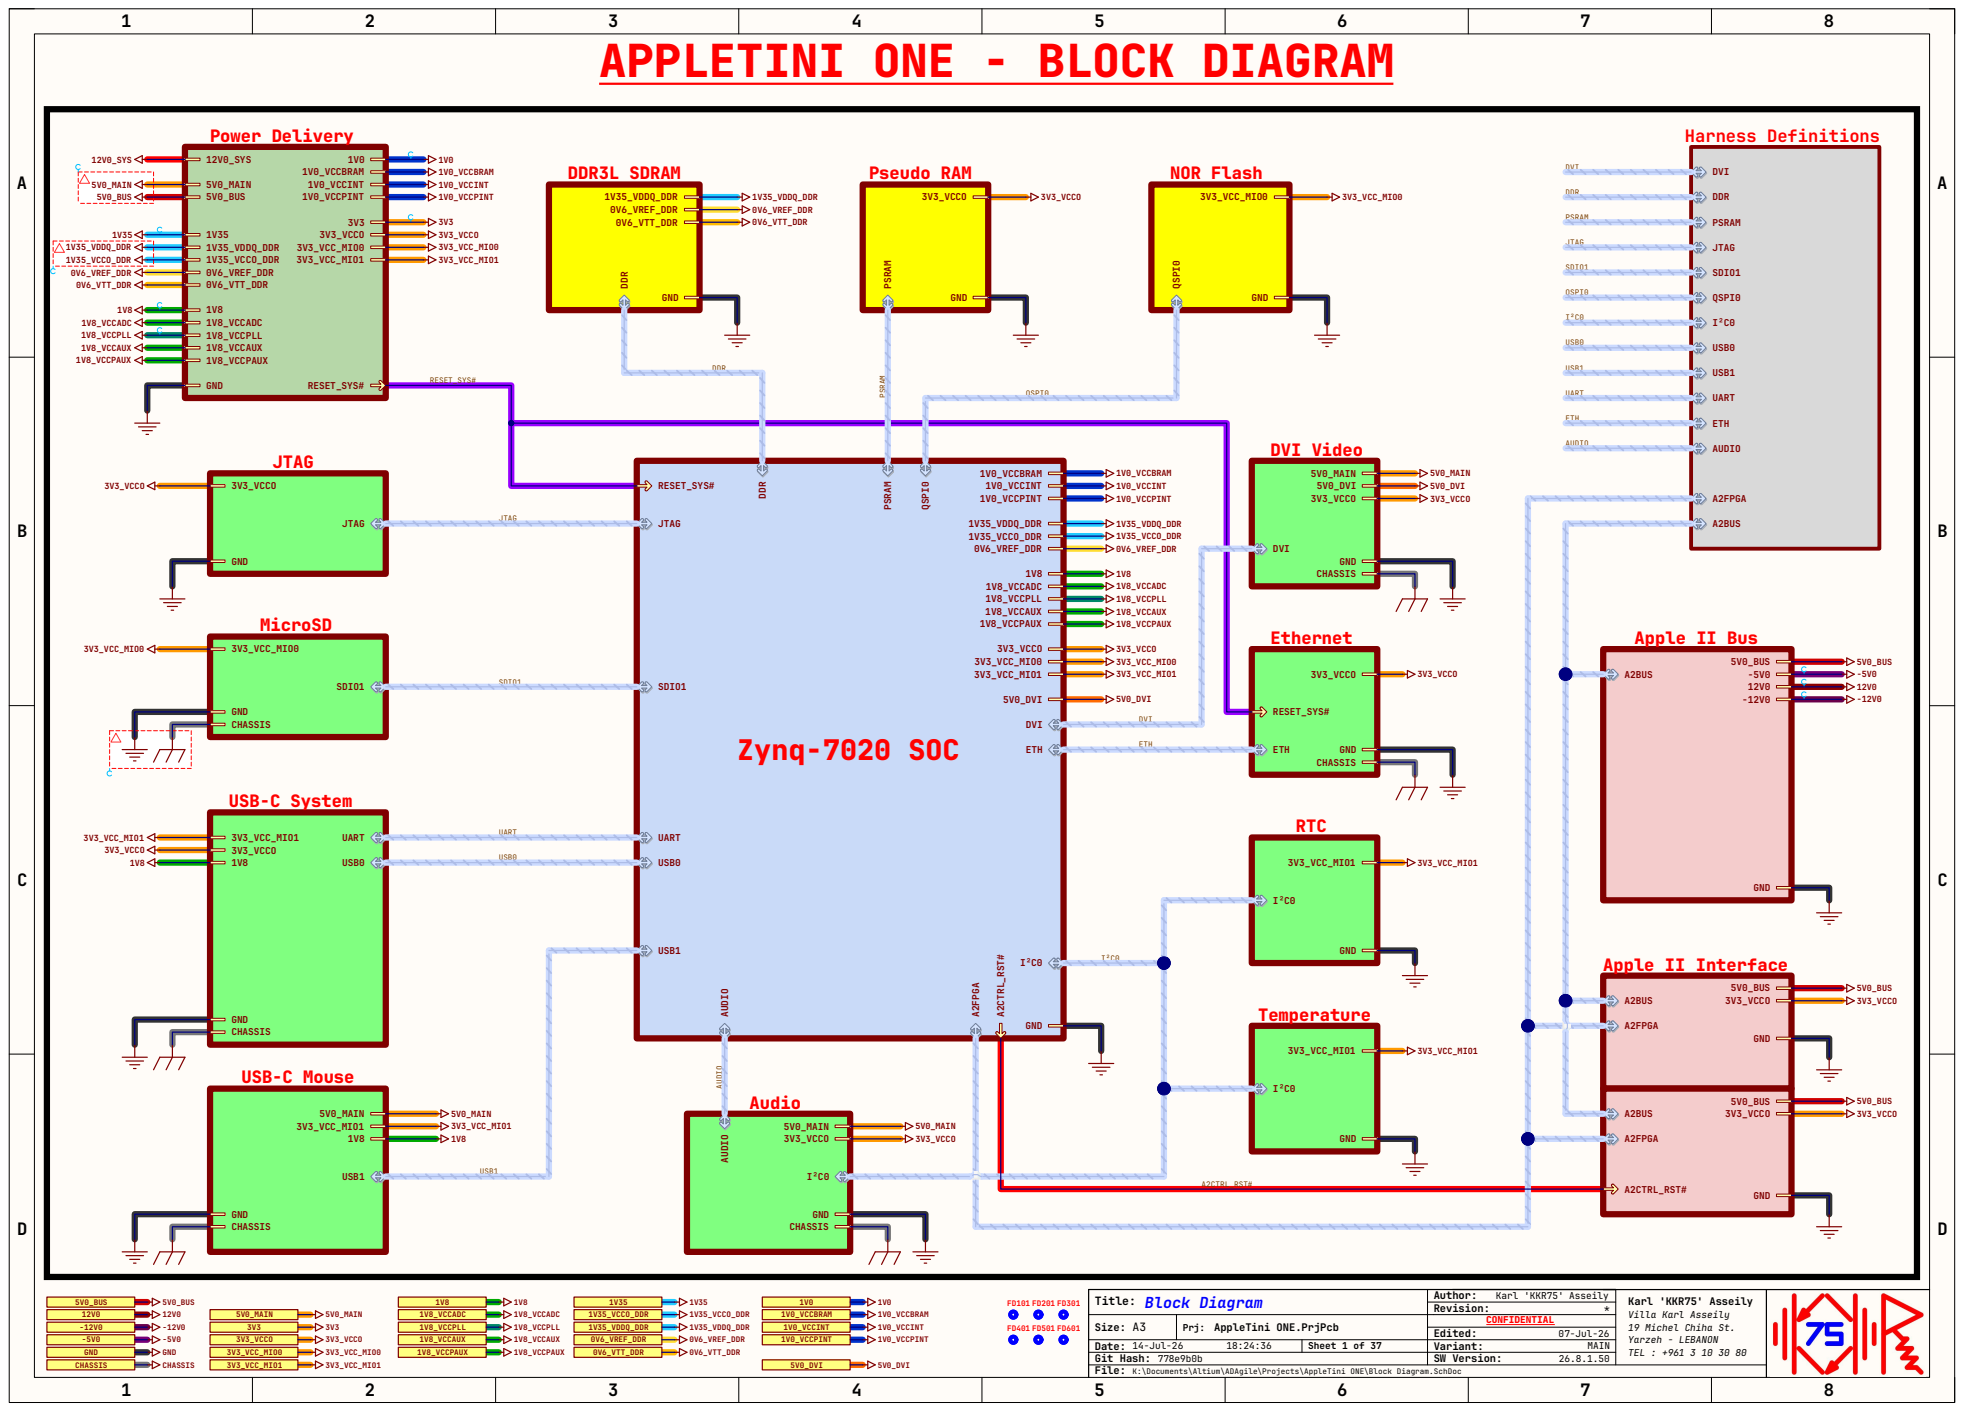
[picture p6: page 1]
Title:; Size:; Author: Revision:; Edited:; 07-Jul-26; Karl 'KKR75' Asseily; CONFIDENTIAL; Block Diagram; RESET_SYS#; GND QSPI0; 1V0_VCCBRAM 1V0_VCCINT 1V0_VCCPINT; 3V3_VCCO 3V3_VCC_MIO0 3V3_VCC_MIO1; 0V6_VREF_DDR; 1V35_VDDQ_DDR 1V35_VCCO_DDR; 1V8_VCCADC 1V8_VCCPLL 1V8_VCCAUX 1V8_VCCPAUX; JTAG; SDIO1; PSRAM; A2FPGA DDR; I²C0; USB0; DVI; 5V0_DVI; UART; USB1; ETH AUDIO; A2CTRL_RST#; Zynq-7020 SOC; 5V0_MAIN; GND; 5V0_BUS; 0V6_VREF_DDR 0V6_VTT_DDR; 12V0_SYS; Power Delivery; DDR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

APPLETINI ONE - BLOCK DIAGRAM

NOR Flash PSRAM

Apple II Bus

Apple II Interface

Villa Karl Asseily
19 Michel Chiha St.
Yarzeh - LEBANON
TEL : +961 3 10 30 80

Prj: AppleTini ONE.PrjPcb

Date: 14-Jul-26 18:24:36 | Sheet 1 of 37 | Variant: MAIN
Git Hash: 778e9b0b | | SW Version: 26.8.1.50

File: K:\Documents\Altium\ADAgile\Projects\AppleTini ONE\Block Diagram.SchDoc

A A

# APPLETINI ONE - POWER DELIVERY

Villa Karl Asseily
19 Michel Chiha St.
Yarzeh - LEBANON
TEL : +961 3 10 30 80

Prj: AppleTini ONE.PrjPcb

Date: 14-Jul-26 18:24:36 | Sheet 2 of 37 | Variant: MAIN
Git Hash: fd745e65

File: K:\Documents\Altium\ADAgile\Projects\AppleTini ONE\Power Delivery.SchDoc

A A

# APPLETINI ONE - POWER ENTRY

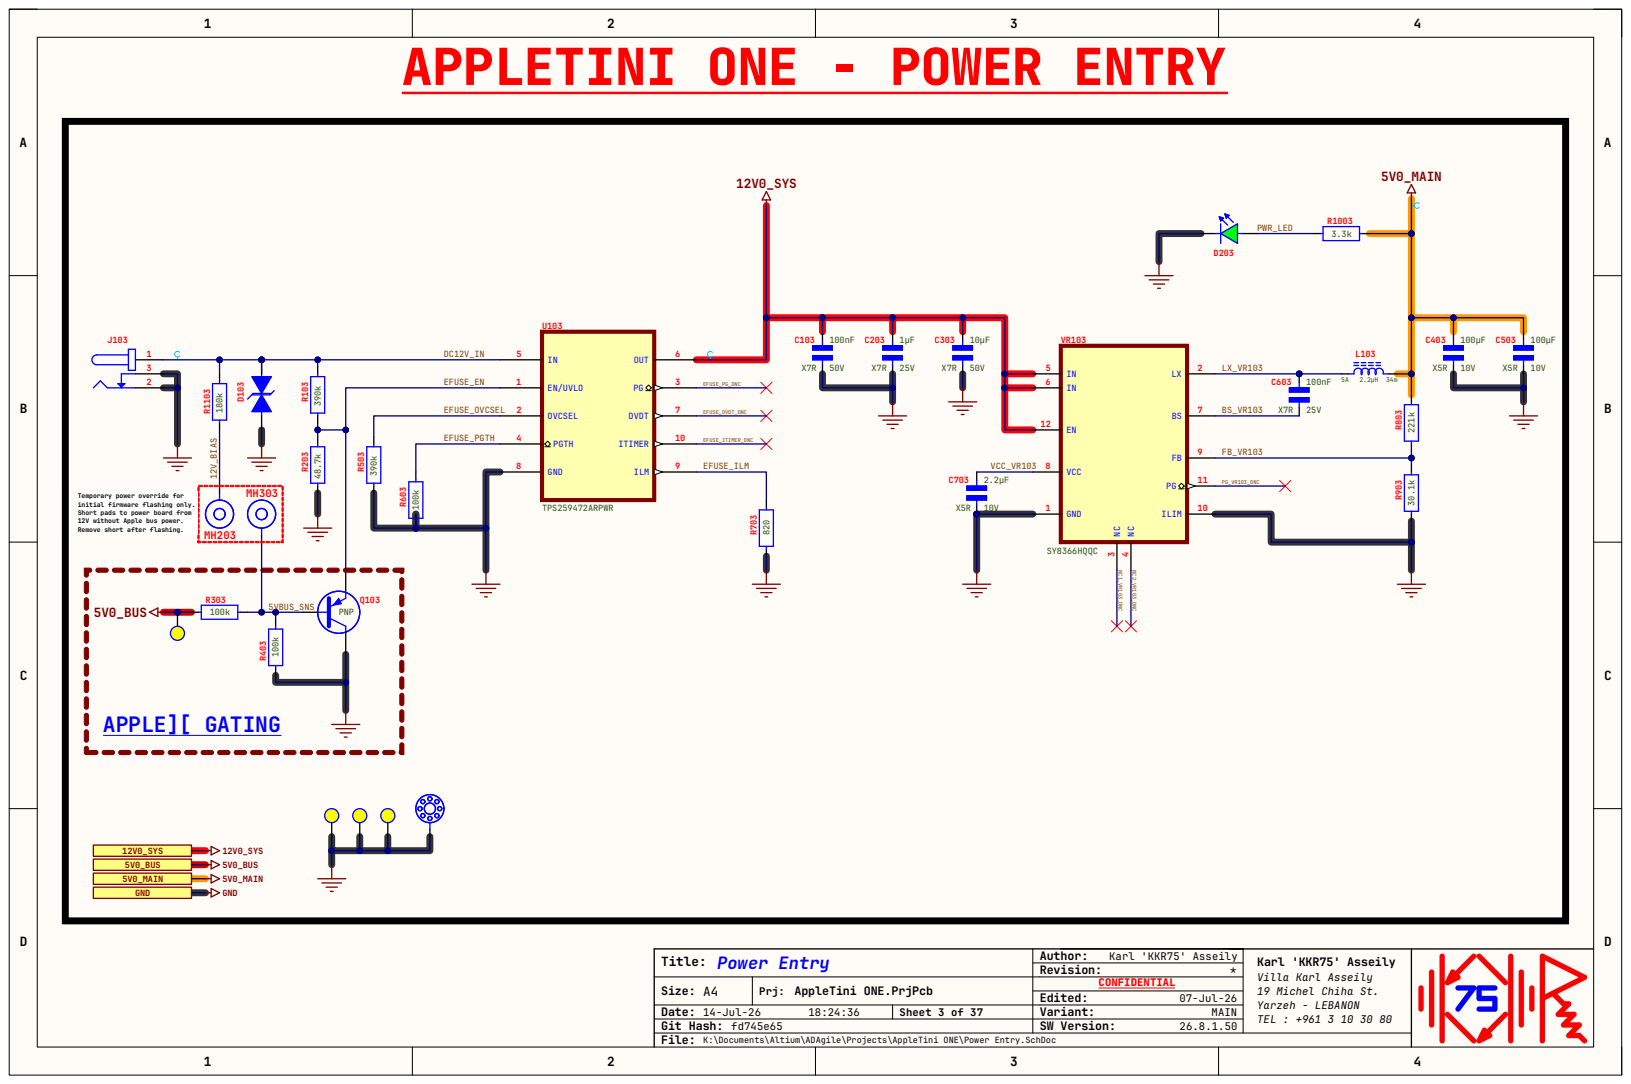
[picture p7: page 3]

Temporary power override for
initial firmware flashing only.
Short pads to power board from
12V without Apple bus power.
Remove short after flashing.

Prj: AppleTini ONE.PrjPcb

File: K:\Documents\Altium\ADAgile\Projects\AppleTini ONE\Power Entry.SchDoc

A A

# APPLETINI ONE - 1V0 BUCK CONVERTER

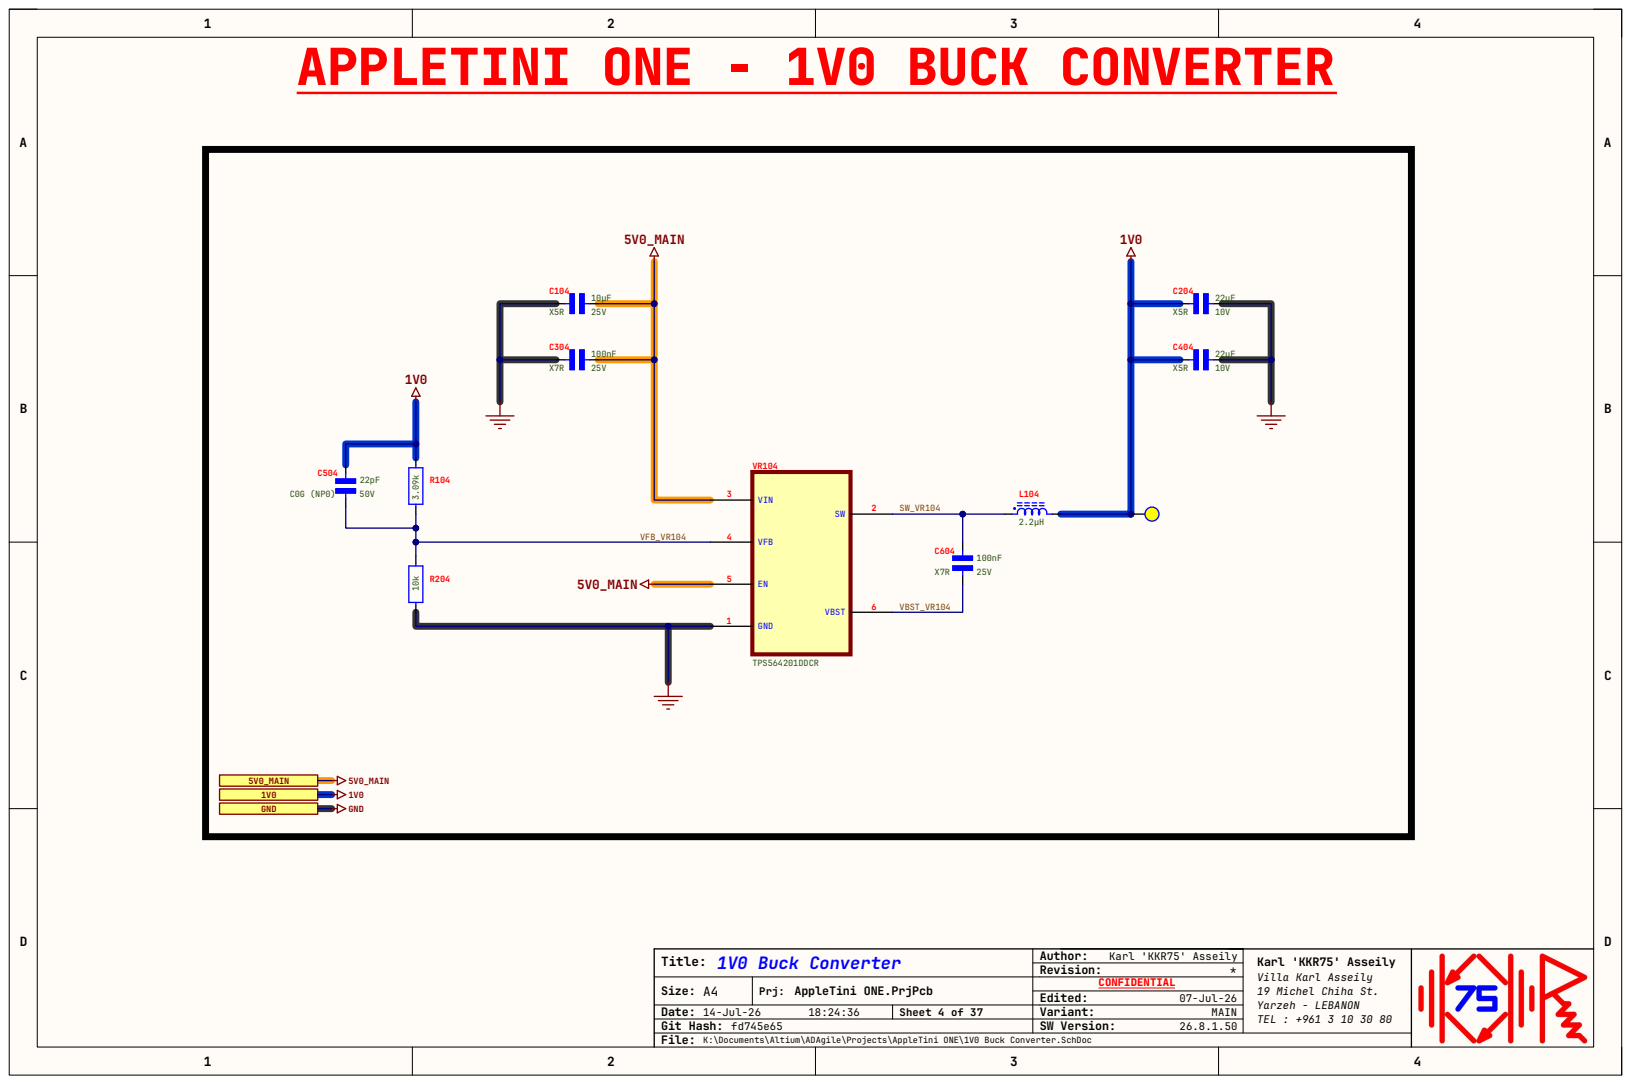
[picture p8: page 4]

Prj: AppleTini ONE.PrjPcb

File: K:\Documents\Altium\ADAgile\Projects\AppleTini ONE\1V0 Buck Converter.SchDoc

A A

# APPLETINI ONE - 1V35 BUCK CONVERTER

Prj: AppleTini ONE.PrjPcb

File: K:\Documents\Altium\ADAgile\Projects\AppleTini ONE\1V35 Buck Converter.SchDoc

A A

# APPLETINI ONE - 1V8 BUCK CONVERTER

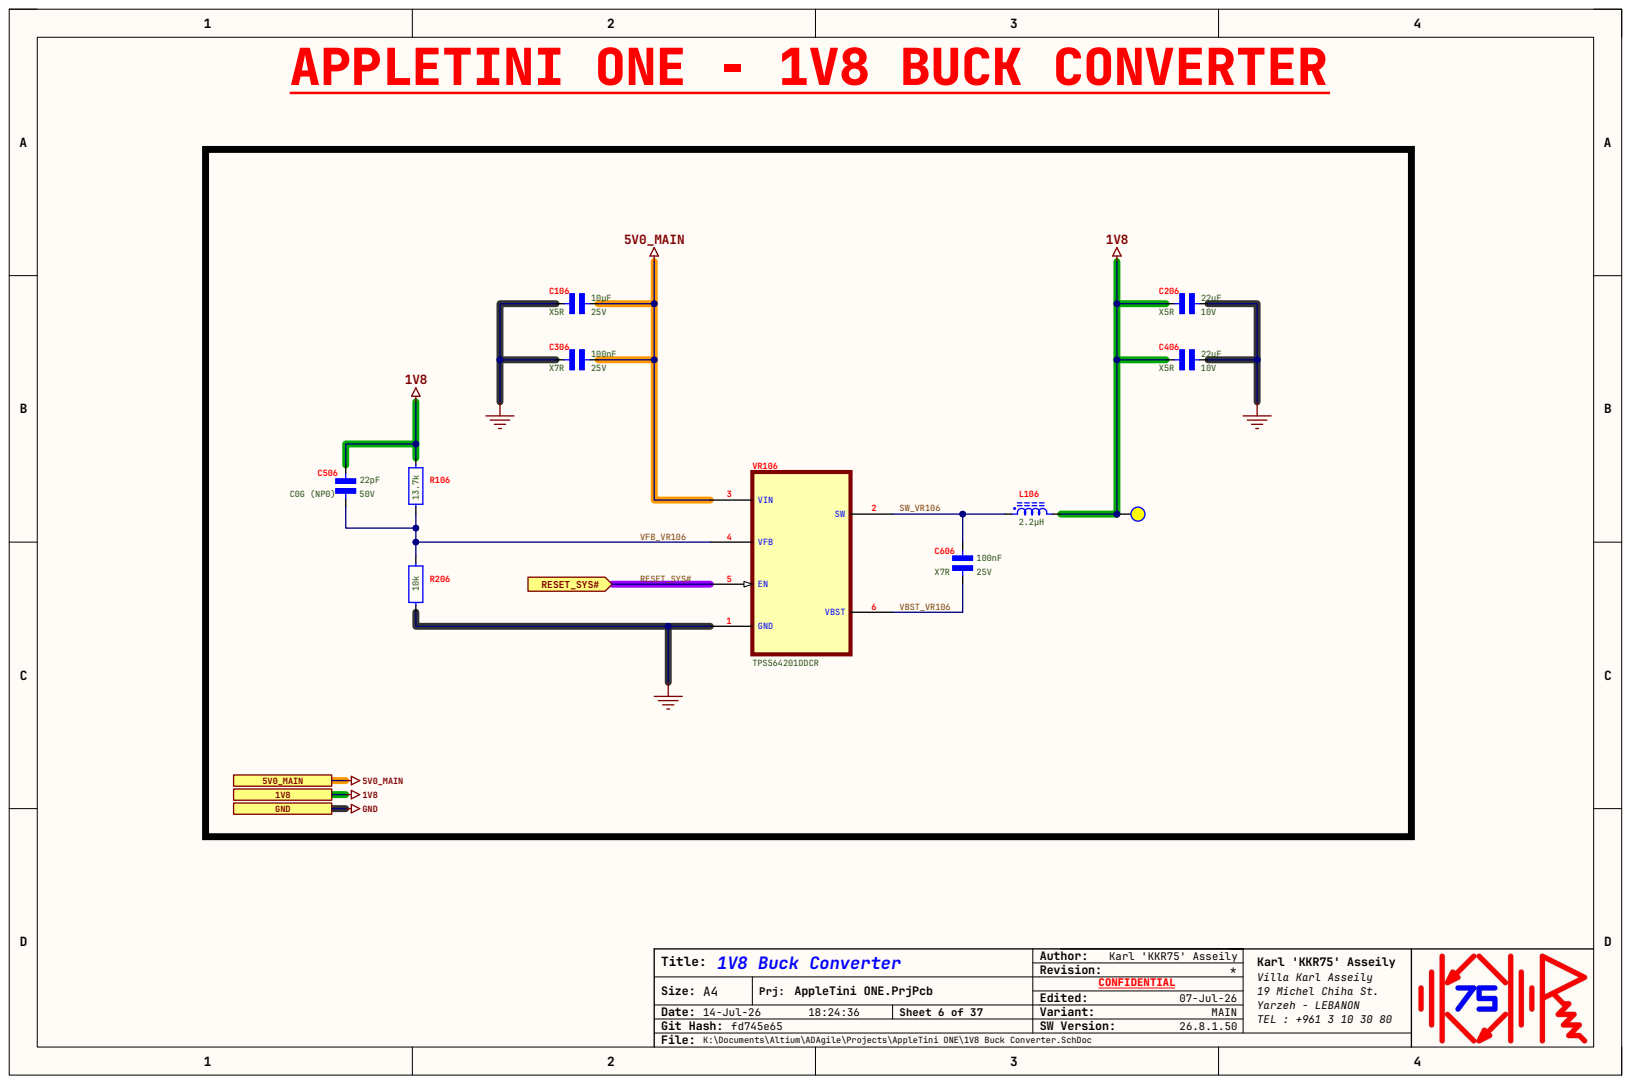
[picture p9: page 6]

Prj: AppleTini ONE.PrjPcb

File: K:\Documents\Altium\ADAgile\Projects\AppleTini ONE\1V8 Buck Converter.SchDoc

A A

# APPLETINI ONE - 3V3 BUCK CONVERTER

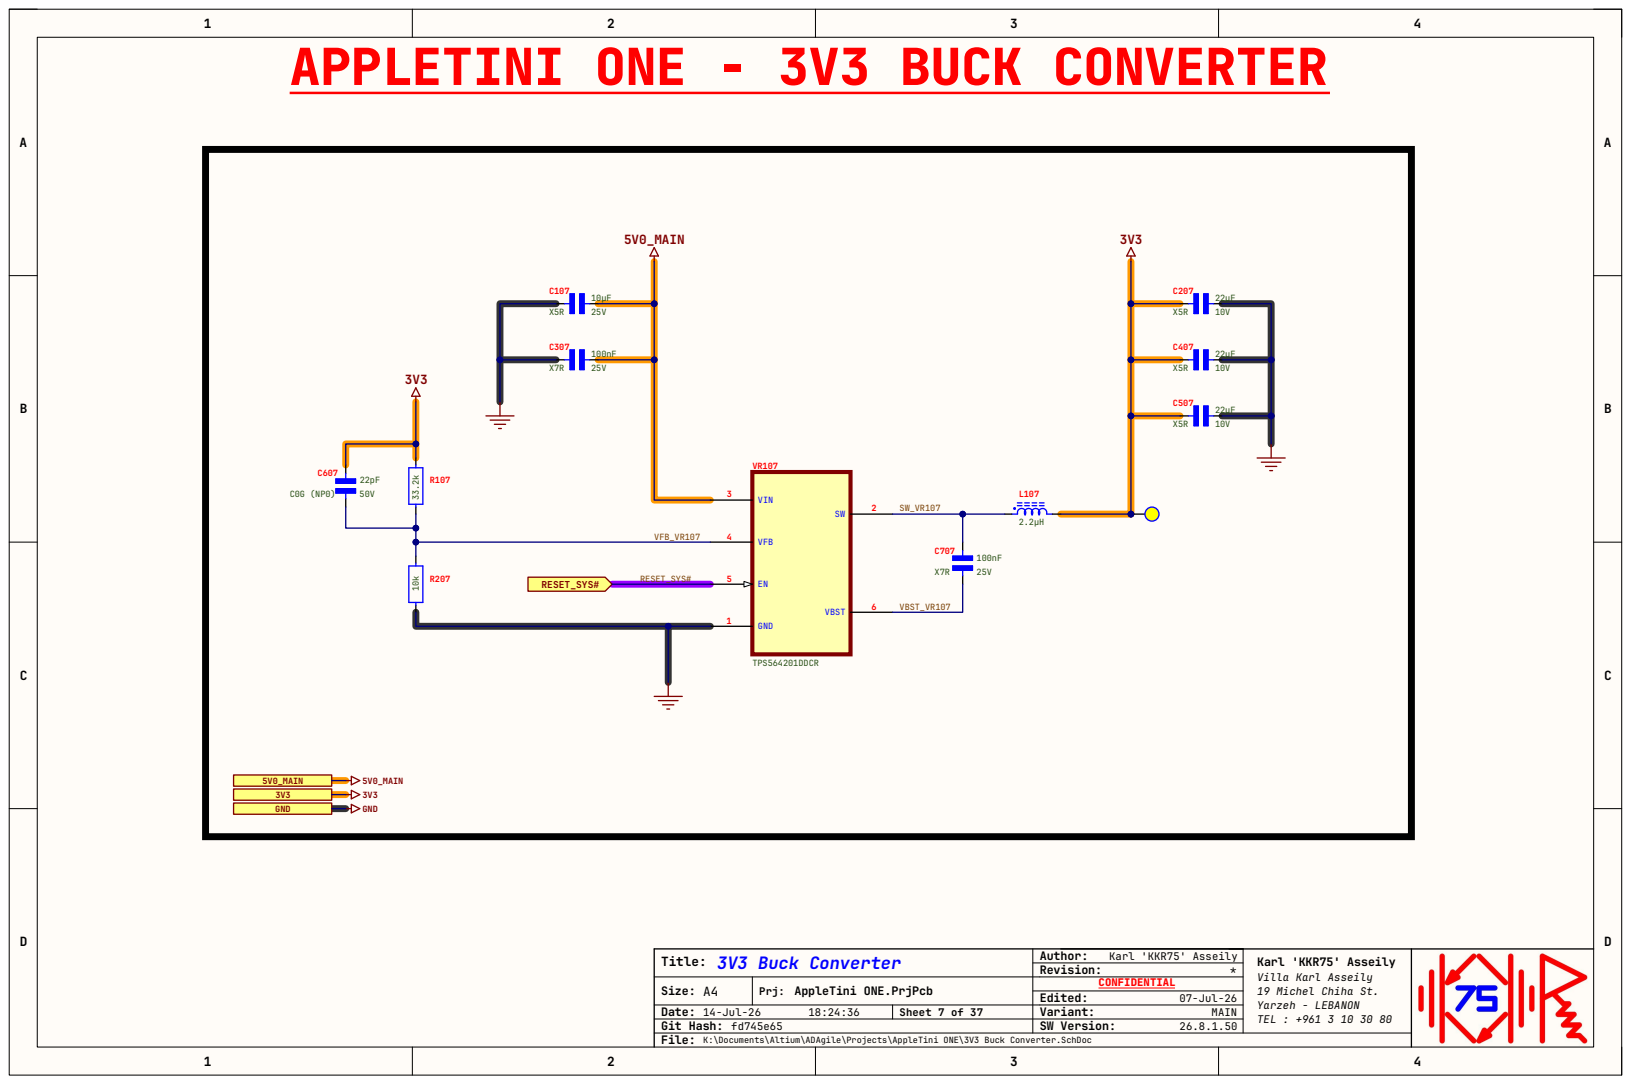
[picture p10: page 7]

Prj: AppleTini ONE.PrjPcb

File: K:\Documents\Altium\ADAgile\Projects\AppleTini ONE\3V3 Buck Converter.SchDoc

A A

# APPLETINI ONE - POWER SUPERVISOR

Villa Karl Asseily
19 Michel Chiha St.
Yarzeh - LEBANON
TEL : +961 3 10 30 80

Prj: AppleTini ONE.PrjPcb

File: K:\Documents\Altium\ADAgile\Projects\AppleTini ONE\Power Supervisor.SchDoc

A A

# APPLETINI ONE - DDR TERMINATOR

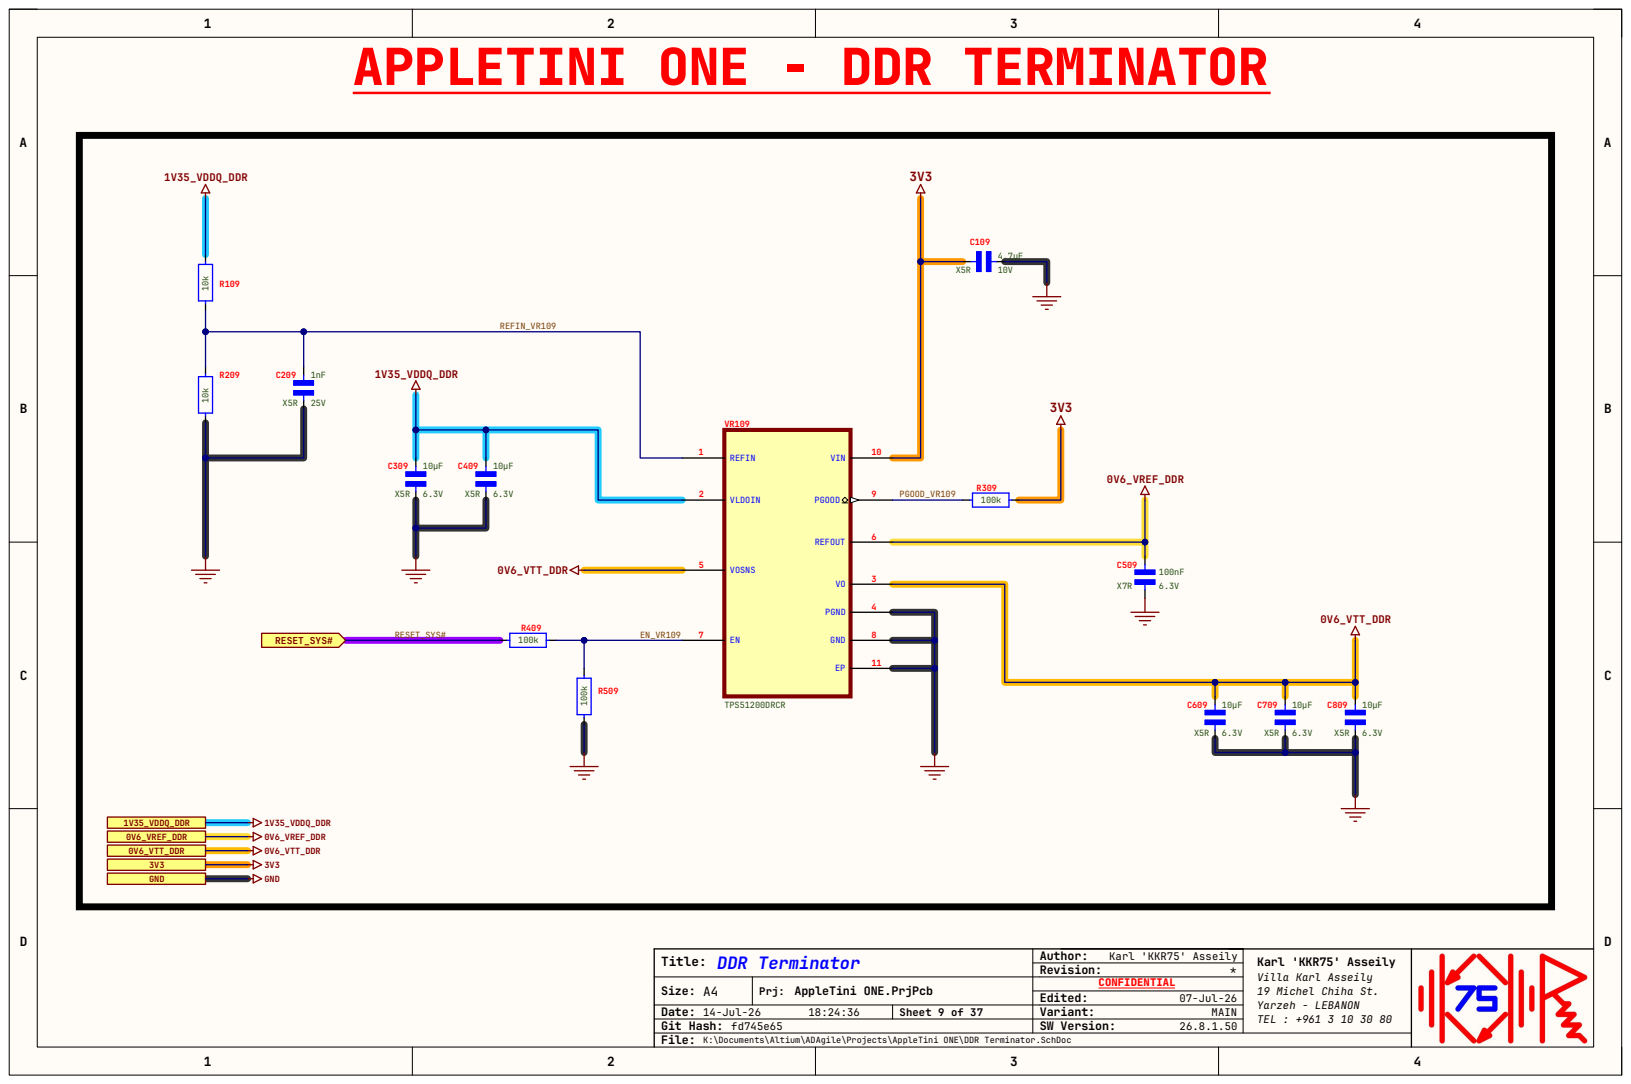
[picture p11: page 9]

Prj: AppleTini ONE.PrjPcb

File: K:\Documents\Altium\ADAgile\Projects\AppleTini ONE\DDR Terminator.SchDoc

A A

# APPLETINI ONE - ZYNQ-7020 SOC

Zynq Bank 13 (PL IO)
NOT USED

Zynq Bank 502 (PS DDR)

Zynq Bank 33 (PL IO)

Zynq Power (IO Rails)

Zynq Bank 0 (Config)

Zynq Bank 500 (PS MIO)

Zynq Bank 35 (PL IO)

Zynq Power (Core Rails)

USB0 RESET_SYS#
Zynq Bank 501 (PS MIO)

Zynq Bank 34 (PL IO)

Villa Karl Asseily
19 Michel Chiha St.
Yarzeh - LEBANON
TEL : +961 3 10 30 80

Prj: AppleTini ONE.PrjPcb

File: K:\Documents\Altium\ADAgile\Projects\AppleTini ONE\Zynq-7020 SOC.SchDoc

A A

# APPLETINI ONE - ZYNQ BANK 13 (PL IO)

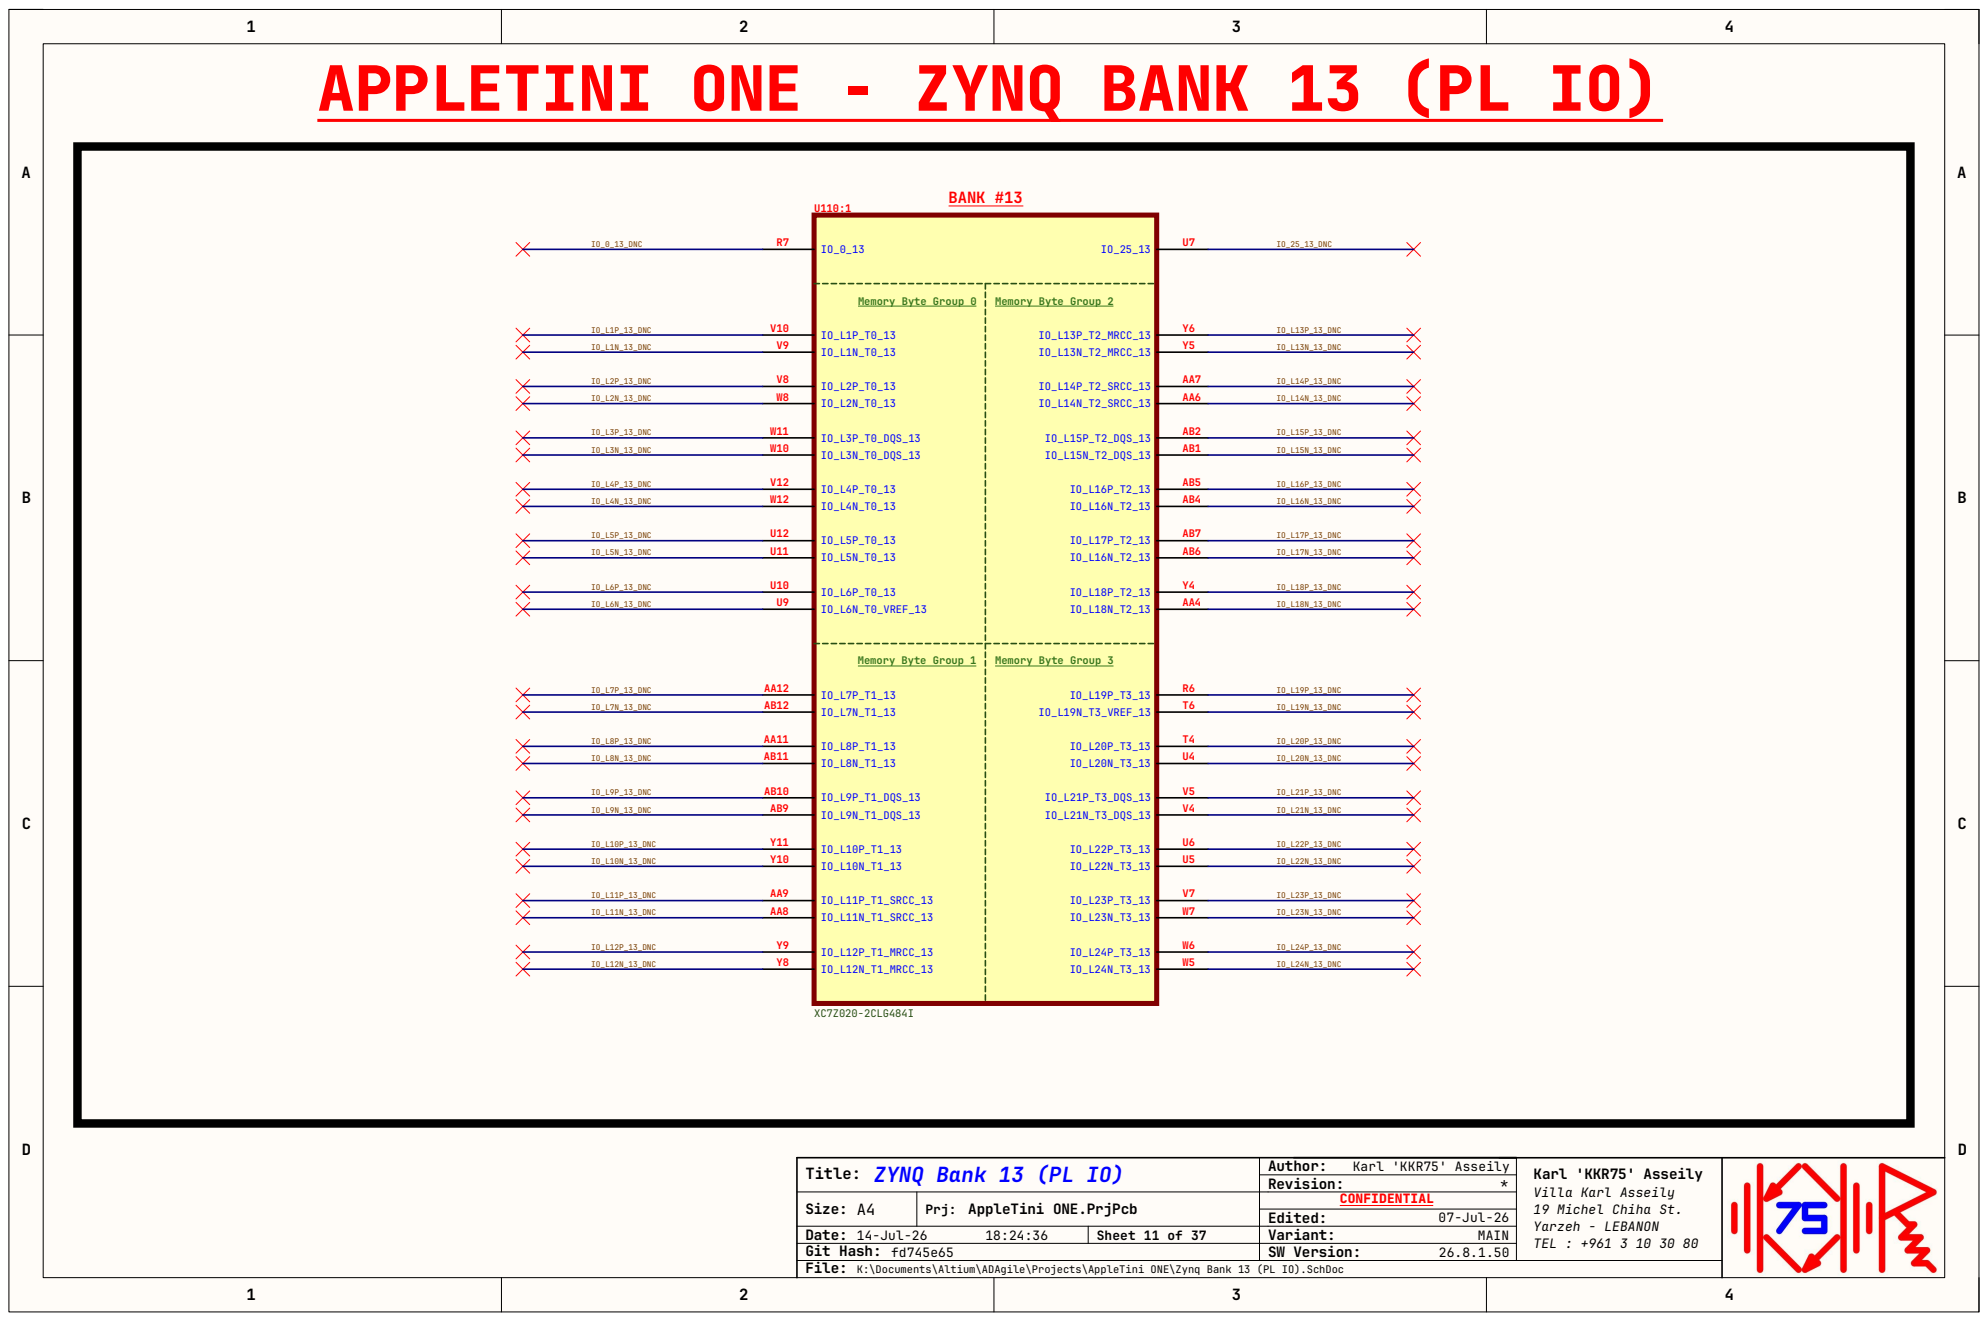
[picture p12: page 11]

Prj: AppleTini ONE.PrjPcb

File: K:\Documents\Altium\ADAgile\Projects\AppleTini ONE\Zynq Bank 13 (PL IO).SchDoc

A A

# APPLETINI ONE - ZYNQ BANK 33 (PL IO)

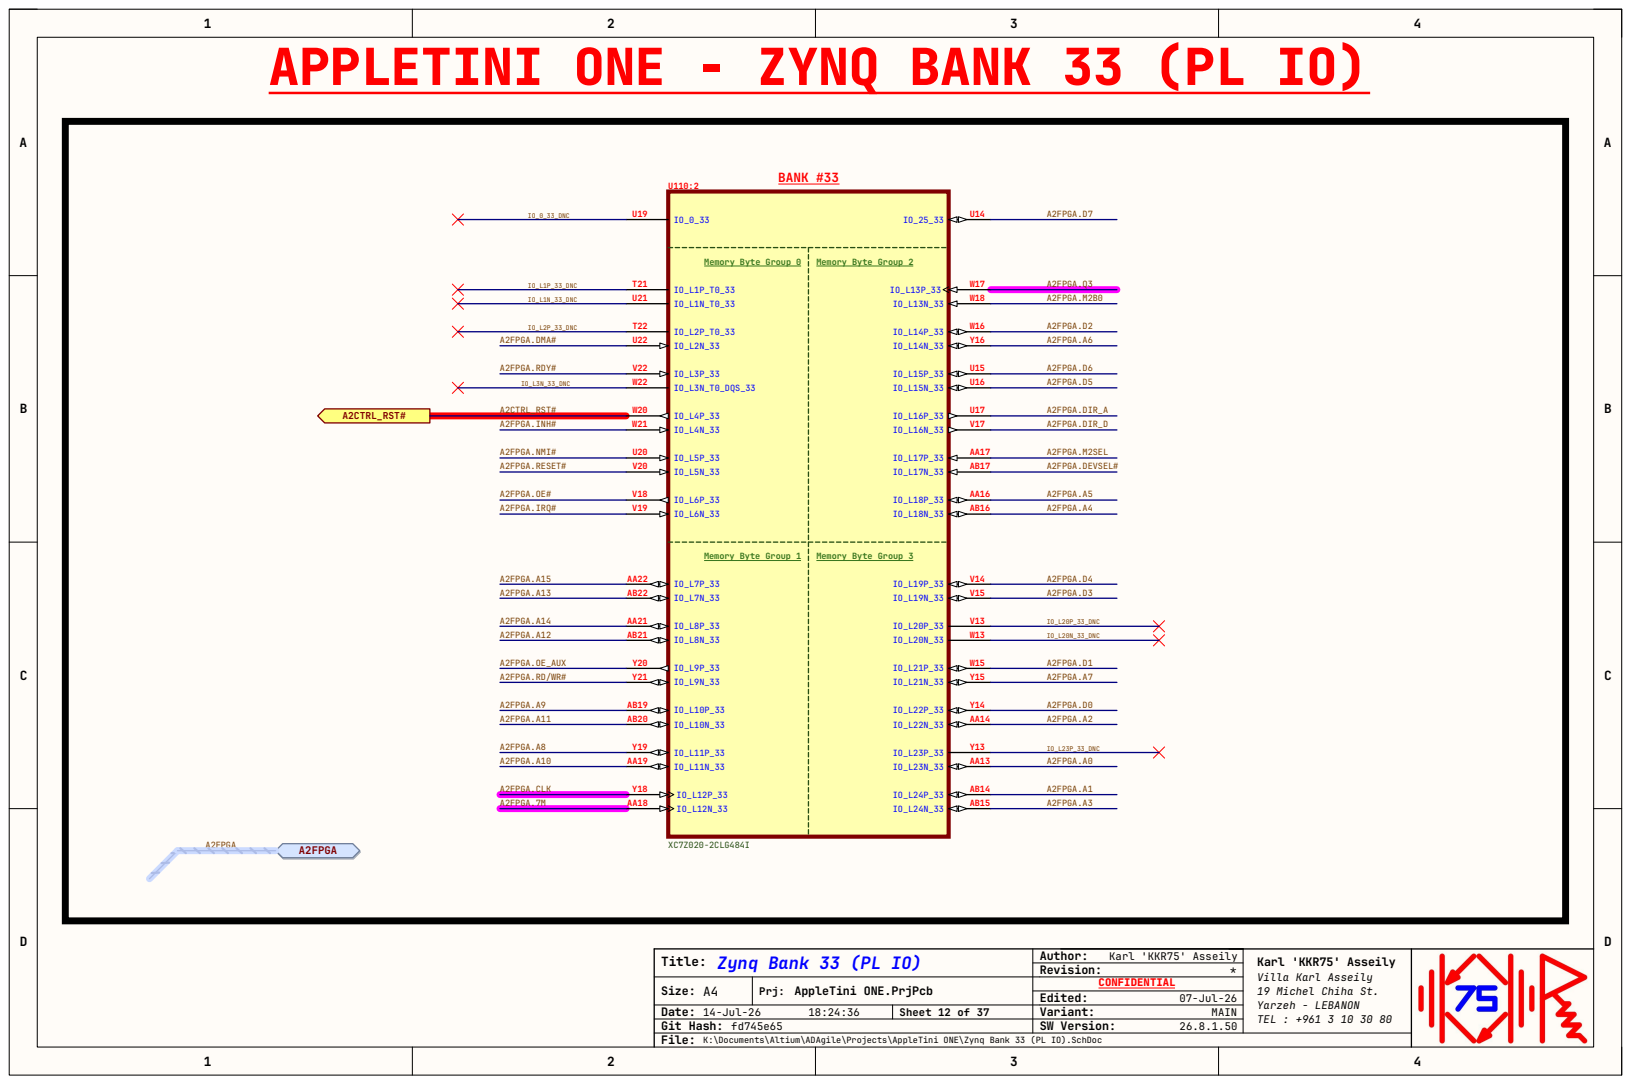
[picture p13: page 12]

Prj: AppleTini ONE.PrjPcb

File: K:\Documents\Altium\ADAgile\Projects\AppleTini ONE\Zynq Bank 33 (PL IO).SchDoc

A A

# APPLETINI ONE - ZYNQ BANK 34 (PL IO)

Prj: AppleTini ONE.PrjPcb

File: K:\Documents\Altium\ADAgile\Projects\AppleTini ONE\Zynq Bank 34 (PL IO).SchDoc

A A

# APPLETINI ONE - ZYNQ BANK 35 (PL IO)

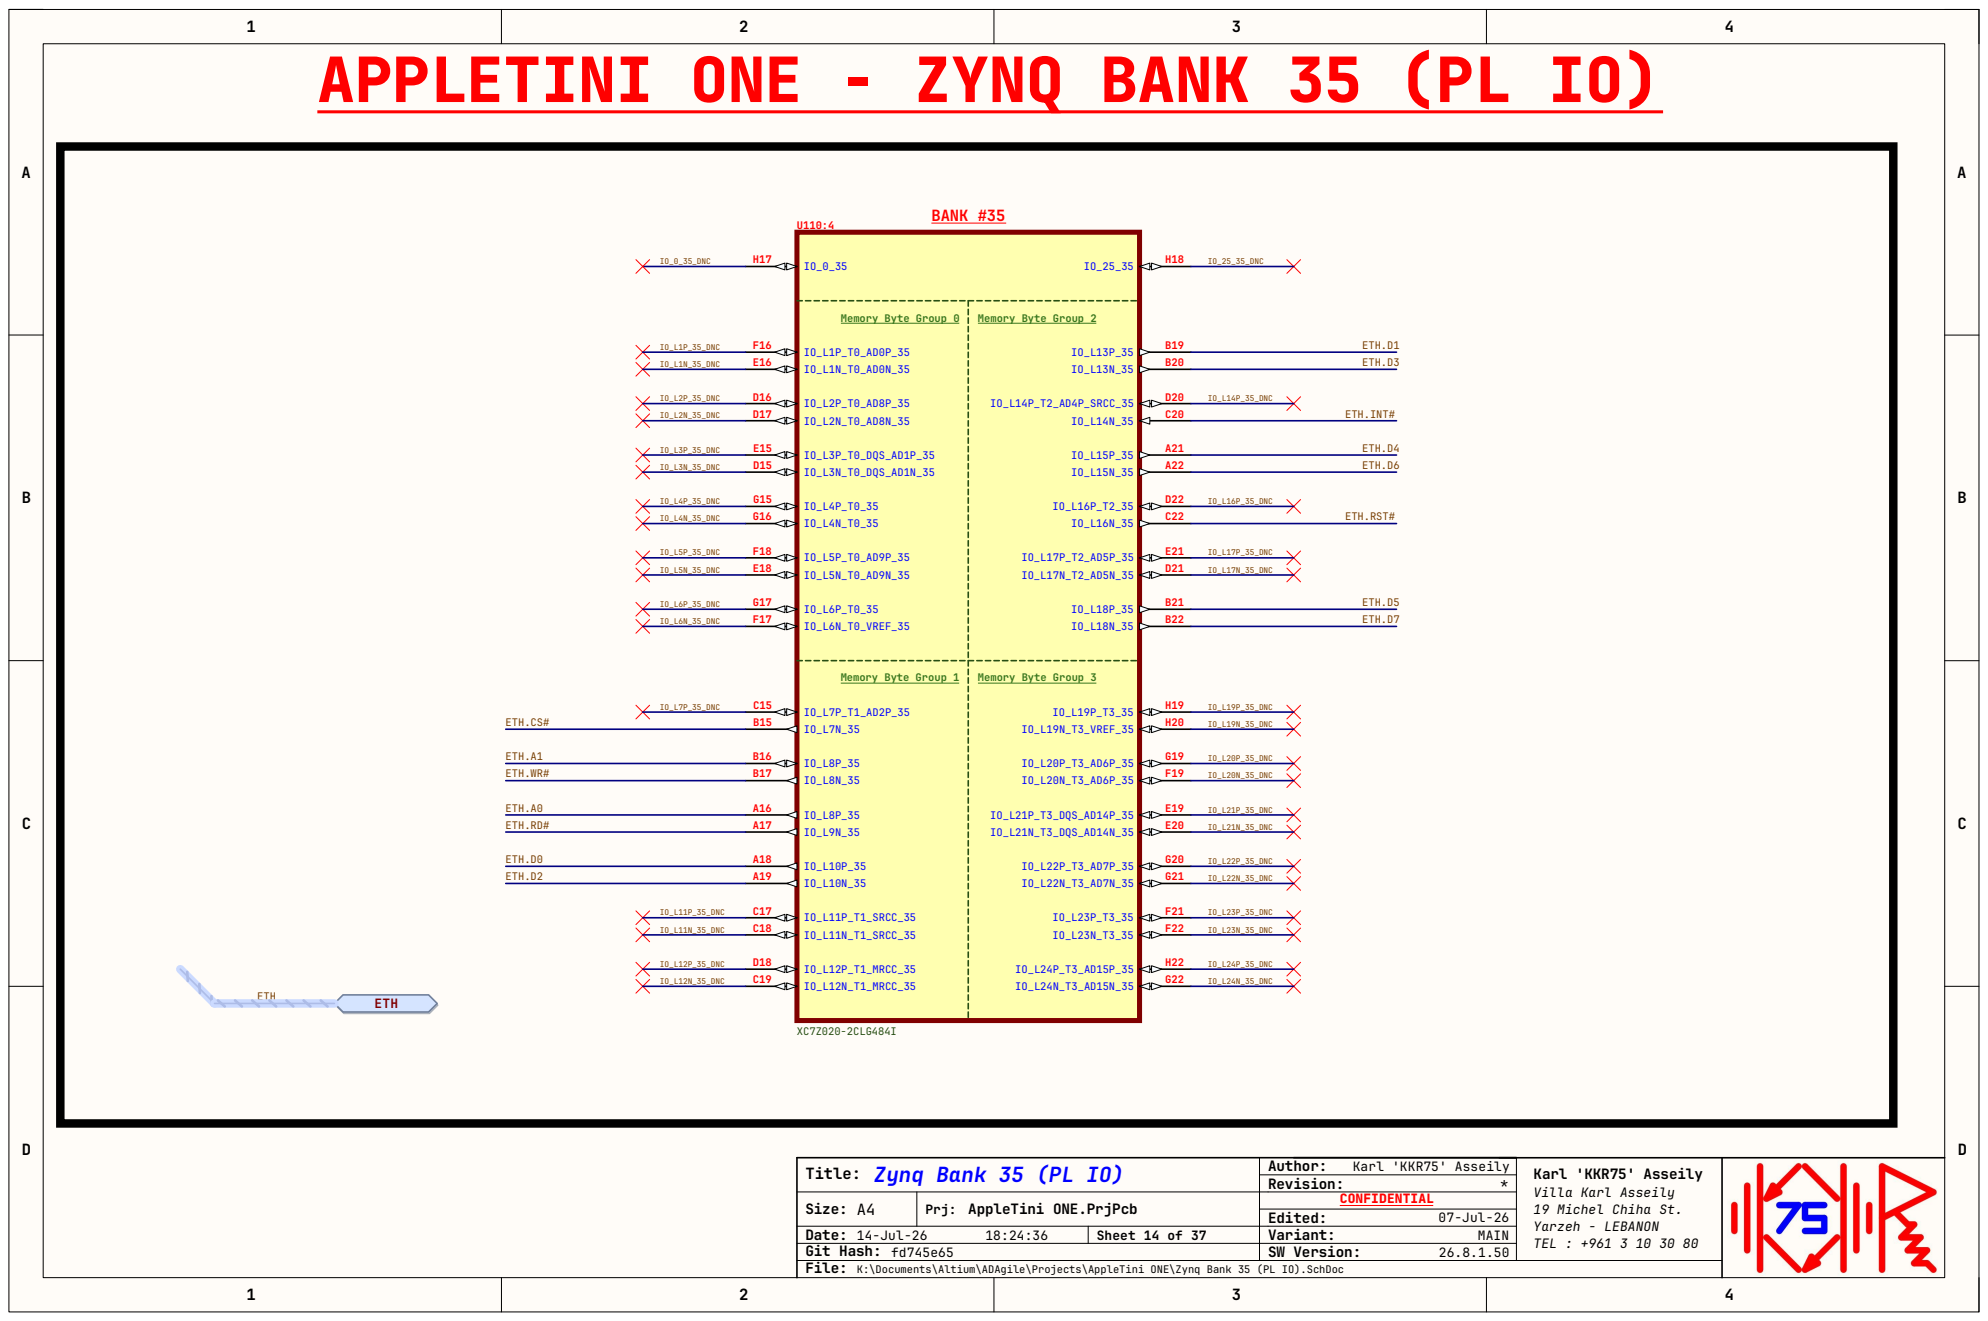
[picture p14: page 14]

Prj: AppleTini ONE.PrjPcb

File: K:\Documents\Altium\ADAgile\Projects\AppleTini ONE\Zynq Bank 35 (PL IO).SchDoc

A A

# APPLETINI ONE - ZYNQ BANK 0 (CONFIG)

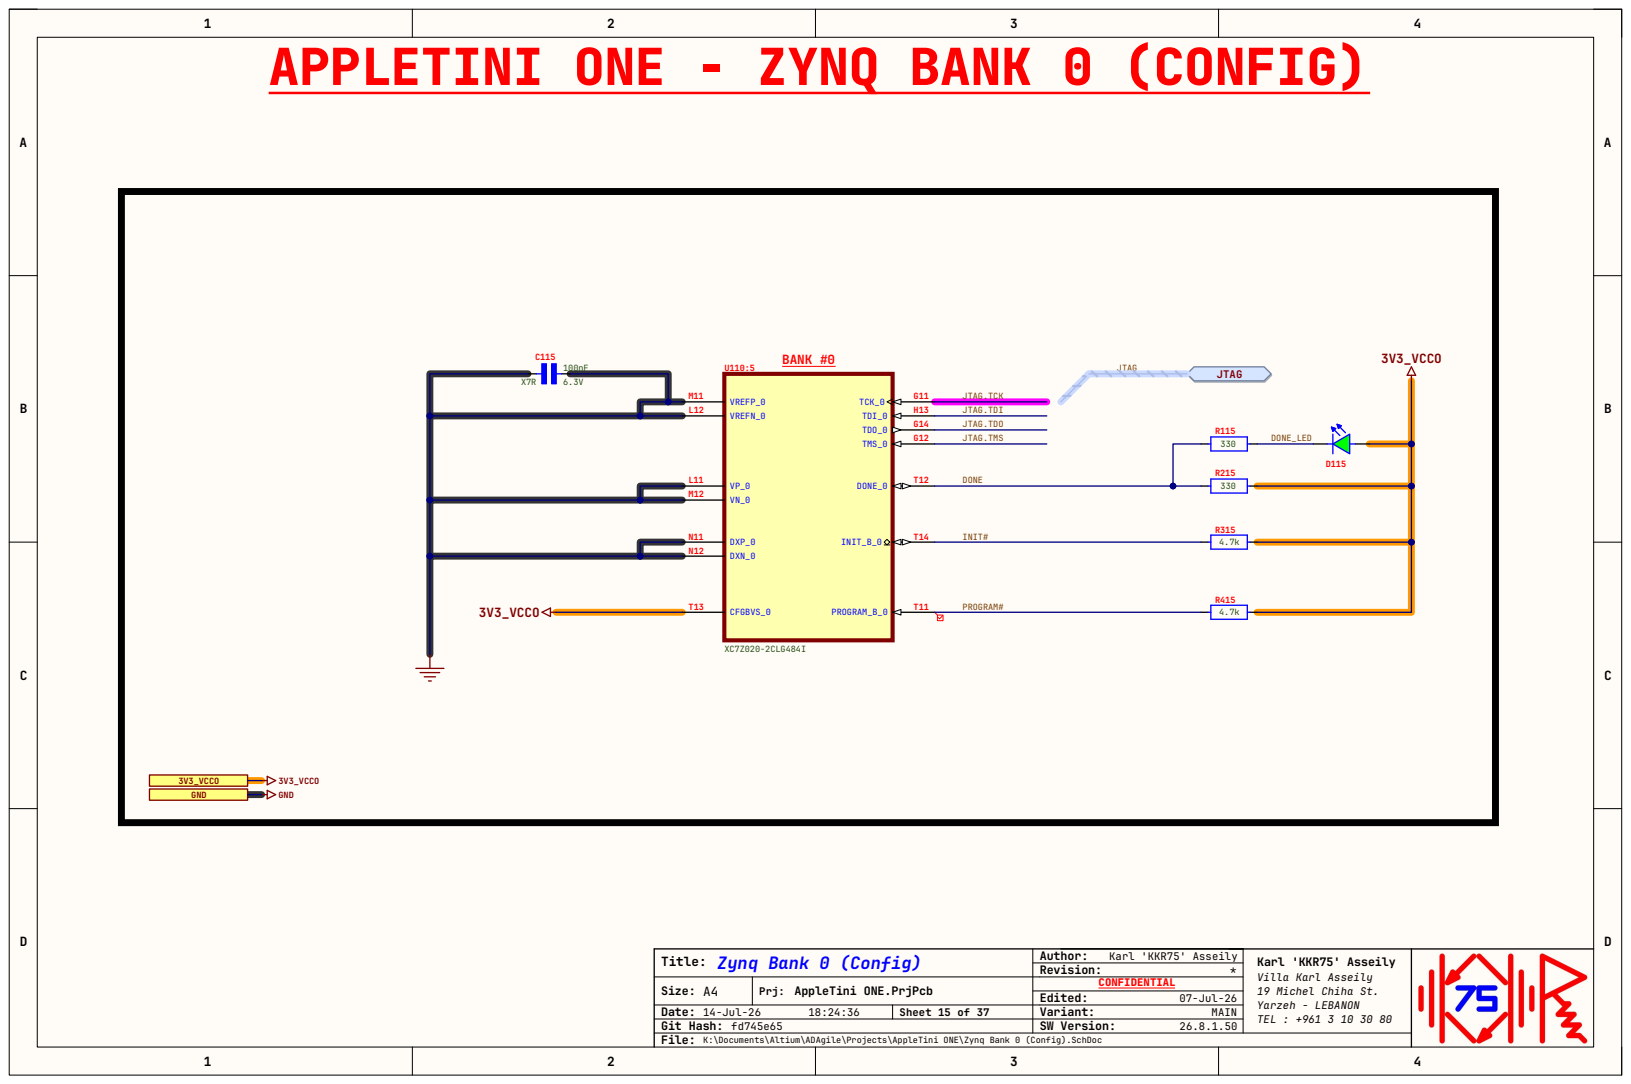
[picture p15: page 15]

Prj: AppleTini ONE.PrjPcb

File: K:\Documents\Altium\ADAgile\Projects\AppleTini ONE\Zynq Bank 0 (Config).SchDoc

A A

# APPLETINI ONE - ZYNQ BANK 500 (PS MIO)

QSPI PROGRAMMING PROCEDURE:
Power OFF → DIP2 ON → Power ON → DIP2 OFF → Program flash.
DIP2 selects JTAG boot at reset but must be OFF during flash
access because BOOT_MODE0 is reused as QSPI_IO3 / flash HOLD#.

DIP Switch Factory Defaults :
ALL OFF (DOWN): QSPI Boot (100), JTAG cascaded (0), PLL Enabled (0)

DIP3 UP only (110) : SD Card Boot
DIP2 UP only (000) : JTAG Boot

Prj: AppleTini ONE.PrjPcb

File: K:\Documents\Altium\ADAgile\Projects\AppleTini ONE\Zynq Bank 500 (PS MIO).SchDoc

A A
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

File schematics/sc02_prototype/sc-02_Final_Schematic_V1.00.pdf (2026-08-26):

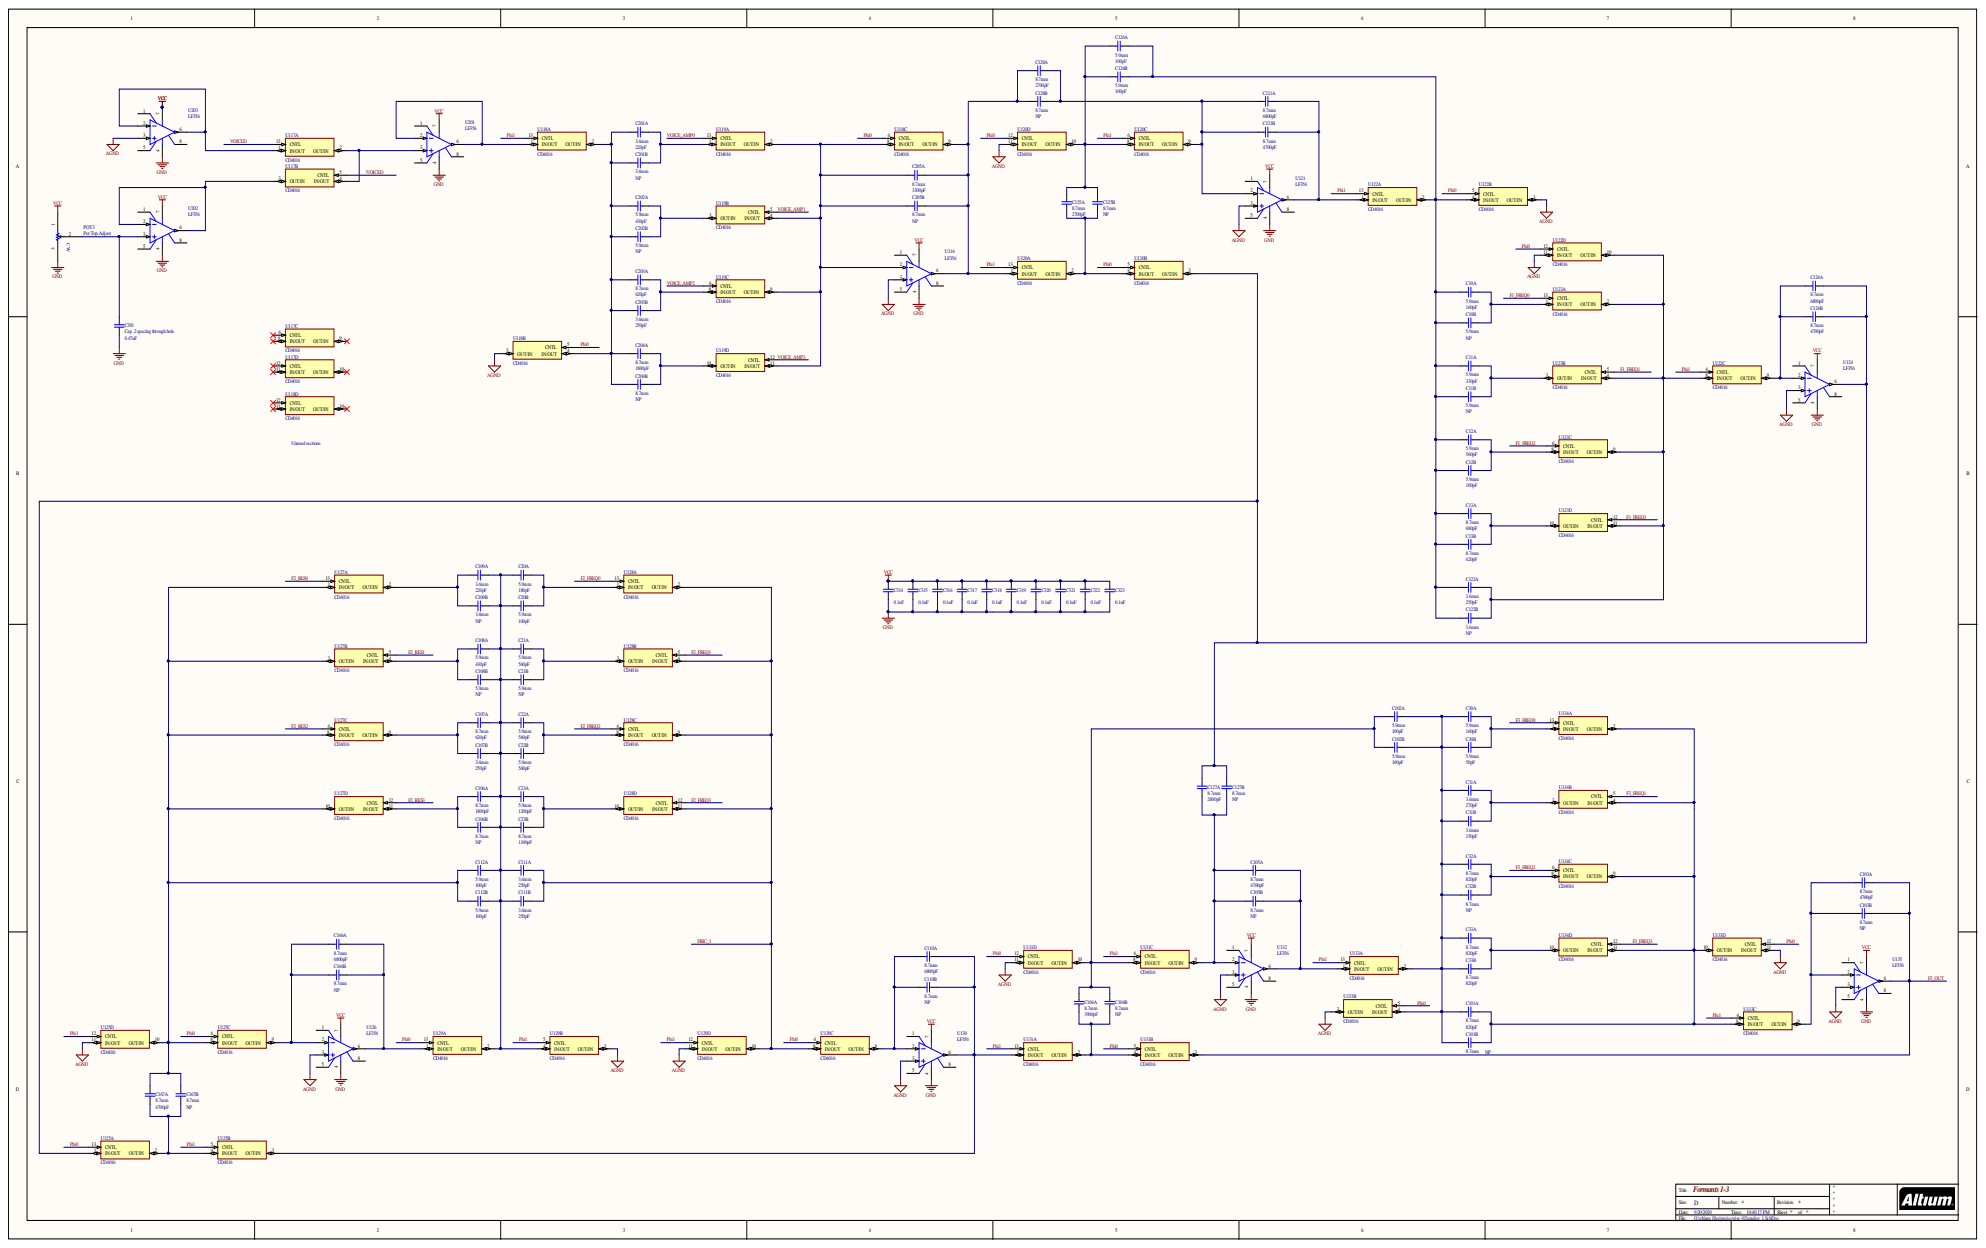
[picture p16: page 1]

Title Formants 1-3 | * * * * *

Size: D | Number: * | Revision: *

Date: 9/20/2020 Time: 10:40:17 PM | | Sheet * of *

Q:\altium files\projects\sc-02\analog_1.SchDoc

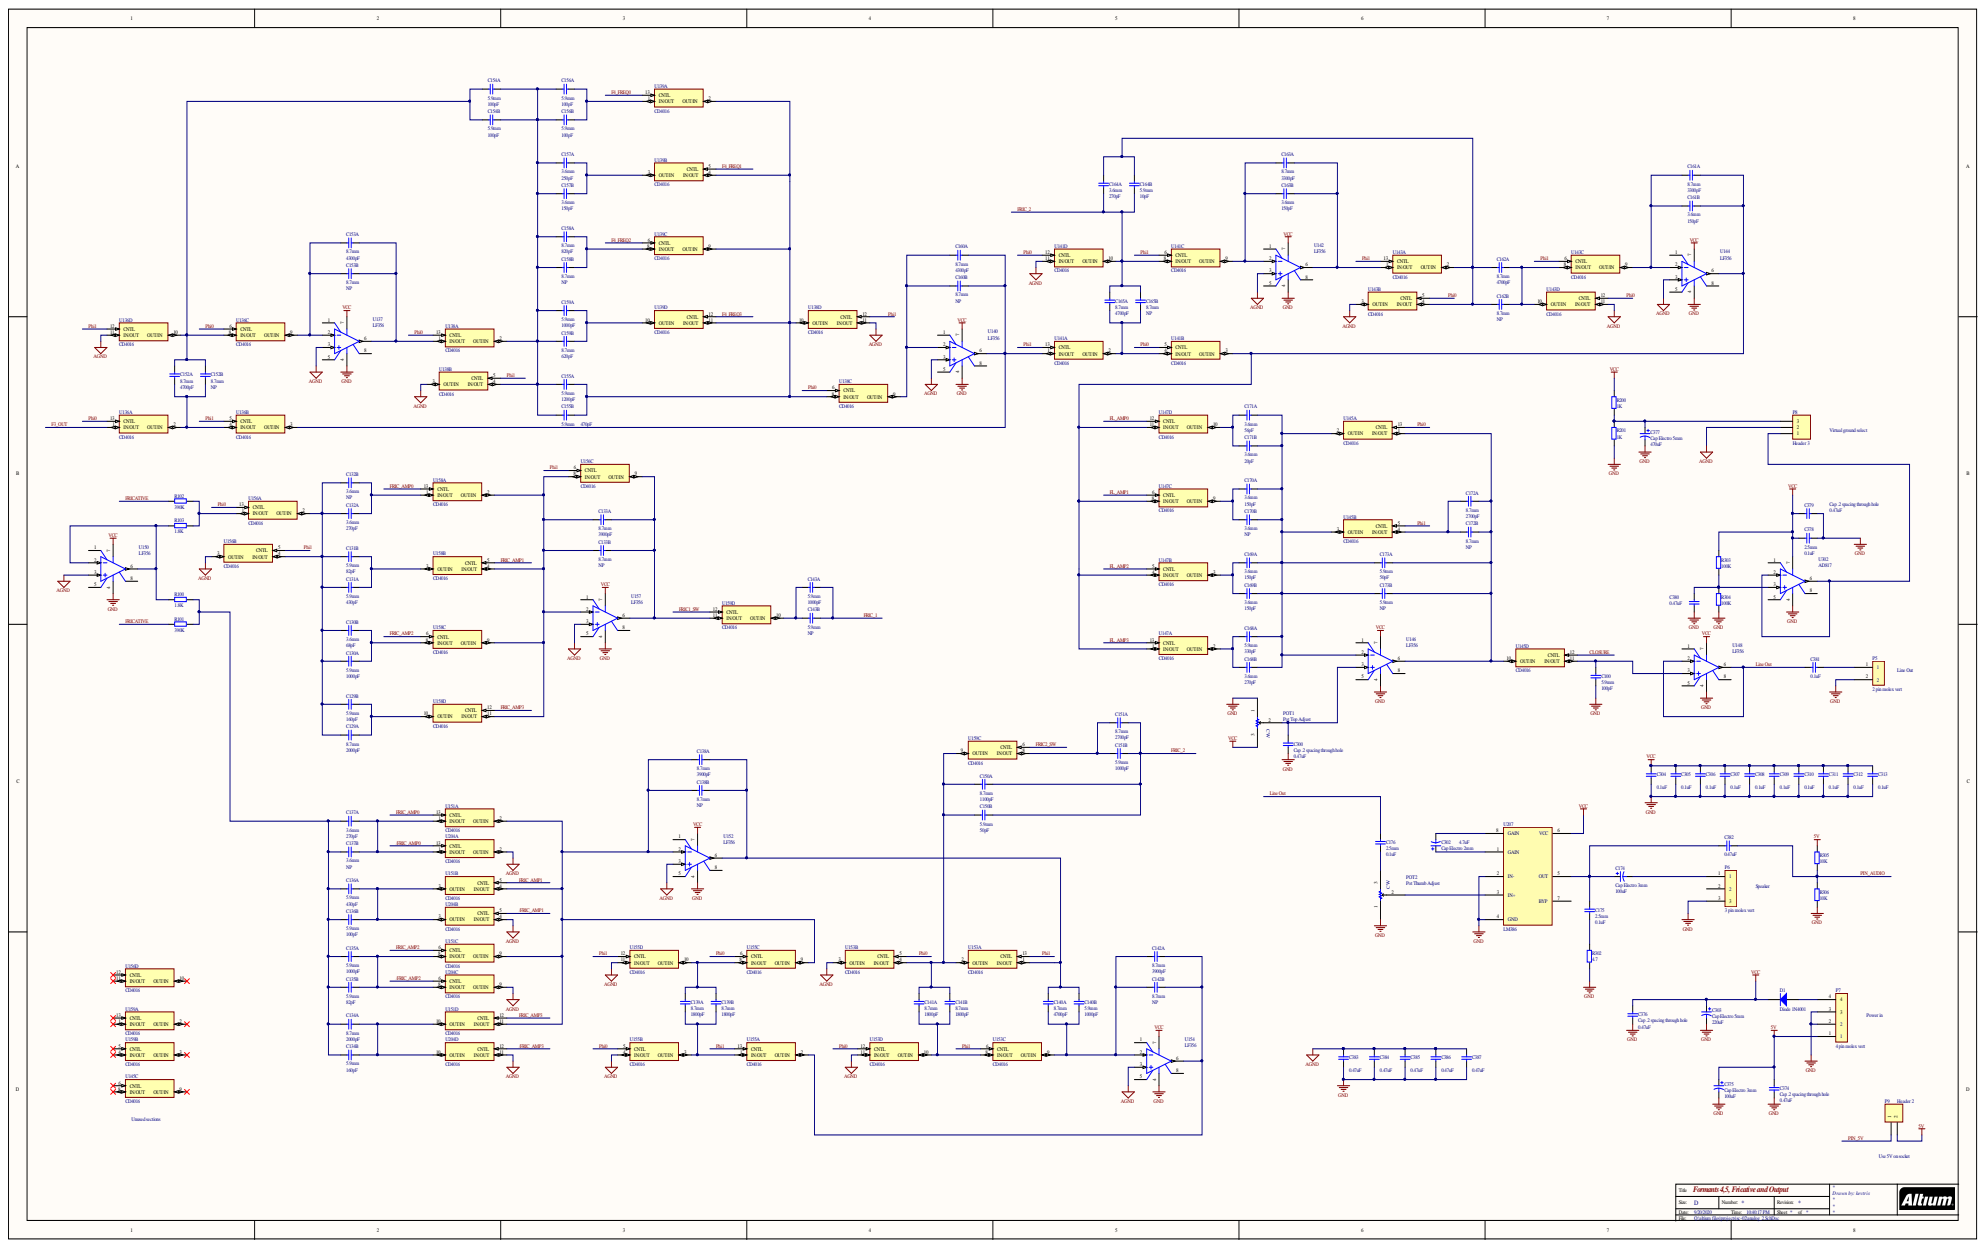
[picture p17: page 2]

/FRIC_AMP2 | CD4016 AGND | CNTL 12 | CNTL 6 | OUT/IN 3 IN/OUT | 4 | IN/OUT | 1 OUT/IN 2

Cap Electro 3mm
Cap .2 spacing through hole 100uF

Title Formants 4,5, Fricative and Output | * Drawn by: kevtris * * *

Size: D | Number: * | Revision: *

Date: 9/20/2020 Time: 10:40:17 PM | | Sheet * of *

Q:\altium files\projects\sc-02\analog_2.SchDoc


U66 did not have its/RST line tied high so
the prototype acted flaky until it was pulled up.

the new signalsthat weren'tsupported.
This was added to level translate

CAUTION: header pins are swapped for DIP header use!

This was added to allow for using the external clock.
On the proto it is grounded.
R300 was added to pull it up when not grounded.

to latch the address. /CE is pulsed high right before WRITE goes active

F7425's are impossible to getso this change lets
74C89's work instead. They need to have /CE pulsed

RS1 1 | GND 10 | LAT_A1

The three gates used were previously unused.

This happens at the start of each cycle.

This was added to allow using
an external clock.

Thisflipflop was not used originally.

Q:\altium files\projects\sc-02\digital_1.SchDoc


Title Transition Logic | * Drawn by: kevtris * * *

Size: D | Number: * | Revision: *

Date: 9/20/2020 Time: 10:40:18 PM | | Sheet * of *

Q:\altium files\projects\sc-02\digital_2.SchDoc


D 9 SET CLK 11 RST | PE 9 CET 10 CEP 7 | 3

Title TimingControl Logic, A/RLogic | * Drawn by: kevtris * * *

Size: D | Number: * | Revision: *

Date: 9/20/2020 Time: 10:40:18 PM | | Sheet * of *

Q:\altium files\projects\sc-02\digital_3.SchDoc


GND | CLR 1 CLK 9 D1 4 Q1 | 2

SEL2

This was grounded on the proto

5 4 12 AMPCT_ZERO | 2 8 CD4081

Title WriteControl, Fricative/Voiced | * Drawn by: kevtris * * *

Size: D | Number: * | Revision: *

Date: 9/20/2020 Time: 10:40:18 PM | | Sheet * of *

Q:\altium files\projects\sc-02\digital_4.SchDoc


Title Data Latching | * Drawn by: kevtris * * *

Size: D | Number: * | Revision: *

Date: 9/20/2020 Time: 10:40:18 PM | | Sheet * of *

Q:\altium files\projects\sc-02\digital_5.SchDoc
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

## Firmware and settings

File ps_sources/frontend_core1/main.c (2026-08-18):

/*
 * frontend_core1/main.c -- CPU1 firmware (AMP).
 *
 * Runs the apple_cycle_egress poll + apple_cycle_renderer
 * dispatch loop. CPU0 (frontend) handles UI, compositor, smartport,
 * UART input, etc. -- everything that is latency-sensitive to host
 * input. CPU1 owns the Apple-bus stream end-to-end:
 *
 *   1. Drains records from the PL cycle ring (DDR @ 0x3F200000) via
 *      apple_cycle_egress_poll().
 *   2. Dispatches per-cycle records into apple_cycle_renderer_on_record
 *      which walks the NTSC core's per-cycle scan state.
 *   3. On each clean Apple frame edge, publishes the just-rendered
 *      560x192 BGRA32 slot via apple_fb_writer_publish() (atomic
 *      handoff in apple_fb_handoff.c). CPU0's compositor claims
 *      the latest published slot at its own rate.
 *
 * Sharing rules:
 *   - CPU0 writes the egress config registers (cfg_enable, ring
 *     base, etc.) once during boot via apple_cycle_egress_init().
 *     Then ownership transfers: CPU1 polls. CPU1 must NOT call
 *     apple_cycle_egress_init() again -- it would zero CPU0's
 *     work (the producer pointer slot).
 *   - The shadow banks (g_main_bank/g_aux_bank) and the FB slots
 *     are written by CPU1, read by CPU0 (compositor). Coherency:
 *     CPU1 dcache-flushes the slot before the atomic publish
 *     (already done in apple_cycle_renderer.c on_frame_end).
 *     CPU0's MMU has the same slot regions as cacheable so its
 *     read pulls from L1; we rely on the SCU + dsb-after-flush
 *     to make CPU1's writes visible. If we see staleness, we'll
 *     either invalidate on CPU0's side or mark the slot region
 *     non-cacheable on both.
 */

#include <stdint.h>

#include "xiltimer.h"     /* COUNTS_PER_SECOND */

#include "../lib/common.h"
#include "../lib/axisimple_mmio.h"
#include "../lib/uart.h"

#include "../frontend/apple_cycle_egress.h"
#include "../frontend/apple_cycle_renderer.h"
#include "../frontend/apple_fb_handoff.h"
#include "../frontend/apple_pal_video_timing.h"
#include "../frontend/card_control_regs.h"
#include "../frontend/linear_text_overlay.h"

#define RESET_RELEASE_REG            0x4000000CU
#define RESET_RELEASE_CPU1_READY_BIT (1UL << 1)

/* ---- Live CPU1 health line (UART0, TX shared with CPU0) ----------------
 * Emits one line per ~second carrying per-interval deltas, so the PAL
 * renderer's effect on the capture path is visible while testing. On a
 * renderer that keeps up, steady state is:
 *
 *   gap=0  ovr=0  resync=0   frames ~= 50 (PAL) / 60 (NTSC)
 *
 * The PAL "render too slow on CPU1" failure mode shows up as gap>0 and/or
 * ovr>0 (the on-chip capture FIFO overflowed and the egress emitted gap
 * markers), resync climbing (the renderer dropping to the next frame edge),
 * and frames collapsing well below the line rate. Fields:
 *
 *   dt_ms   measured interval length (sanity)
 *   frames  g_acr_frames_complete  delta  -- completed frames / interval
 *   gap     g_gap_markers_seen     delta  -- FIFO/ring overflow markers
 *   ovr     g_oversized_drains     delta  -- drain hit ACE_POLL_RECORD_CAP
 *   resync  g_acr_resyncs_cleared  delta  -- renderer resync events
 *   lastrec g_acr_last_frame_records       -- records in last completed frame
 *   raw     g_acr_frame_edges_seen delta   -- incoming Apple frame edges seen
 *   recpf   recs/raw delta average         -- records per incoming frame
 *   recs    g_records_processed    delta  -- Apple-bus record throughput
 *   polls   g_poll_calls           delta  -- egress poll iterations
 *   palok   g_pal_frames_published delta  -- PAL frames completed/published
 *   paldrop g_pal_frames_dropped   delta  -- PAL frames skipped/dropped whole
 *   paltry  palok+paldrop delta            -- PAL accepted+skipped frame attempts
 *   palln   g_pal_lines_rendered   delta  -- PAL lines rendered
 *   palbad  g_pal_lines_incomplete delta  -- incomplete captured PAL lines
 *   palovr  g_pal_queue_overflows  delta  -- PAL render queue overflows
 *   palqmax g_pal_queue_max               -- high-water queue depth
 *   palfast g_pal_fast_lines delta         -- constant-soft-switch fast lines
 *   palslow g_pal_slow_lines delta         -- delayed-transition fallback lines
 *   palus   avg render time per PAL line   -- from ARM global timer
 *   palmax  worst render time per PAL line -- lifetime max, usec
 *   palend  avg queue depth at end-frame   -- before bounded frame flush
 *   palendm worst queue depth at end-frame -- lifetime max
 *   palfl   lines drained at end-frame     -- bounded frame flush work
 *
 * Set to 1 for profiling builds. Leave 0 for normal firmware; this compiles
 * out the timer reads, counter snapshots, decimal formatting, and UART writes. */
#define CPU1_STATUS_UART 0

static uint32_t apple_reset_status_read(void)
{
    return REG_READ(CARD_CTRL_APPLE_RESET_STATUS_REG);
}

/* ---- Diagnostic: text-page shadow dump (diag/transwarp-video-freeze) ----
 * Prints the 40x24 text page 1 ($0400-$07FF) from the requested shadow
 * bank, decoded to readable ASCII, plus the capture counters at dump
 * time. Runs on CPU1 because the shadow banks are cacheable and written
 * through THIS core's L1 -- only CPU1's view is guaranteed current.
 * Triggered from CPU0's UART console (":shadow [main|aux]") via the
 * strongly-ordered request word in apple_fb_handoff.
 *
 * Emitted one line per main-loop pass: a full-dump blocking print
 * (~13 ms at 921600 baud) would overflow the 8 ms cycle ring and inject
 * the very gap markers this build exists to observe. One line (~0.5 ms)
 * keeps the ring backlog under ~600 records between egress polls. */
static uint32_t s_dump_req  = APPLE_FB_DUMP_NONE;
static uint32_t s_dump_row  = 0u;

static void cpu1_dump_text_shadow_step(void)
{
    const volatile uint8_t *bank;
    uint32_t queued;
    uint32_t base;
    uint32_t col;

    /* Take a new request even while a row dump is active. This lets the
     * short A2Li query replace an old MAIN/AUX dump instead of appearing
     * to run the default MAIN command first. */
    queued = apple_fb_debug_dump_take();
    if (queued != APPLE_FB_DUMP_NONE) {
        s_dump_req = queued;
        s_dump_row = 0u;

        if (s_dump_req == APPLE_FB_DUMP_A2LI) {
            /* Single-line paged-mode gate dump; ~1 ms, no row stepper. */
            apple_cycle_renderer_debug_a2li_line();
            s_dump_req = APPLE_FB_DUMP_NONE;
            return;
        }
        if (s_dump_req != APPLE_FB_DUMP_TEXT_MAIN &&
            s_dump_req != APPLE_FB_DUMP_TEXT_AUX) {
            uart_puts(UART0_BASE, "[cpu1] shadow: invalid request\r\n");
            s_dump_req = APPLE_FB_DUMP_NONE;
            return;
        }

        /* First pass: header with the counters at request time. */
        uart_puts(UART0_BASE, "\r\n[cpu1] shadow dump: ");
        uart_puts(UART0_BASE,
                  (s_dump_req == APPLE_FB_DUMP_TEXT_AUX) ? "AUX" : "MAIN");
        uart_puts(UART0_BASE, " $0400-$07FF  bus_writes=");
        uart_putdec(UART0_BASE, g_bus_writes_seen);
        uart_puts(UART0_BASE, " recs=");
        uart_putdec(UART0_BASE, g_records_processed);
        uart_puts(UART0_BASE, " gaps=");
        uart_putdec(UART0_BASE, g_gap_markers_seen);
        uart_puts(UART0_BASE, " frames=");
        uart_putdec(UART0_BASE, g_acr_frames_complete);
        uart_puts(UART0_BASE, "\r\n");
        return;
    }

    if (s_dump_req == APPLE_FB_DUMP_NONE) {
        return;
    }

    if (s_dump_row >= 24u) {
        uart_puts(UART0_BASE, "[cpu1] shadow dump end\r\n");
        s_dump_req = APPLE_FB_DUMP_NONE;
        return;
    }

    bank = (s_dump_req == APPLE_FB_DUMP_TEXT_AUX) ? g_aux_bank : g_main_bank;
    /* Standard interleaved text page 1 row base. */
    base = 0x0400u + ((s_dump_row & 7u) << 7) + ((s_dump_row >> 3) * 0x28u);

    uart_putdec(UART0_BASE, s_dump_row);
    uart_puts(UART0_BASE, (s_dump_row < 10u) ? "  |" : " |");
    for (col = 0u; col < 40u; col++) {
        /* Screen code -> printable: strip the high bit, remap the
         * inverse/flash control rows into the letter range. */
        uint8_t v = (uint8_t)(bank[base + col] & 0x7Fu);

        if (v < 0x20u) {
            v = (uint8_t)(v + 0x40u);
        }
        uart_putc(UART0_BASE, (char)v);
    }
    uart_puts(UART0_BASE, "|\r\n");
    s_dump_row++;
}

#if CPU1_STATUS_UART
/* Zynq-7000 ARM global timer (SCU @ 0xF8F00200): a free-running 64-bit counter
 * ticking at CPU_freq/2 == COUNTS_PER_SECOND. It is shared by both cores and
 * started at boot; we only ever READ it, so CPU0's timebase is untouched.
 * Reading the registers directly (rather than XTime_GetTime) keeps this
 * secondary-core diagnostic free of any XilTimer runtime-init assumption on
 * CPU1. */
#define GLOBAL_TMR_COUNT_LO 0xF8F00200U
#define GLOBAL_TMR_COUNT_HI 0xF8F00204U

static uint64_t global_timer_read(void)
{
    uint32_t hi;
    uint32_t lo;
    uint32_t hi_again;

    do {
        hi       = REG_READ(GLOBAL_TMR_COUNT_HI);
        lo       = REG_READ(GLOBAL_TMR_COUNT_LO);
        hi_again = REG_READ(GLOBAL_TMR_COUNT_HI);
    } while (hi != hi_again);

    return ((uint64_t)hi << 32) | (uint64_t)lo;
}

static uint64_t cpu1_counts_per_second(void)
{
    /* COUNTS_PER_SECOND expands from the BSP as XPAR_CPU_CORE_CLOCK_FREQ_HZ/2,
     * without protective parentheses. Store it once before using it as a
     * denominator, otherwise `/ (uint64_t)COUNTS_PER_SECOND` is parsed as
     * `/ XPAR_CPU_CORE_CLOCK_FREQ_HZ / 2` and reports one quarter of the real
     * elapsed time. */
    return (uint64_t)COUNTS_PER_SECOND;
}

static void cpu1_emit_status(uint32_t dt_ms)
{
    static uint32_t p_frames, p_gap, p_ovr, p_resync, p_raw, p_recs, p_polls;
    static uint32_t p_bus_writes;
    static uint32_t p_pal_ok, p_pal_drop, p_pal_lines, p_pal_bad, p_pal_ovr;
    static uint32_t p_pal_fast, p_pal_slow, p_pal_ticks;
    static uint32_t p_pal_end_count, p_pal_end_queue, p_pal_end_drained;
    const uint32_t frames = g_acr_frames_complete;
    const uint32_t gap    = g_gap_markers_seen;
    const uint32_t ovr    = g_oversized_drains;
    const uint32_t resync = g_acr_resyncs_cleared;
    const uint32_t raw    = g_acr_frame_edges_seen;
    const uint32_t recs   = g_records_processed;
    const uint32_t polls  = g_poll_calls;
    const uint32_t bus_writes = g_bus_writes_seen;
    const uint32_t pal_ok = g_pal_frames_published;
    const uint32_t pal_drop = g_pal_frames_dropped;
    const uint32_t pal_lines = g_pal_lines_rendered;
    const uint32_t pal_bad = g_pal_lines_incomplete;
    const uint32_t pal_ovr = g_pal_queue_overflows;
    const uint32_t pal_fast = g_pal_fast_lines;
    const uint32_t pal_slow = g_pal_slow_lines;
    const uint32_t pal_ticks = g_pal_render_ticks_total;
    const uint32_t pal_end_count = g_pal_end_frame_count;
    const uint32_t pal_end_queue = g_pal_end_queue_total;
    const uint32_t pal_end_drained = g_pal_end_lines_drained;
    const uint32_t raw_delta = raw - p_raw;
    const uint32_t recs_delta = recs - p_recs;
    const uint32_t pal_ok_delta = pal_ok - p_pal_ok;
    const uint32_t pal_drop_delta = pal_drop - p_pal_drop;
    const uint32_t pal_lines_delta = pal_lines - p_pal_lines;
    const uint32_t pal_ticks_delta = pal_ticks - p_pal_ticks;
    const uint32_t pal_end_count_delta = pal_end_count - p_pal_end_count;
    const uint32_t pal_end_queue_delta = pal_end_queue - p_pal_end_queue;
    const uint64_t ticks_per_second = cpu1_counts_per_second();
    const uint32_t recs_per_frame =
        (raw_delta != 0u) ?
        ((recs_delta + (raw_delta / 2u)) / raw_delta) : 0u;
    const uint32_t pal_avg_us =
        (pal_lines_delta != 0u && ticks_per_second != 0u) ?
        (uint32_t)(((uint64_t)pal_ticks_delta * 1000000ULL) /
                   ticks_per_second /
                   (uint64_t)pal_lines_delta) : 0u;
    const uint32_t pal_max_us =
        (ticks_per_second != 0u) ?
        (uint32_t)(((uint64_t)g_pal_render_ticks_max * 1000000ULL) /
                   ticks_per_second) : 0u;
    const uint32_t pal_end_avg =
        (pal_end_count_delta != 0u) ?
        ((pal_end_queue_delta + (pal_end_count_delta / 2u)) /
         pal_end_count_delta) : 0u;

    uart_puts(UART0_BASE, "[cpu1] dt_ms=");  uart_putdec(UART0_BASE, dt_ms);
    uart_puts(UART0_BASE, " frames=");       uart_putdec(UART0_BASE, frames - p_frames);
    uart_puts(UART0_BASE, " gap=");          uart_putdec(UART0_BASE, gap - p_gap);
    uart_puts(UART0_BASE, " ovr=");          uart_putdec(UART0_BASE, ovr - p_ovr);
    uart_puts(UART0_BASE, " resync=");       uart_putdec(UART0_BASE, resync - p_resync);
    uart_puts(UART0_BASE, " lastrec=");      uart_putdec(UART0_BASE, g_acr_last_frame_records);
    uart_puts(UART0_BASE, " raw=");          uart_putdec(UART0_BASE, raw_delta);
    uart_puts(UART0_BASE, " recpf=");        uart_putdec(UART0_BASE, recs_per_frame);
    uart_puts(UART0_BASE, " recs=");         uart_putdec(UART0_BASE, recs_delta);
    uart_puts(UART0_BASE, " bw=");           uart_putdec(UART0_BASE, bus_writes - p_bus_writes);
    uart_puts(UART0_BASE, " polls=");        uart_putdec(UART0_BASE, polls - p_polls);
    uart_puts(UART0_BASE, " palok=");        uart_putdec(UART0_BASE, pal_ok_delta);
    uart_puts(UART0_BASE, " paldrop=");      uart_putdec(UART0_BASE, pal_drop_delta);
    uart_puts(UART0_BASE, " paltry=");       uart_putdec(UART0_BASE, pal_ok_delta + pal_drop_delta);
    uart_puts(UART0_BASE, " palln=");        uart_putdec(UART0_BASE, pal_lines_delta);
    uart_puts(UART0_BASE, " palbad=");       uart_putdec(UART0_BASE, pal_bad - p_pal_bad);
    uart_puts(UART0_BASE, " palovr=");       uart_putdec(UART0_BASE, pal_ovr - p_pal_ovr);
    uart_puts(UART0_BASE, " palqmax=");      uart_putdec(UART0_BASE, g_pal_queue_max);
    uart_puts(UART0_BASE, " palfast=");      uart_putdec(UART0_BASE, pal_fast - p_pal_fast);
    uart_puts(UART0_BASE, " palslow=");      uart_putdec(UART0_BASE, pal_slow - p_pal_slow);
    uart_puts(UART0_BASE, " palus=");        uart_putdec(UART0_BASE, pal_avg_us);
    uart_puts(UART0_BASE, " palmax=");       uart_putdec(UART0_BASE, pal_max_us);
    uart_puts(UART0_BASE, " palend=");       uart_putdec(UART0_BASE, pal_end_avg);
    uart_puts(UART0_BASE, " palendm=");      uart_putdec(UART0_BASE, g_pal_end_queue_max);
    uart_puts(UART0_BASE, " palfl=");        uart_putdec(UART0_BASE, pal_end_drained - p_pal_end_drained);
    uart_puts(UART0_BASE, "\r\n");

    p_frames = frames; p_gap = gap; p_ovr = ovr;
    p_resync = resync; p_raw = raw; p_recs = recs; p_polls = polls;
    p_bus_writes = bus_writes;
    p_pal_ok = pal_ok; p_pal_drop = pal_drop; p_pal_lines = pal_lines;
    p_pal_bad = pal_bad; p_pal_ovr = pal_ovr;
    p_pal_fast = pal_fast; p_pal_slow = pal_slow; p_pal_ticks = pal_ticks;
    p_pal_end_count = pal_end_count;
    p_pal_end_queue = pal_end_queue;
    p_pal_end_drained = pal_end_drained;
}
#endif

int main(void)
{
    uint8_t reset_seq_last;

    axisimple_mmio_mmu_init();

    /* CPU0 owns UART0 init (921600 baud). We just write to the TX
     * FIFO; do NOT re-run uart_init_baud or we will glitch CPU0's
     * in-flight output. */

    /* Mark the cycle ring + producer-pointer region non-cacheable
     * on CPU1's MMU table. CPU0's apple_cycle_egress_init already
     * did this on its own MMU; CPU1 needs to do it independently
     * or its reads of the producer pointer slot will hit a stale
     * L1 line and never see the PL's writes. */
    apple_cycle_egress_amp_secondary_init();

    /* Initialise the renderer on this core. The egress was already
     * initialised by CPU0 (the PL config registers are write-once
     * at boot), so we do not call apple_cycle_egress_init() here. */
    if (apple_cycle_renderer_init() != 0) {
        uart_puts(UART0_BASE, "core 1: apple_cycle_renderer_init failed\r\n");
        for (;;) { __asm__ volatile ("wfe"); }
    }
    linear_text_overlay_capture_init();

    REG_WRITE(RESET_RELEASE_REG,
              RESET_RELEASE_CPU1_READY_BIT);
    reset_seq_last = (uint8_t)(apple_reset_status_read() &
                               CARD_CTRL_APPLE_RESET_SEQ_MASK);

    /* Tight poll loop. No CPU0 work fights us for the cycles, so
     * we burn the whole core on egress drain + renderer dispatch.
     * The renderer's cost scales with Apple bus rate (~1 MHz);
     * drain cost is dominated by the per-record dispatch cycle
     * count, well within a 666 MHz A9's budget. */
#if CPU1_STATUS_UART
    /* The once-per-loop timer read is cheap relative to a drain pass, and the
     * whole block compiles out with CPU1_STATUS_UART=0. */
    uint64_t status_last = global_timer_read();
    uart_puts(UART0_BASE,
        "[cpu1] health line armed: per-1s deltas; gap/ovr/resync should stay 0,"
        " frames ~= line rate\r\n");
#endif
    for (;;) {
        const uint32_t apple_status = apple_reset_status_read();
        const uint8_t reset_seq =
            (uint8_t)(apple_status & CARD_CTRL_APPLE_RESET_SEQ_MASK);
        if (reset_seq != reset_seq_last) {
            reset_seq_last = reset_seq;
            apple_cycle_renderer_reset_local_video_state();
        }
        apple_cycle_renderer_set_vtw_1mhz(
            (apple_status & CARD_CTRL_APPLE_RESET_VTW_1MHZ_BIT) != 0U);
        apple_cycle_renderer_sync_shr_mode(
            (apple_status & CARD_CTRL_APPLE_RESET_SHR_ACTIVE_BIT) != 0U);
        linear_text_overlay_capture_poll();
        apple_cycle_egress_poll();

        /* Diagnostic shadow-dump request from CPU0's UART console.
         * Costs one strongly-ordered OCM read per pass when idle;
         * emits at most one dump line per pass when active. */
        cpu1_dump_text_shadow_step();

        /* Render queued PAL lines off the drain path. The drain (above) only
         * buffers; this does the heavy per-line work, bounded per call so the
         * loop returns to drain the capture ring before it can back up. No-op
         * in every non-PAL-accurate mode. */
        apple_pal_video_pump();

#if CPU1_STATUS_UART
        const uint64_t ticks_per_second = cpu1_counts_per_second();
        if (ticks_per_second != 0U) {
            const uint64_t status_now = global_timer_read();
            if ((status_now - status_last) >= ticks_per_second) {
                const uint32_t dt_ms = (uint32_t)(((status_now - status_last) *
                                                   1000ULL) /
                                                  ticks_per_second);
                cpu1_emit_status(dt_ms);
                status_last = status_now;
            }
        }
#endif
    }
    return 0;
}

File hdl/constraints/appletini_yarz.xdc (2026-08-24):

################################################################################
# Appletini One Pin Constraints
#
# Xilinx Zynq-7020 CLG484 Package
# Apple //e Expansion Card - Multi-Card Emulator
#
# Generated from: Xilinx_Zynq-7020_FormalTruthTable.csv
# Device: xc7z020clg484-1
#
# Note: PS pins (MIO, DDR) are configured by the Zynq PS IP and should not
# be constrained here. Only PL (Programmable Logic) pins are constrained.
################################################################################

################################################################################
# Apple //e Bus Interface - Bank 33
# All signals interface via level translators (bidirectional) or open-collector
################################################################################

## Apple //e Control Signals - Assert (Output from FPGA)
set_property PACKAGE_PIN U19 [get_ports a2ctrl_irq_n]
set_property IOSTANDARD LVCMOS33 [get_ports a2ctrl_irq_n]

set_property PACKAGE_PIN T21 [get_ports a2ctrl_nmi_n]
set_property IOSTANDARD LVCMOS33 [get_ports a2ctrl_nmi_n]

set_property PACKAGE_PIN U21 [get_ports a2ctrl_rdy_n]
set_property IOSTANDARD LVCMOS33 [get_ports a2ctrl_rdy_n]

set_property PACKAGE_PIN T22 [get_ports a2ctrl_dma_n]
set_property IOSTANDARD LVCMOS33 [get_ports a2ctrl_dma_n]

set_property PACKAGE_PIN W22 [get_ports a2ctrl_inh_n]
set_property IOSTANDARD LVCMOS33 [get_ports a2ctrl_inh_n]

set_property PACKAGE_PIN W20 [get_ports a2ctrl_reset_n]
set_property IOSTANDARD LVCMOS33 [get_ports a2ctrl_reset_n]

## Apple //e Control Signals - Observe (Input to FPGA)
set_property PACKAGE_PIN U22 [get_ports a2fpga_dma_n]
set_property -dict {IOSTANDARD LVCMOS33 PULLTYPE PULLUP} \
    [get_ports a2fpga_dma_n]

set_property PACKAGE_PIN V22 [get_ports a2fpga_rdy_n]
set_property -dict {IOSTANDARD LVCMOS33 PULLTYPE PULLUP} \
    [get_ports a2fpga_rdy_n]

set_property PACKAGE_PIN W21 [get_ports a2fpga_inh_n]
set_property -dict {IOSTANDARD LVCMOS33 PULLTYPE PULLUP} \
    [get_ports a2fpga_inh_n]

set_property PACKAGE_PIN U20 [get_ports a2fpga_nmi_n]
set_property -dict {IOSTANDARD LVCMOS33 PULLTYPE PULLUP} \
    [get_ports a2fpga_nmi_n]

set_property PACKAGE_PIN V20 [get_ports a2fpga_reset_n]
set_property -dict {IOSTANDARD LVCMOS33 PULLTYPE PULLUP} \
    [get_ports a2fpga_reset_n]

set_property PACKAGE_PIN V19 [get_ports a2fpga_irq_n]
set_property -dict {IOSTANDARD LVCMOS33 DRIVE 16 SLEW FAST PULLTYPE PULLUP} \
    [get_ports a2fpga_irq_n]

## Apple //e Bus Transceiver Control
set_property PACKAGE_PIN V18 [get_ports a2fpga_oe_n]
set_property IOSTANDARD LVCMOS33 [get_ports a2fpga_oe_n]

set_property PACKAGE_PIN Y20 [get_ports a2fpga_oe_n_aux]
set_property IOSTANDARD LVCMOS33 [get_ports a2fpga_oe_n_aux]

set_property PACKAGE_PIN U17 [get_ports a2fpga_dir_a]
set_property -dict {IOSTANDARD LVCMOS33 DRIVE 12 SLEW FAST} \
    [get_ports a2fpga_dir_a]

set_property PACKAGE_PIN V17 [get_ports a2fpga_dir_d]
# DIR_D closes the data-drive window from raw PHI0. Keep its current 12 mA
# drive and use the fast output edge to cut the pad delay on that release.
set_property -dict {IOSTANDARD LVCMOS33 DRIVE 12 SLEW FAST} \
    [get_ports a2fpga_dir_d]

## Apple //e Address Bus (Bidirectional)
set_property PACKAGE_PIN AA13 [get_ports {a2fpga_a[0]}]
set_property IOSTANDARD LVCMOS33 [get_ports {a2fpga_a[0]}]

set_property PACKAGE_PIN AB14 [get_ports {a2fpga_a[1]}]
set_property IOSTANDARD LVCMOS33 [get_ports {a2fpga_a[1]}]

set_property PACKAGE_PIN AA14 [get_ports {a2fpga_a[2]}]
set_property IOSTANDARD LVCMOS33 [get_ports {a2fpga_a[2]}]

set_property PACKAGE_PIN AB15 [get_ports {a2fpga_a[3]}]
set_property IOSTANDARD LVCMOS33 [get_ports {a2fpga_a[3]}]

set_property PACKAGE_PIN AB16 [get_ports {a2fpga_a[4]}]
set_property IOSTANDARD LVCMOS33 [get_ports {a2fpga_a[4]}]

set_property PACKAGE_PIN AA16 [get_ports {a2fpga_a[5]}]
set_property IOSTANDARD LVCMOS33 [get_ports {a2fpga_a[5]}]

set_property PACKAGE_PIN Y16 [get_ports {a2fpga_a[6]}]
set_property IOSTANDARD LVCMOS33 [get_ports {a2fpga_a[6]}]

set_property PACKAGE_PIN Y15 [get_ports {a2fpga_a[7]}]
set_property IOSTANDARD LVCMOS33 [get_ports {a2fpga_a[7]}]

set_property PACKAGE_PIN Y19 [get_ports {a2fpga_a[8]}]
set_property IOSTANDARD LVCMOS33 [get_ports {a2fpga_a[8]}]

set_property PACKAGE_PIN AB19 [get_ports {a2fpga_a[9]}]
set_property IOSTANDARD LVCMOS33 [get_ports {a2fpga_a[9]}]

set_property PACKAGE_PIN AA19 [get_ports {a2fpga_a[10]}]
set_property IOSTANDARD LVCMOS33 [get_ports {a2fpga_a[10]}]

set_property PACKAGE_PIN AB20 [get_ports {a2fpga_a[11]}]
set_property IOSTANDARD LVCMOS33 [get_ports {a2fpga_a[11]}]

set_property PACKAGE_PIN AB21 [get_ports {a2fpga_a[12]}]
set_property IOSTANDARD LVCMOS33 [get_ports {a2fpga_a[12]}]

set_property PACKAGE_PIN AB22 [get_ports {a2fpga_a[13]}]
set_property IOSTANDARD LVCMOS33 [get_ports {a2fpga_a[13]}]

set_property PACKAGE_PIN AA21 [get_ports {a2fpga_a[14]}]
set_property IOSTANDARD LVCMOS33 [get_ports {a2fpga_a[14]}]
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

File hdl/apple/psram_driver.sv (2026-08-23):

`timescale 1ns / 1ps

module psram_driver (
    input  logic        clk,
    input  logic        resetn,

    // Ready/valid command interface.
    //   valid: master asserts when cmd/addr/wdata is presented.
    //   ready: driver asserts when it can accept a new command.
    //   Transfer occurs on the posedge where both valid and ready are high;
    //   cmd/addr/wdata are sampled into internal registers that cycle and
    //   may then change.
    input  logic        valid,
    output logic        ready,
    input  logic [7:0]  cmd,
    input  logic [23:0] addr,
    input  logic [63:0] wdata,

    // Response. rvalid pulses high for one cycle when rdata is meaningful
    // for the most recently accepted command; master should sample rdata
    // that cycle. For commands without read data, rvalid still pulses to
    // signal completion and rdata is don't-care.
    output logic        rvalid,
    output logic [63:0] rdata,
    output logic        done,

    // Capture tuning
    input  logic        dcount_wr_en,
    input  logic [4:0]  dcount_wr,
    input  logic        dcount_edge,

    // spi pins
    output logic [3:0] psram_oe,
    input  logic [3:0]  psram_a_i,
    output logic [3:0] psram_a_o,
    input  logic [3:0]  psram_b_i,
    output logic [3:0] psram_b_o,
    output logic      psram_ce_n,
    output logic       psram_clk
);

    logic is_quad;
    logic [31:0] sh_ce_n_tape;
    logic [31:0] sh_clken_tape;
    logic [31:0] sh_oe_tape;
    logic [31:0] sh_rd_en_tape;
    logic [63:0] sh_wr_a_tape; // includes cmd+address
    logic [63:0] sh_wr_b_tape;

    logic phy_active;
    
    assign phy_active = sh_clken_tape[31];

    // ------------------------------------------------------------------------
    // Forwarded clock
    // ------------------------------------------------------------------------
    logic psram_clk_oddr;

    ODDR #(
        .DDR_CLK_EDGE("SAME_EDGE"),
        .INIT(1'b0),
        .SRTYPE("ASYNC")
    ) psram_clk_oddr_i (
        .Q (psram_clk_oddr),
        .C (clk),
        .CE(1),
        .D1(1'b1),
        .D2(1'b0),
        .R (~phy_active),
        .S (1'b0)
    );

    localparam IDLE = 1'b0;
    localparam BUSY = 1'b1;

    logic state = IDLE;

    logic start_pulse;
    logic prev_ce_n;
    logic [2:0] ce_rest_cycles;
    logic [63:0] read_shift_q;
    logic launch_quad_q;
    logic launch_quad_d;

    // Prepare the exact values that the falling-edge IOB registers must
    // launch after the current rising edge.  These registers cut the short
    // half-cycle path from the wide tape shifters and mode mux to the pins.
    (* KEEP = "TRUE", DONT_TOUCH = "TRUE" *) logic [3:0] psram_oe_launch_q;
    (* KEEP = "TRUE", DONT_TOUCH = "TRUE" *) logic [3:0] psram_a_launch_q;
    (* KEEP = "TRUE", DONT_TOUCH = "TRUE" *) logic [3:0] psram_b_launch_q;

    logic [31:0] sh_oe_tape_d;
    logic [63:0] sh_wr_a_tape_d;
    logic [63:0] sh_wr_b_tape_d;

    // Registered command captured on the cycle of valid && ready. The
    // master is then free to change the inputs.
    logic [7:0]  cmd_q;
    logic [23:0] addr_q;
    logic [63:0] wdata_q;

    localparam ENTER_QPI    = 8'h35; // CMD_S template
    localparam RESET_ENABLE = 8'h66; // CMD_Q template
    localparam RESET        = 8'h99; // CMD_Q template
    localparam TOGGLE_WRAP  = 8'hC0; // CMD_Q template
    // In QPI mode the Lyontek write command is 0x02; 0x38 is the SPI-mode
    // quad-write variant.  Using 0x38 on the active QPI path can leave reads
    // working while writes fail to stick.
    localparam QPI_WRITE    = 8'h02; // QPIW_QUAD template
    localparam QPI_READ     = 8'hEB; // QPIR_QUAD template

    localparam CMD_S_QUAD = 1'b0;
    localparam CMD_Q_QUAD = 1'b1;
    localparam QPIW_QUAD  = 1'b1;
    localparam QPIR_QUAD  = 1'b1;

    // Op-completion detection. The "operation finished its useful work"
    // moment is *not* the CE-high transition — that's just the chip's
    // tCEH boundary that gates the next command. The actual data-valid
    // moment for a read is when RD_EN drops (read_shift_q is fully
    // populated); for writes/cmds it's when CLKEN drops (no more SCK
    // edges → the slave has latched everything we sent). Pulsing rvalid
    // at op-done, and gating `ready` separately on the CE-high tail,
    // decouples per-op latency from back-to-back throttling.
    logic prev_clken_q;
    logic prev_rd_en_q;
    wire  rd_en_drop = prev_rd_en_q && !sh_rd_en_tape[31];
    wire  clken_drop = prev_clken_q && !sh_clken_tape[31];
    wire  op_done    = (state == BUSY) &&
                       ((cmd_q == QPI_READ) ? rd_en_drop : clken_drop);

    // Gate ready on !rvalid: the cycle rvalid pulses, the master may still
    // be holding valid (it sees rvalid that cycle and drops valid the next),
    // and we must not re-accept the stale valid as a new command.
    // ce_rest_cycles holds ready low while the CE-high tail is in flight.
    assign ready = (state == IDLE) && (ce_rest_cycles == 0) && !rvalid;

    always_comb begin
        launch_quad_d = launch_quad_q;
        if ((state == IDLE) && valid && ready) begin
            unique case (cmd)
                ENTER_QPI:    launch_quad_d = CMD_S_QUAD;
                RESET_ENABLE,
                RESET,
                TOGGLE_WRAP:  launch_quad_d = CMD_Q_QUAD;
                QPI_WRITE:    launch_quad_d = QPIW_QUAD;
                QPI_READ:     launch_quad_d = QPIR_QUAD;
                default:      launch_quad_d = is_quad;
            endcase
        end
    end
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

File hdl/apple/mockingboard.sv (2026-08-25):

`timescale 1ns / 1ps

// Applied Engineering Phasor-compatible sound card.
//
// The card resets into Mockingboard-compatible mode: two 6522 VIAs, each
// driving one AY-3-8913-compatible PSG. Phasor native mode is selected through
// the Phasor C0nX mode switch and adds a second AY behind each VIA. In native
// mode VIA ORB bit 4 selects the primary AY and bit 3 selects the secondary AY;
// both chip selects are active-low, matching the Phasor GAL behavior documented
// by AppleWin. Two fixed SSI-263AP sockets provide native speech on A5 and A6.
module mockingboard(
    input clk,
    input rstn,
    input logic apple_q3_raw,
    input globals::AppleBus_read ab_read,
    input globals::SoftSwitchState sss,
    input logic [2:0] slot_assign,
    input logic card_enable,
    input logic [47:0] pan,
    input logic [31:0] audio_control,
    input logic audio_sample_tick,
    output globals::AppleBus_write ab_write,
    output logic signed [15:0] audio_l,
    output logic signed [15:0] audio_r,
    // Debug taps for the speech-completion IRQ chain (freeze diagnosis):
    // combined across both SSI-263 voices.
    output logic dbg_ssi_irq,
    output logic dbg_ssi_backend_done,
    output logic dbg_ssi_enable_ints
);

localparam logic [2:0] PH_MOCKINGBOARD = 3'd0;
localparam logic [2:0] PH_PHASOR       = 3'd5;
localparam logic [2:0] PH_ECHOPLUS     = 3'd7;
// MODE=1 selects the AY8910/AY8913 16-level output table; MODE=0 selects
// the YM2149 table. The PS menu drives this through audio_control bit 25.
wire psg_volume_mode_ay8913 = audio_control[25];
// audio_control bit 26: lock the card to Mockingboard-compatible mode. When
// set, the Apple-bus $C0nX Phasor mode switch is ignored entirely so software
// can never detect or enable Phasor-native / Echo+ behavior.
wire mockingboard_only = audio_control[26];

globals::AppleBus_write ab_write_q = 0;

logic [2:0] phasor_mode_q = PH_MOCKINGBOARD;
logic psg_ce_extra_q = 1'b0;

wire card_enabled = card_enable && (slot_assign != 3'd0);
wire mockingboard_mode = (phasor_mode_q == PH_MOCKINGBOARD);
wire phasor_native = (phasor_mode_q == PH_PHASOR);
wire echo_plus = (phasor_mode_q == PH_ECHOPLUS);
wire phasor_extended = phasor_native || echo_plus;
wire ssi_visible_mode = mockingboard_mode || phasor_native;
wire [3:0] phasor_mode_nibble = {1'b1, slot_assign};
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

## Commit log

2026-07-14 Fixed disk2 track load FAILED error when no disk is in drive, or controller card disabled.
    [main.c]
2026-07-15 Added schematics
2026-07-17 Changed base bus sampling to be much later, at phi+90ns, to support TransWarp and other accelerators. INH sampling still necessary at early stages.
2026-07-28 Add virtual TransWarp and extended video support
    Implement a synthesizable W65C02 core, virtual TransWarp bus engine, shadow memory, and PS control service with selectable speeds through 26 MHz, programmable peripheral slowdowns, boot/reset handoff, floating-bus support, and enforced 1 MHz Disk II access.
    Rework Apple bus capture and peripheral timing for native and accelerated paths. Correct VBL and video phase alignment, scanline cadence, SmartPort reset and boot routing, II/II+ read sampling, Mockingboard and Phasor VIA/SSI263 behavior, mouse IRQ handling, and compatibility with physical cards.
    Expand the renderer and VidHD path for SHR, SHR4, SHR-3200, PAL fallback, interlace, determin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
    [apple_bus_wrapper.sv, apple_top.sv, appletini_yarz.xdc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]
2026-08-01 Harden II+ acceleration and virtual peripheral emulation
    - Harden vTW on II/II+ with raw-PHI0 data release, inert bus parking, reset-safe posted-cycle cancellation, permanent II+-only DMA refresh, internal IRQ merging, Apple-key and ROM reset fixes, cold-menu handoff fixes, passive traces, and constrained critical paths.
    - Route virtual-card resets through the dedicated open-collector driver and re-arm persistent II+ IRQ assertions with brief high-Z notches while preserving the //e level path.
    - Rebuild the MouseCard ROM from source and match Apple firmware and AppleWin behavior for 16-bit positions and clamps, INIT/GetClamp, VBL and movement causes, acknowledgements, mode changes, and USB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
    [apple_bus_wrapper.sv, apple_top.sv, appletini_yarz.xdc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]
2026-08-03 Open the vTW wide posting window from the captured paged-mode ctrl
    Under vTW, main $6000-$9FFF writes are posted to the capture only
    while the wide window is open, and only a rendered interlaced SHR
    frame ever opened it. A loader that holds SHR off while loading
    could therefore stream a second interlace field into main RAM with
    the window shut: the field reached real memory but never the CPU1
    mirror, and the renderer showed whatever the mirror last captured
    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
2026-08-03 Add interlaced video modes and display effects
    Add SHR4, SHR-3200, HGRi, and DHRi rendering with paged weave or field merge, detailed format metadata, and generation-based SHR caching. Keep accelerated interlaced captures coherent by opening the vTW wide posting window from the private aux control write.
    Add phosphor blur and glow, refine ghosting and compositor handoff, restore the expanded Video-tab layout, and synchronize UART help. Replace SHRVIEW with A2IMGVIEW, package the new demo and test images, add host-render and RTL regressions, and release firmware F0.9.50.
    [apple_top.sv, main.c]
2026-08-03 Fix IIgs border compositing
    Draw the IIgs border around both legacy and SHR frames, keep the video-mode badge anchored to the active image, and prevent hidden disk activity cleanup from cutting a black rectangle into legacy borders. Extend the regressions and package the validated changes as firmware F0.9.52.
    [main.c]
2026-08-06 Accelerate SmartPort transfers under vTW
    Add direct shadow-memory and PS DMA paths for accelerated SmartPort reads and writes, with MMU-aware mapping, bounded core holds, RamWorks cache flushes, posted-write credit handling, and safe fallback.
    Improve cache-hit dispatch, cache coherence, video quiesce and publish ordering, and DMA abort recovery. Fix Video-7 mode selection and update the demo image support.
    Refactor PSRAM forwarding and cycle-egress ring guards for timing, add focused RTL and source tests, and package firmware F0.9.66. Validated in hardware after a full non-incremental Vivado and Vitis build.
    [apple_top.sv, main.c, psram_simple.sv]
2026-08-08 Accelerate Disk II reads under vTW
    Add a private virtual Disk II read path paced by accelerated CPU cycles while keeping writes on the physical 1 MHz path.
    Add controls for the C074 speed switch and Disk II acceleration, compact the TransWarp slowdown UI, ease the affected timing paths, and update the documentation and regression tests.
    Package firmware F0.9.67.
2026-08-09 Add virtual ALF AD8088 Plus support
    Add a selectable slot 5 AD8088 Plus with an 8088 core, 640K and AD128K-compatible memory, monitor service, UI integration, documentation, and test media.
    Use sequenced four-byte Apple-bus DMA bursts with parked acquisition and release cycles, retryable ownership stalls, reset and abort recovery, ghost-write checks, paddle timing support, and UART diagnostics.
    Add focused source and RTL regressions and package the hardware-tested F0.9.70 firmware sources. The full non-incremental build passed timing at WNS +0.020 ns, WHS +0.059 ns, and WPWS +0.265 ns.
    [apple_bus_wrapper.sv, apple_bus_write_arbiter.sv, apple_top.sv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]
2026-08-09 Fix posted motherboard write timing
    Arm the early DMA data window for posted RAM writes so motherboard DRAM sees stable data before CAS. Keep synchronous slot and soft-switch writes on the normal late window, and extend the vTW unit test to pin both cases.
2026-08-09 Keep frontend services live during USB waits
    Yield from CherryUSB reset, debounce, and transfer waits so USB0 storage, SmartPort, Disk II, and video keep moving. Guard recursive USB1 entry and defer compositor work until initialization completes.
    [main.c]
2026-08-09 Correct per-switch video phase
    Apply the measured scanner phase separately for TEXT, MIXED, 80COL, DHIRES, and ALTCHAR without moving the raw VBL lock. Feed the renderer two future switch snapshots while preserving video-memory order, and cache ring records in batches to avoid the HGR frame-rate loss caused by repeated non-cacheable DDR reads. Extend the host phase and pixel tests and package firmware F0.9.74.
2026-08-09 Add virtual Super Serial Card in slot 1
    The SSC shares slot 1 with the Uthernet II: the Uthernet decode narrows
    to its real $C0n4-$C0n7 registers, and the new ssc_card serves the 1981
    Apple SSC firmware (slot page + 2 KB $C800 ROM), DIP switches hardwired
    to printer mode, an always-ready 6551, and a 2 KB printer FIFO drained
    through new card-control registers. The ROM builds from the a2retronet
    source split with the banked SmartPort entries stubbed out; layout
    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
2026-08-09 Add ImageWriter printer service and Printing tab
    The printer service drains the SSC FIFO each main-loop pass, feeds an
    ImageWriter II interpreter (draft text in every pitch, bold, underline,
    half-height, scripts, double width, ESC G/g/V graphics, spacing and form
    controls), and writes each page as a grayscale PNG to 0:/printouts with
    sequential names. A job closes five idle seconds after the last byte and
    flushes its partial page.
    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
2026-08-10 Add color ImageWriter output
    Render ImageWriter II four-color ribbon commands into RGB PNG files, preserve overprinted ink mixes, and show a PAGE PRINTED confirmation overlay. Enable PNG encoding, document printer use, and exten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
2026-08-10 Make video switch phase easy to tune
    Restore native timing for C050, C00D, C00F, and C05E while retaining the one-cycle C052 delay. Replace hand-built masks with a checked per-switch tuning table and update the renderer regressions.
2026-08-10 Harden firmware build checks
    Verify each Vitis ELF, run one guarded post-route physical optimization pass when a full build narrowly misses setup timing, and document the timing-clean full-build flow. Package the validated chang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
2026-08-18 Implement linear text overlay (#2)
    Add the slot-7 linear text overlay RTL and PS services.
    Add VT/ANSI and CP437 font rendering.
    Add the Apple II demo, generated demo disk, tests, and interface updates.
    Include the Terminus bitmap font sources and license.
2026-08-18 Add standalone ONE//e mode (#3)
    Add standalone ONE//e execution with virtual motherboard bus, safety guards, cold boot, warm reset, and storage ownership.
    Add ONE//e video-standard, speaker, input, keyboard-repeat, and speed controls.
    Add USB keyboard, mouse, joystick, and menu routing for standalone mode.
    Keep RESET as Ctrl+Alt+Delete, Open Apple as Left Alt, Closed Apple as Right Alt, and MENU as Pause/Break plus long OK.
    Keep all other saved bindings editable and active in ONE//e mode.
    Add focused RTL, source, menu, runtime, and hardware-test coverage.
    [apple_bus_wrapper.sv, apple_top.sv, apple_virtual_bus.sv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]
2026-08-18 Add exclusive SD card FTP sharing (#5)
    Add anonymous read/write FTP sharing for SD-card contents.
    Accept control connections only from the configured local subnet.
    Use passive FTP data connections with directory listing, download, upload, rename, delete, and directory operations.
    Give FTP exclusive SD-card and Ethernet ownership while active, then restore card services on exit.
    Add the Ethernet-tab sharing flow, ONE//e boot-menu bypass, and UART start/stop controls.
    Add the reliable W5100S transfer path and long-transfer integrity checks.
2026-08-21 Apply code review fixes
    Fix bus and data isolation, ONE//e state handling, networking, safety, tooling, and tests. Bump the firmware version to F0.9.98.
    [apple_top.sv, appletini_yarz.xdc, linear_text_overlay_card.sv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]
2026-08-23 Correct SC-02 source clocking
    [ssi263_sc02_core.sv]
2026-08-23 Implement SC-02 excitation and filters
2026-08-23 Cut remaining release timing paths
2026-08-24 Cut remaining sub-margin timing paths
2026-08-24 Cut final Uthernet and Phasor timing paths
2026-08-24 Fix SSI-263 speech output
    [ssi263_sc02_core.sv]
2026-08-24 Record SSI-263 pitch firmware
2026-08-24 Implement schematic SSI-263 charge model
2026-08-24 Correct SSI-263 schematic clock edges
    [ssi263_sc02_core.sv]
2026-08-24 Follow SSI-263 excitation circuit
2026-08-24 Implement exact SSI-263 charge engine
2026-08-24 Correct SSI-263 PW3 latch polarity
    [ssi263_sc02_core.sv]
2026-08-24 Verify original dual SSI-263 Phasor wiring
2026-08-25 Correct SSI-263 selector cadence
    [ssi263_sc02_core.sv]
2026-08-25 Correct SSI-263 U37 clock edge
    [ssi263_sc02_core.sv]
2026-08-25 Implement SSI-263 transition circuit
2026-08-25 Document final SSI-263 schematic model
2026-08-25 Calibrate SSI-263 voice and card gain
2026-08-25 Document SSI-263 output calibration
2026-08-25 Fix SSI-263 PW3 load gate
    [ssi263_sc02_core.sv]
2026-08-25 Fix SSI-263 cold-start pitch state
    [ssi263_sc02_core.sv]
2026-08-25 Record SSI-263 cold-pitch firmware
2026-08-26 Archive SC-02 prototype schematic
2026-08-26 Add SC-02 schematic archive tools
2026-08-26 Generate SC-02 text schematic archive
    [sc02_pin_net_memberships.csv, sc02_prototype.kicad_sch, sc02_sheet_01_analog_1_schdoc.kicad_sch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]
